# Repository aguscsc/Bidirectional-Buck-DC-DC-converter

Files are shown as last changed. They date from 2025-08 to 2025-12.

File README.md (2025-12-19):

# Bidirectional Buck DC-DC Converter

This repository documents the design and implementation of a **bidirectional DC-DC converter**.  
The system can operate in both **buck mode** (step-down) and **boost mode** (step-up), enabling power flow in both directions.  

---
## Software used
- **Simulation**
  
   Multisim, Ltspice and MATLAB/Simulink
   coil64
- **PCB**
  
   Kicad
## 📐 Specifications
- **Switching frequency**: 60 kHz  
- **Maximum power**: 5 W  

### Buck Mode
- $V_{in, min} = 23V$  
- $V_{out, max} = 14V$  

### Boost Mode
- $V_{in, min} = 12V$  
- $V_{out, max} = 27V$  

---

## 🔌 Topology
The selected topology is based on a **bidirectional synchronous buck/boost converter**.  
Diagram (preliminary):  

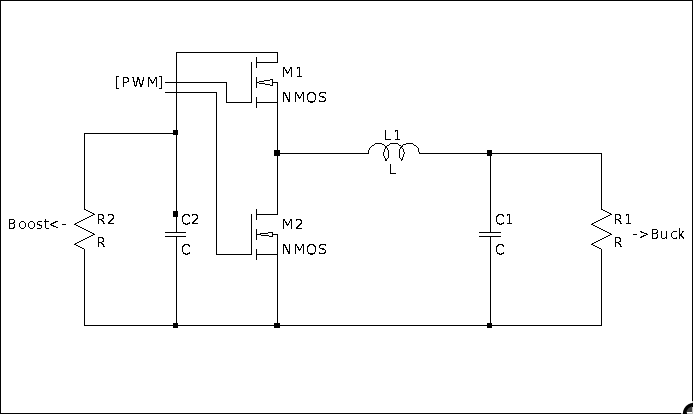
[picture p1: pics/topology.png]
Topology


---

## 📊 Design Parameters
### Inductor
- To be dimensioned based on:  
 $L = \frac{V_L \cdot D}{\Delta I_L \cdot f_s}$
  where:
  - \( $V_L$ \) = inductor voltage  
  - \( $D$ \) = duty cycle  
  - \( $\Delta I_L$ \) = current ripple (≈ $30$% of \( $I_{L,max}$ \))  
  - \( $f_s$ \) = switching frequency
  
   $I_{sat} = \frac{B_{sat}\cdot l}{\mu_{0}\cdot \mu_{r}\cdot N}$
  Where:
  - \($I_{sat}$\) = Saturation current
  - \($B_{sat}$\) = saturation flux density of the core material
  - \($l$\) = effective magnetic path length of the core
  - \($\mu_{0}$\) = permeability of a vacuum
  - \($\mu_{r}$\) = relative permeability of the material
  - \($N$\) = number of turns

Recommendation: use coil64 to check your calculations, research skin effect and how different AWG interact with the frequency you're using (https://en.wikipedia.org/wiki/Skin_effect).
### Capacitor
- To be dimensioned from capacitor current balance:
- buck
  $C = \frac{\Delta I_L}{\Delta V \cdot f_s\cdot 8}$
- boost
  $C = \frac{I_{out} \cdot D}{\Delta V \cdot f_s}$
  
  where:
  - \( $\Delta V$ \) = allowed voltage ripple  

## Schematic & PCB layout
<p>
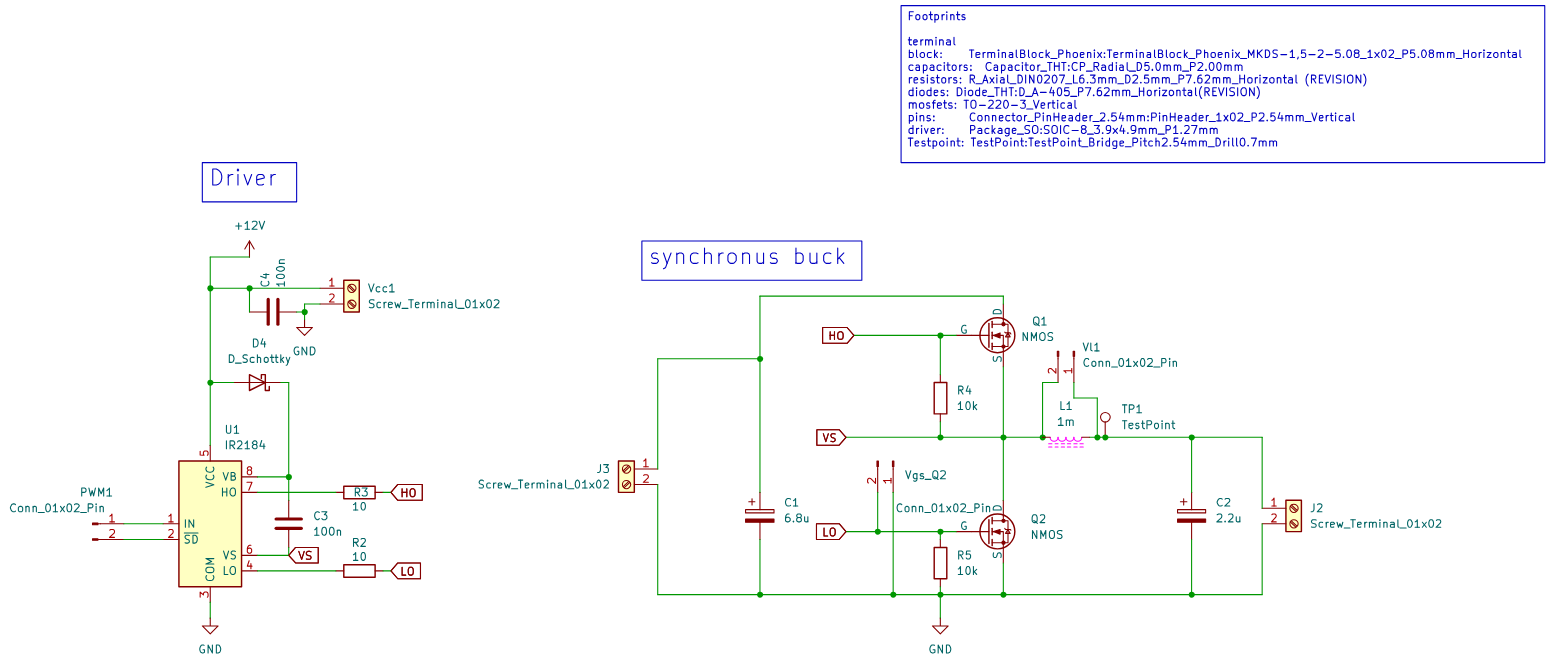
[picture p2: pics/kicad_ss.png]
schematic
  
</p>

<p>
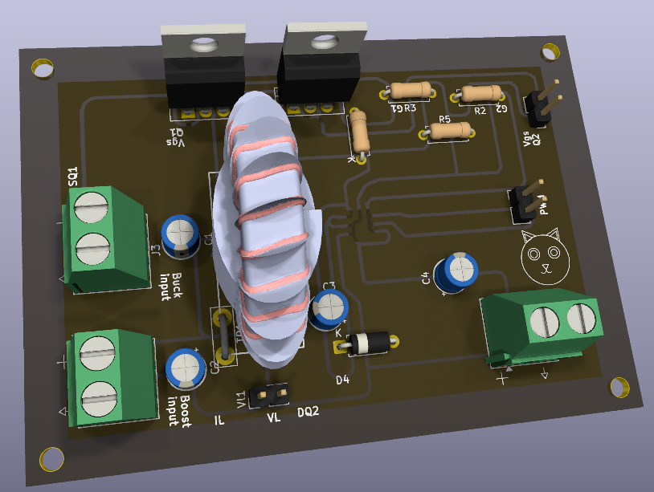
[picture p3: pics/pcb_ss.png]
PCB
  
</p>

---
# Prototyping 
This section breaks down the process of prototyping and testing, the pcb in the design directory contains all the measures necessary to ensure the converter is working properly (value of components can be adjusted to your needs).
## BOM:
- 2 electrolytic capacitors $6.8\mu F$ and $2.2\mu F$ 50V each. 
- 2 ceramic capacitors (100nF).
- core T106-26 + 9m of AWG 26 wire (higher permeability would also work if the saturation stays sensible).
- 2 IFRZ44N (great for prototyping and testing)
- IR2184 driver (it can generate both MOSFET signals)
- 2 10 ohm gate resistors 1W (it limits the gate current)
- 2 10k ohm pull-down resistor 1W (drains the gate source capacitance)
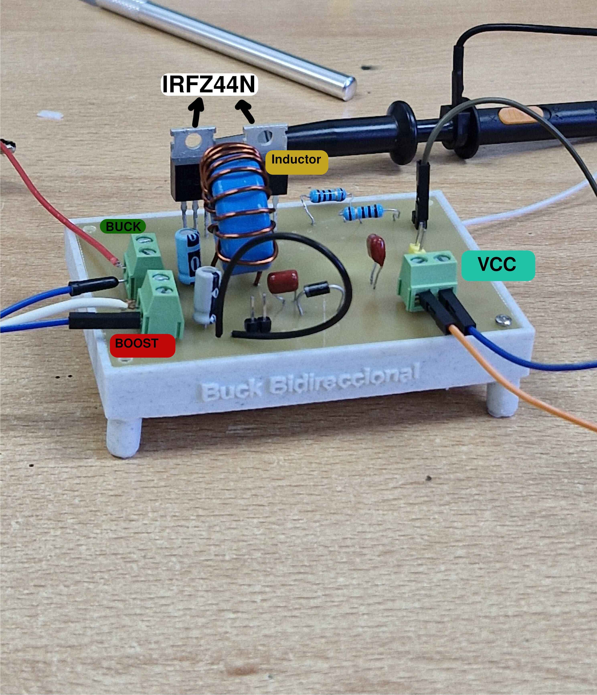
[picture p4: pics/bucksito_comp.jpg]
Prototype
 
## Measurements and tests
### switching
First, you ought to make sure the MOSFET are switching correctly. For this, turn on the pwm signal and your VCC source, then measure the gate-source pins of each MOSFET with an oscilloscope and make sure the signals are the complement of each other and respond to the change in duty. Aditionally, you should measure the gate current to ensure it is not exceeding the drivers capacity.
<p>
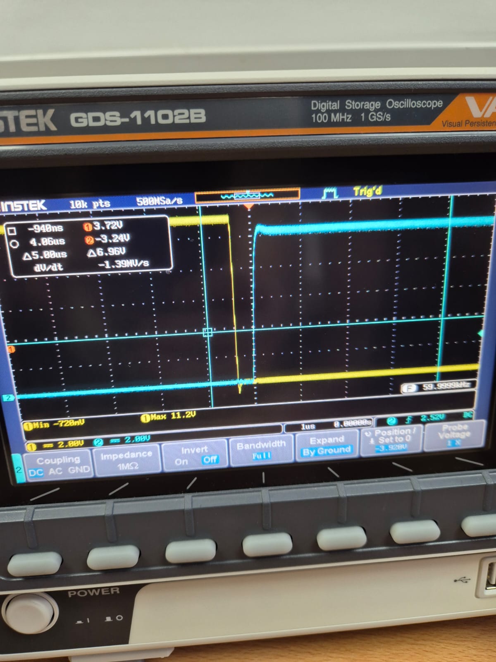
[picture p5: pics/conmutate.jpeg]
switching
  
</p>

### Powering the circuit
Check the waveforms of the inductor current and output voltage, ideally you should be looking at two saw-like waves with minimal ripple.
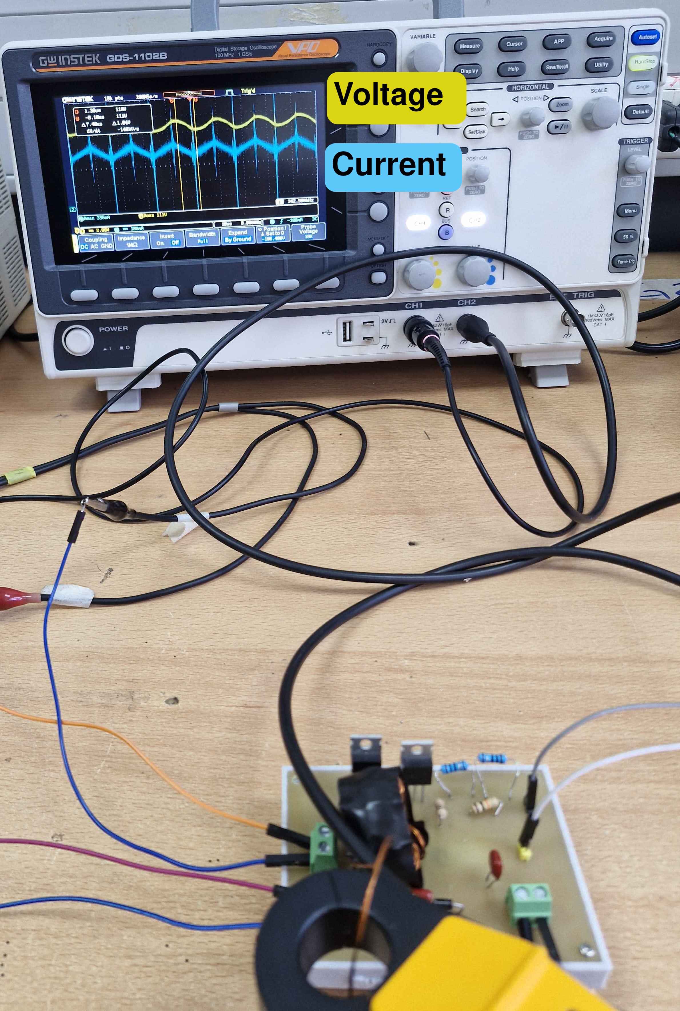
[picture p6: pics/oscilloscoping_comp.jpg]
testing

Once you have ensured the inductor current and the output voltage have satisfied your needs you can proceed to measure the converters effiency for each mode.

Note: if you struggle achieving the voltage ripple required, considering soldering ceramic capacitors parallel to your current ones.
### Efficiency 
**BUCK** R = $39.8$

| Duty | $V_{in}$ | $I_{in}$ | $V_{out}$ | $P_{in}$ | $P_{out}$ | Efficiency |
|:----:|:---:|:---:|:---:|:---:|:---:|:---:|
| 35%  | 23 V | 0.06 A | 7.26 V | 1.38 W | 1.32 W | 96.4 % |
| 45%  | 23 V | 0.10 A | 9.45 V | 2.30 W | 2.24 W | 97.5 % |
| 55%  | 23 V | 0.16 A | 11.6 V | 3.68 W | 3.38 W | 91.8 % |
| 65%  | 23 V | 0.22 A | 13.78 V | 5.06 W | 4.77 W | 94.3 % |

**BOOST** R = $142.2$

| Duty | $V_{in}$ | $I_{in}$ | $V_{out}$ | $P_{in}$ | $P_{out}$ | Efficiency |
|:----:|:---:|:---:|:---:|:---:|:---:|:---:|
| 29.5%  | 12 V | 0.16 A | 16.34 V | 1.92 W | 1.87 W | 97.7 % |
| 39.5%  | 12 V | 0.21 A | 18.79 V | 2.52 W | 2.48 W | 98.5 % |
| 49.5%  | 12 V | 0.30 A | 22.11 V | 3.60 W | 3.43 W | 95.4 % |
| 59.5%  | 12 V | 0.46 A | 26.77 V | 5.52 W | 5.04 W | 91.3 % |

# PWM control
Previously, the pwm signal was generated with a waveform generator, for real applications this has to be implemented with a microcontroller, in this case we'll use a PIC32 to generate the pwm signal.
This section will cover the programming and testing of the control system and its integration with the power circuit.

## Prototyping

First the [Curiosity PIC32MZEF2](Datasheets/PIC32/Curiosity_PIC32MZEF2.0_Development_Board_Users_Guide_DS80005400A.pdf) board was used to program and debug the pic32, this board comes equipped with a PICKit on board 4 to program and the debug the microcontroller using [MPLABX](https://www.microchip.com/en-us/tools-resources/develop/mplab-x-ide).

To ensure the correct operation of the microcontroller, first it was configured to control the PWM signal via the analog to digital converter, mapping its input to duty cycle levels. The steps followed were:

```
+-----------------------+      +-----------------------+      +-----------------------+      +-----------------------+
|     Start: Create     |      |     Config Output     |----->|      Config Timer     |      |     End: Compile &    |
|  PWM Generation Code  |      |    Compare I/O Pins   |      |        Registers      |      |   Load Code to PIC32  |
+-----------------------+      +-----------------------+      +-----------------------+      +-----------------------+
            |                              ^                              |                              ^
            |                              |                              |                              |
            v                              |                              v                              |
+-----------------------+      +-----------------------+      +-----------------------+      +-----------------------+
|   Config Oscillator   |----->|     Config Output     |      |       Config the      |----->|     Init Remaining    |
|         & PLL         |      |     Compare Module    |      |           ADC         |      |    I/O & Peripherals  |
+-----------------------+      +-----------------------+      +-----------------------+      +-----------------------+
```
First, it is necessary to generate the system clock, to do this the POSC (primary Oscillator) was set to EC mode, generating a 12Mhz signal which was scaled using the PLL [data_sheets](/microcontroller/Datasheets), then feeding a voltage signal controlled with a potentiometer to the ADC the pwm signal was generated. 

Once peripherals were working as expected, a graphic interface was integrated to replace the potentiometer, allowing for control over the mode, duty and frequency at which the converter operated.

# Graphical Interface
To control the microcontroller used for the PWM signal, a graphical interface is designed, the criteria followed for the design were:

- Intuitive
- Easy to switch between modes
- Secure, it must limit human error as much as possible without harming the user's experience
- Use of non distracting colors
- It must have a visual representation of the signal and voltage output

To develop such interface the language chosen is Python, due to the presence of the library [Tkinter](https://docs.python.org/es/3/library/tkinter.html), which made the process a lot easier.

Here you can see the interface next to an example of a warning popup when going above the suggested operation point.
<p>
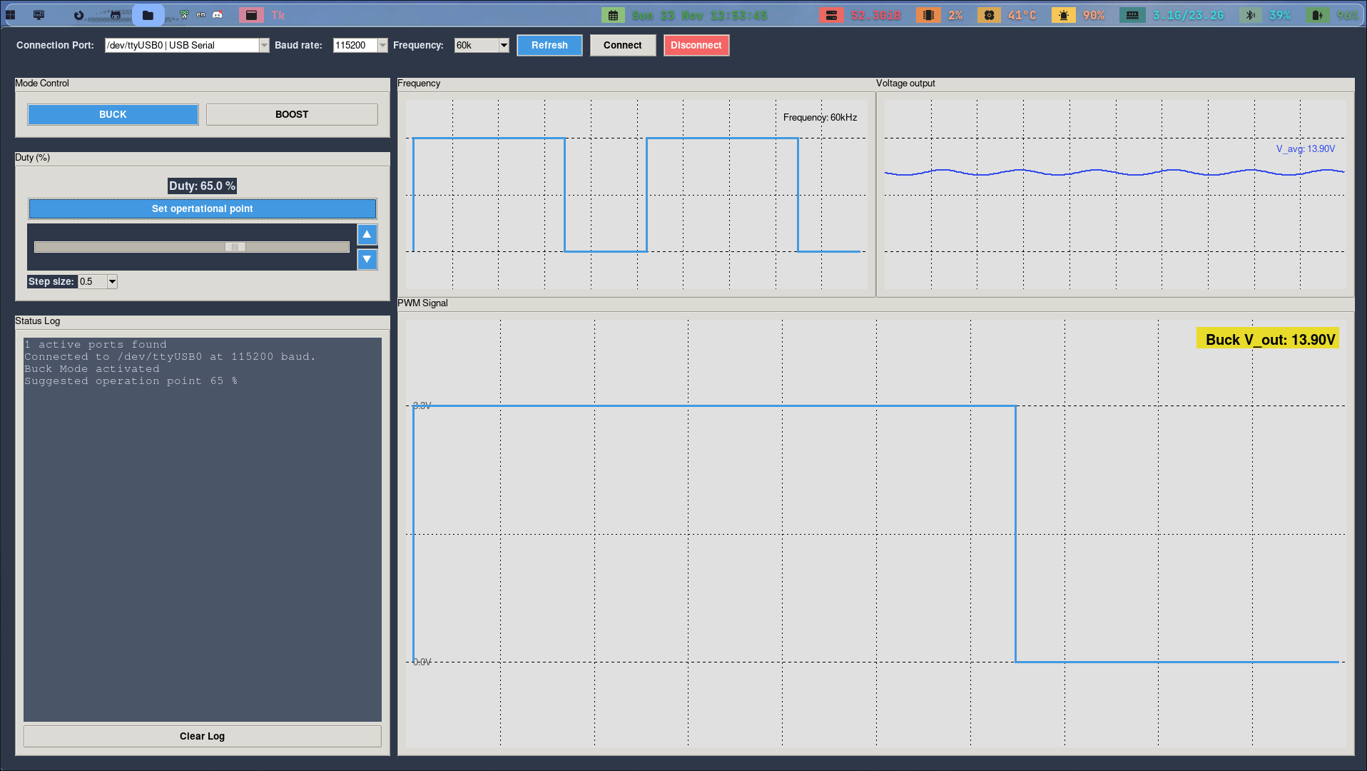
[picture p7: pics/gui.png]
gui
  
</p>

<p>
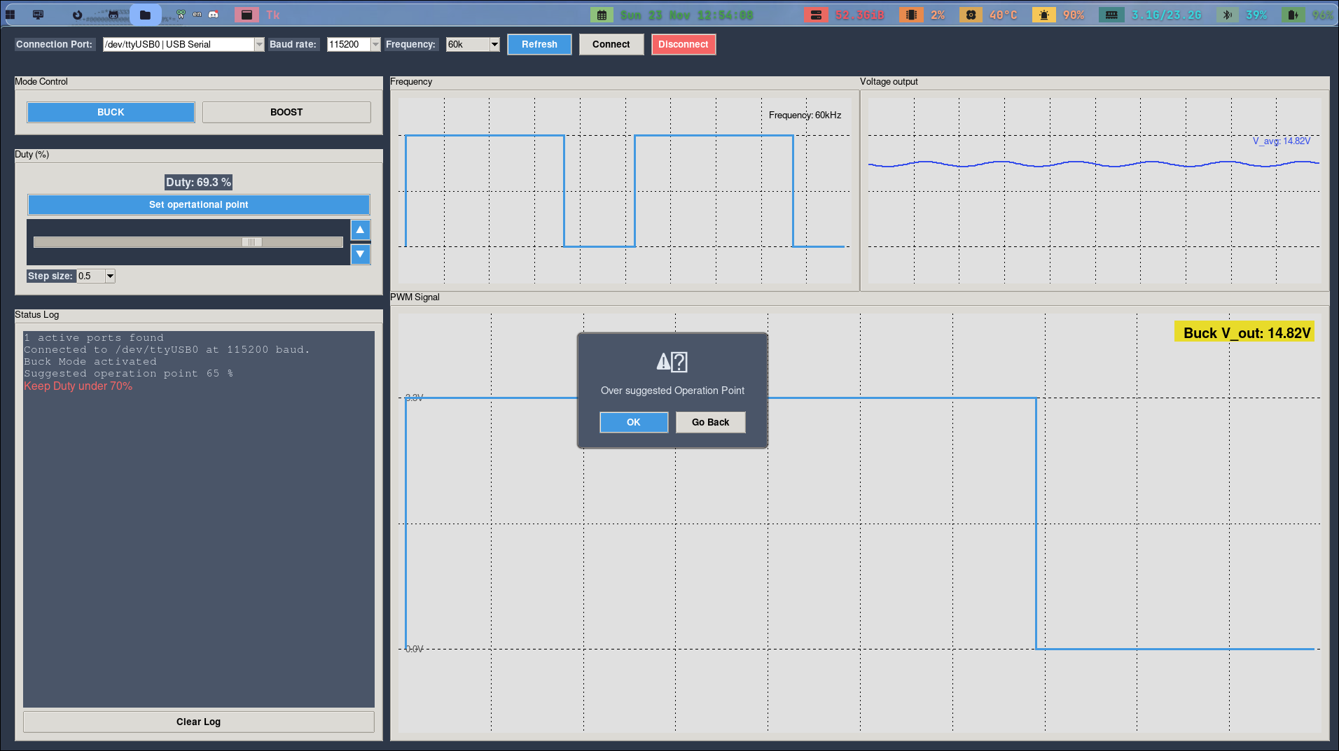
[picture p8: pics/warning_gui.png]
gui_warn
  
</p>

## How to use

### Executable
  
In [here](/microcontroller/graphic_interface/executables) you will find executables to run on your machine (Linux and Windows are currently supported).

### Manual

**1. Clone the repository**

```
git clone https://github.com/aguscsc/Bidirectional-Buck-DC-DC-converter.git
cd Bidirectional-Buck-DC-DC-converter/microcontroller/graphic_interface
```

**2. Dependencies**

```
pip install pyserial
```

**3. Run gui.py**

```
python gui.py
```

**Spanish version**

```
python es_gui.py
```

## Final PCB

The final PCB design consolidates all previously discussed subsystems into a single, compact board. It integrates the custom power stage, two voltage regulators to supply the gate driver and the PIC32 microcontroller, and a USB-C port to interface with the graphical control software.

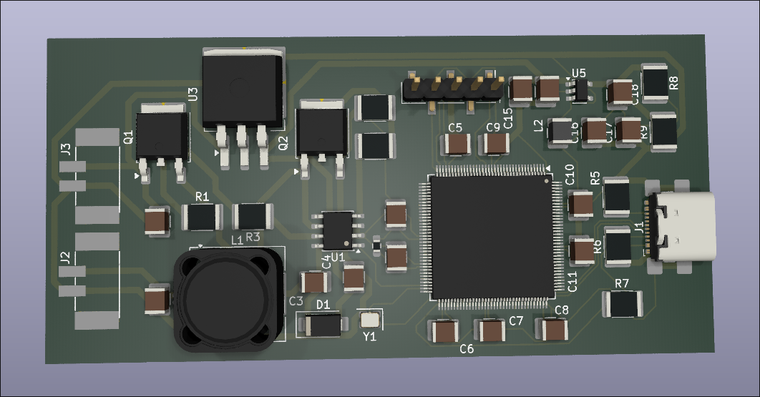
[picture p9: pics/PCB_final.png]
FINAL pcb


## ESP32 Telemetry & Sensing
To enable real-time monitoring, an **ESP32** module acts as a wireless telemetry unit. It senses input/output voltages and transmits data back to the Graphical Interface via Wi-Fi, allowing for remote performance tracking without physical probes.

### ⚡ Signal Conditioning (Voltage Divider)
The ESP32 GPIOs are not 5V tolerant and operate at a **3.3V logic level**. Since the converter handles up to 27V, voltage dividers are mandatory to scale the signals into the ADC's linear range ($100\text{mV}$ to $2.45\text{V}$ at $12\text{dB}$ attenuation).

The scaling follows the voltage divider formula:

$$V_{adc} = V_{out} \cdot \left( \frac{R_2}{R_1 + R_2} \right)$$

**Recommended Resistor Values:**
| Target Rail | Max Voltage | $R_1$ (Source) | $R_2$ (GND) | Divider Ratio | Max $V_{adc}$ |
| :--- | :--- | :--- | :--- | :--- | :--- |
| **Buck Output** | 14V | $47\text{k}\Omega$ | $10\text{k}\Omega$ | $0.175$ | $2.45\text{V}$ |
| **Boost Output** | 27V | $100\text{k}\Omega$ | $10\text{k}\Omega$ | $0.091$ | $2.45\text{V}$ |

> [!WARNING]
> Always verify the divider output with a multimeter before connecting to the ESP32. Overvoltage will permanently damage the SoC.

### 🌐 Wireless Protocol: UDP
We implemented the **UDP (User Datagram Protocol)** for data transmission:
* **Low Latency:** Unlike TCP, UDP does not require a handshake, making it ideal for high-frequency telemetry updates.
* **Efficiency:** Smaller packet overhead reduces the power consumption and processing time of the ESP32.

### 🛠️ Software Configuration (ESP-IDF)
The firmware is built using the **ESP-IDF v5.x** framework. To integrate it with your local network, modify the constants in `main/main.c`:

```c
// --- USER CONFIGURATION ---
#define WIFI_SSID      "Your_SSID"
#define WIFI_PASS      "Your_Password"
#define PC_IP_ADDR     "192.168.1.XX" // Your PC's local IP
#define PORT           3333           // Must match GUI port
---

**Deployment:**

1. Connect the ESP32 via USB.
2. Initialize the environment: `. $HOME/esp/esp-idf/export.sh`
3. Build and flash:
```bash
idf.py build flash monitor

```
### ESP32 PCB

Additionally a pcb was desgined to use the telemetry ssitem as an add-on to the converter

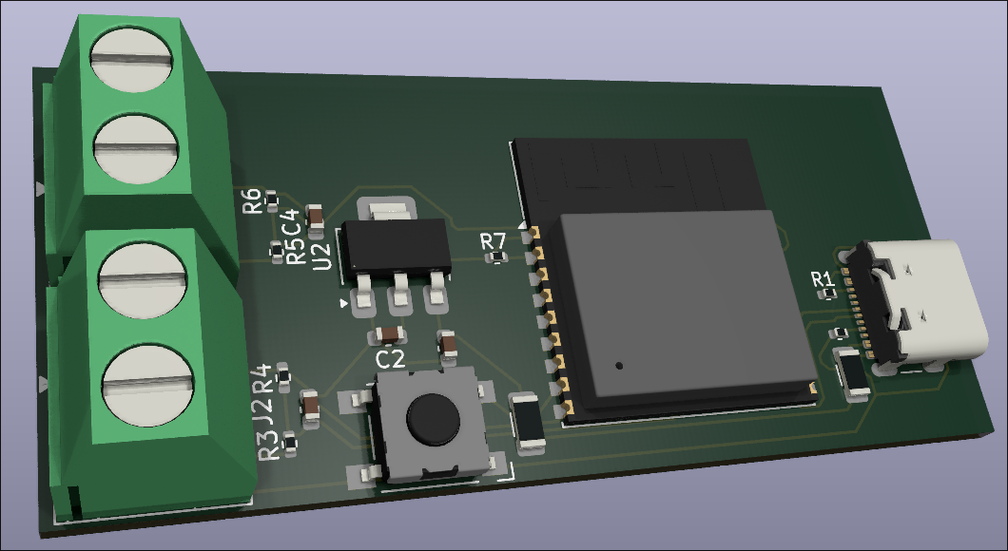
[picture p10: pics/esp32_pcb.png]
esp pcb


---
## 👥 Collaborators
- **[Agustín Torres](https://github.com/aguscsc)**  
- **[Ignacio Cerda](https://github.com/LovesCharlie)**  
- **[Gian Luca Barbagelata](https://github.com/Yian-n)**  

---

## 📚 References
-   Mohan – Power Electronics, Cap. 7
-   Erickson – Fundamentals of Power Electronics, Cap. 3
-   Power Electronics: Converters, Applications, and Design” – Ned Mohan
-   Electronica de Potencia, 1era edicion - Daniel W.Hart

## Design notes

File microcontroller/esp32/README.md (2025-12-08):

# ADC
The microcontroller ESP32 integrates a 12-bit SAR ADCs and supports measurements on 18 channels. The ULP-coprocessor in ESP32 is also designed to measure voltage, while operating in the sleep mode, which enables low-power consumptiun. The CPU can be wolen up by a threshold setting and/or via other triggers.

**DNL (differential nonlinearity) & INL (integral nonlinearity):**
The readings of the ESP32 can fluctuate up to 12 LSB from the actual value, this means 12 "steps" (about 10 to 15 milivolts). This can be aid cnnected to an external 100nF capacitor , dropping the fluctuation to only 7 LSB. Adittionally, instead of taking every measure, it is recommended to define a sample size and display the avg value of those readings.

**DIG vs RTC**
The dig controller reffers to the continous mode of the adc, taking up to 2 million samples per second, this fills the buffer incredibly fast, causing some delay when displaying the readings to the monitor.

The RTC operates in a One-shot mode, it captures 200 thousand samples per second, this is still really fast for a voltage sensor.

**Attenuation** 
The trade off to consider while choosing the attenuation value is range for accuracy. In this case, the best option is $Atten = 3$, yielding an effective range of 150 to 2450 milivolts and a max error of 60 milivolts

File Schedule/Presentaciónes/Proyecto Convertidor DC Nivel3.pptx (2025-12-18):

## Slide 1

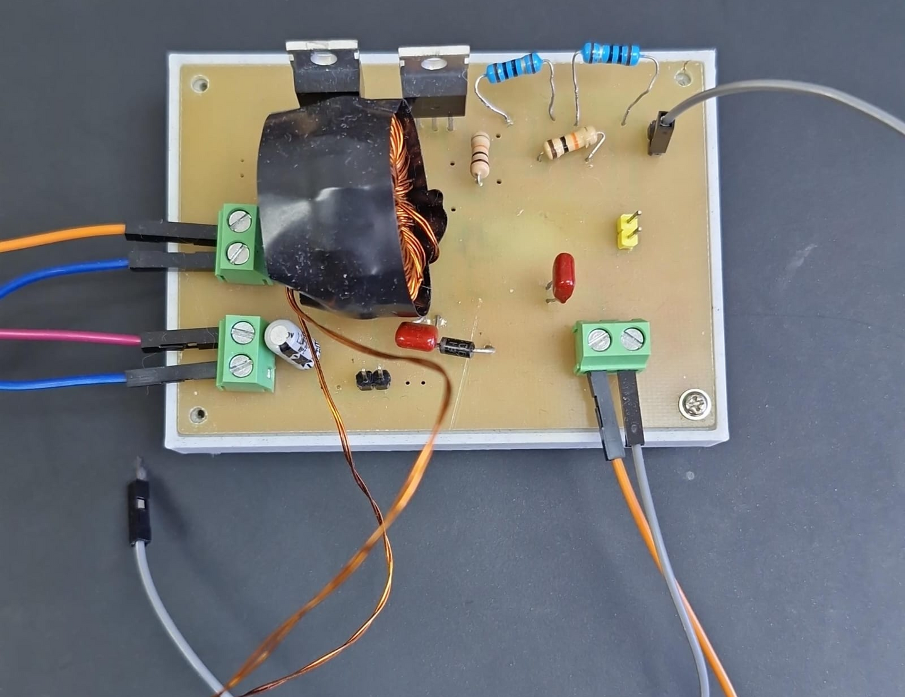
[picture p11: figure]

Grupo N°2
Gian Lucas Barbagelata
Agustín Torres Bobadilla
Ignacio Cerda Torres

PROPUESTA

Proyecto
Convertidor DC/DC
Buck Bidireccional

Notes: nacho

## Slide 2

ESQUEMA DE SOLUCIÓN A PROBLEMÁTICA

Parametros | Modo Buck | Modo Boost
Voltaje Continuo Minimo de Entrada | 23[Vdc] | 12[Vdc]
Voltaje Continuo Máximo de Salida | 14[Vdc] | 27[Vdc]
Frecuencia de conmutación | 60[KHz] | 60[KHz]
Tipo de switch | Mosfet | Mosfet
Potencia Máxima | 5[W] | 5[W]

Voltaje de entrada

Microcontrolador

Convertidor
de
Voltaje

Interfaz Grafica

Driver

Voltaje de salida

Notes: nacho

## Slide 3

PROPUESTA SOLUCIÓN

Convertidor DC/DC
Buck Bidireccional

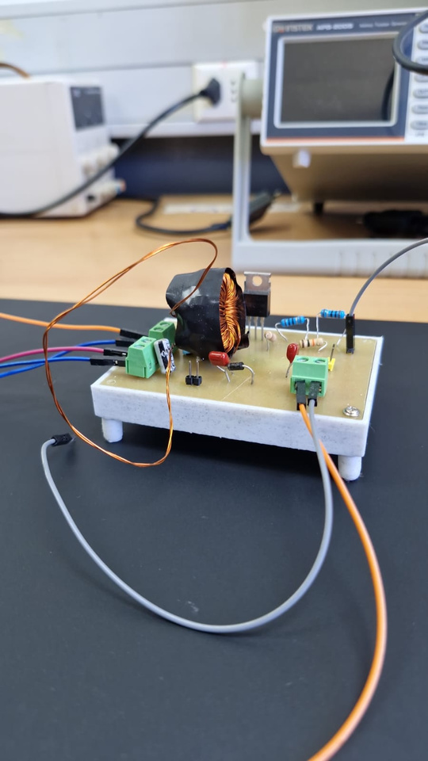
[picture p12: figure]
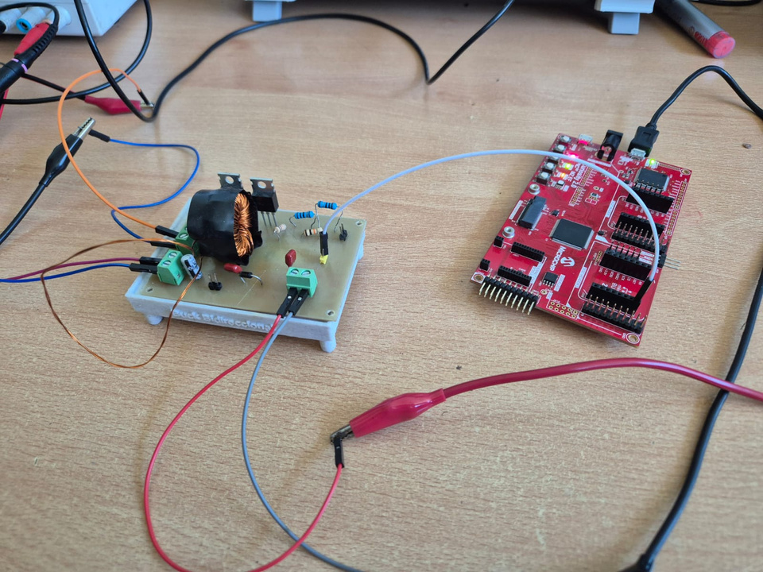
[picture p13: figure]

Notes: nacho

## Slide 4

FASES DEL PROYECTO

NIVEL 1

NIVEL 2

GENERADOR DE PULSOS PWM UTILIZANDO PIC32

  - Estudio del microcontrolador
  - Estudio del kit de desarrollo
  - Familiarizacion con lenguaje de programación
  - Programación de pulso PWM
  - Implementación y verificación del código
  - Prototipado y verificación

NIVEL 3

INTERFAZ GRÁFICA JUNTO CON MICROCONTROLADOR

  - Selección de plataforma para diseño de interfaz
  - Programación interfaz gráfica
  - Pruebas interfaz gráfica con microcontrolador
  - Prueba con conexiones del microcontrolador y driver a circuito
  - Realizar pruebas y mediciones

PROTORIPO CONVERTIDOR DC/DC BUCK BIDIRECCIONAL

  - Estudio de topología
  - Diseño de circuito y simulación
  - Listado de componentes
  - Seleccion y estudio de drivers
  - Diseño del driver
  - Diseño e implementación de PCB
  - Prototipado y verificación
  - Resultados

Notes: nacho

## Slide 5

INTERFAZ GRÁFICA

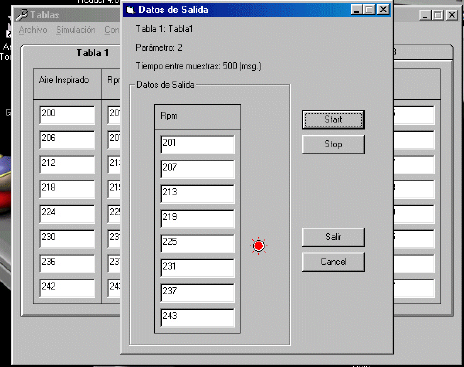
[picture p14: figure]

Sistema visual en donde interactua el usuario con tal de controlar ciertos parametros de manera más intuitiva y sencilla.
Posee:
  - Botones
  - Menus
  - Gráficos
  - Ventanas

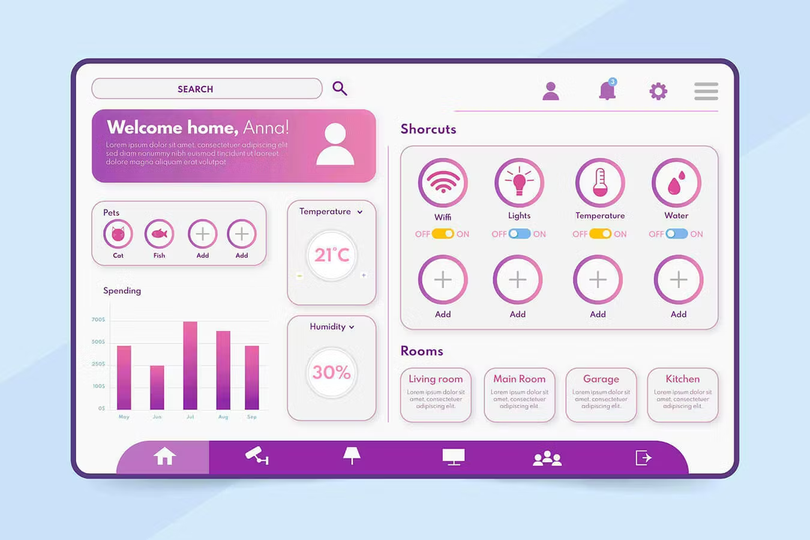
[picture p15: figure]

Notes: nacho

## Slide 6

PROTOCOLOS DE COMUNICACION

Protocolo USB:
  - Utiliza una arquitectura Maestro-Esclavo (Host-Client) asimétrica.
  - USB 2.0 High-Speed 480Mbits/s
  - Emplea Señalización Diferencial a través de un par trenzado de cables (D+ y D-).
  - Transferencia “Bulk”
Protocolo UART:
  - Comunicacion serial, punto-punto y Full-Duplex
  - El sistema depende del Baud Rate para sincronizar datos.
  - Comunicación Crossover

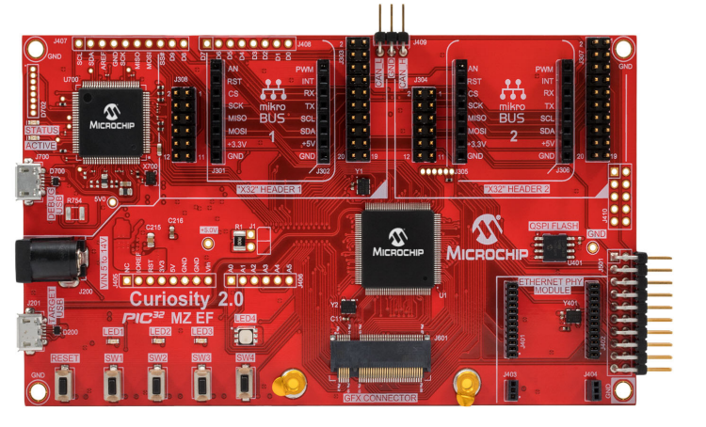
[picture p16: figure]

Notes: nacho

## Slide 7

DESARROLLO

Sistema operativo:
  - Linux 6.17.7-arch1-1
  - Windows 11
Editor de texto:
  - nvim
  - visual studio
Lenguaje:
  - Python 3.13.7
Control de versiones:
  - Git/Github

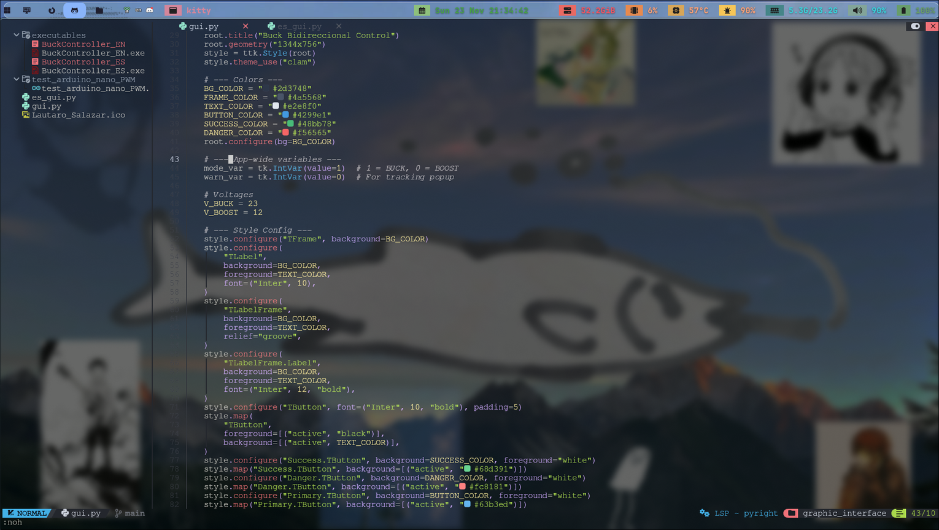
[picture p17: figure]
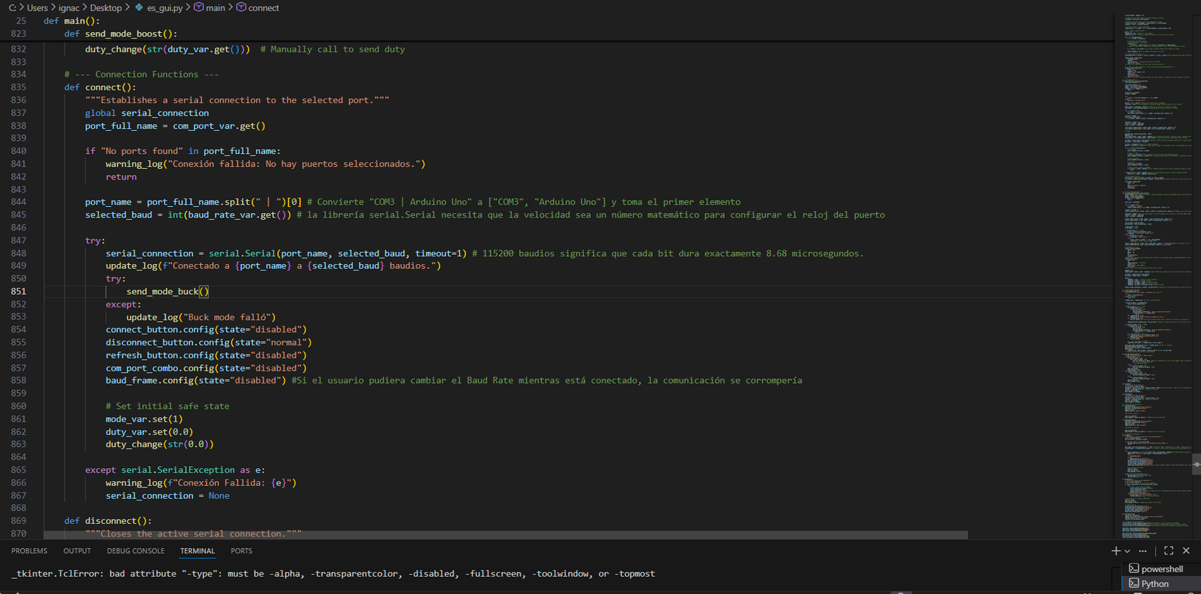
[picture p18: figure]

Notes: agu

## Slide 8

TKINTER

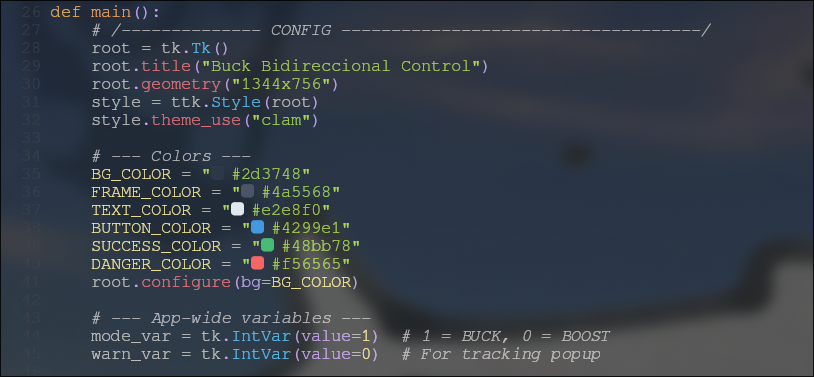
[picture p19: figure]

TKINTER:
  - Librería, python wrapper de Tcl/Tk
TTK:
  - Submódulo de la librería tkinter, con temas más modernos

s

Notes: agu

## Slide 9

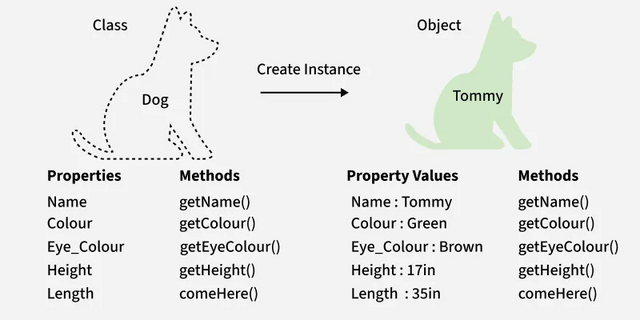
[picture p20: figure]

OBJETOS

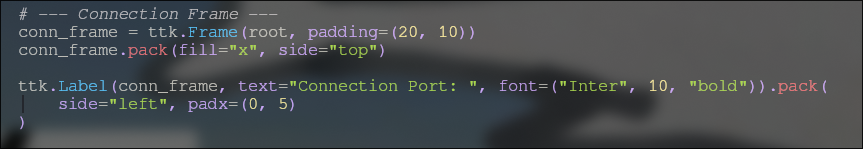
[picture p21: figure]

Frames:
  - Los frames “sujetan” objetos dentro
Botones
  - los botones llaman comandos
al ser presionados
ComboBox
  - Permiten esoger opciones

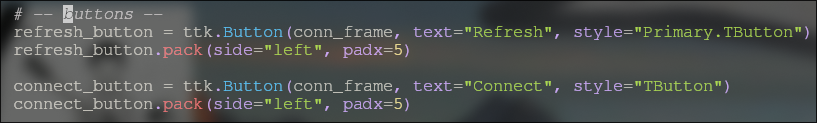
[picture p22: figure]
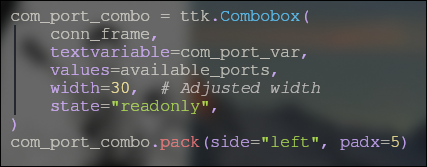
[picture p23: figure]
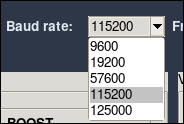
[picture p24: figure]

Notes: nacho

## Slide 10

CONEXIONES

Función send2controller:
  - Envío de información de frecuencia y ciclo de trabajo hacia el PIC32
Función Connect y Disconnect:
  - Se configuran los puertos, junto con la velocidad de transmision de datos y la seguridad

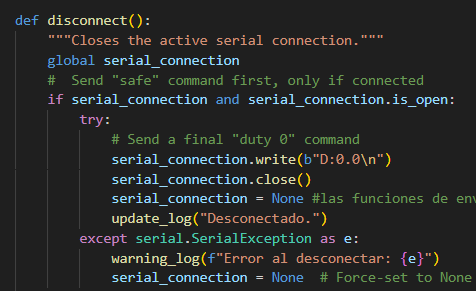
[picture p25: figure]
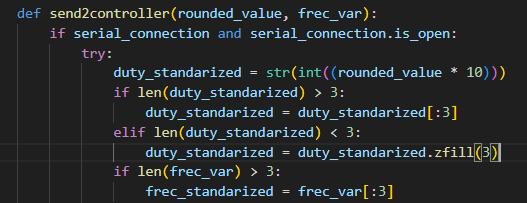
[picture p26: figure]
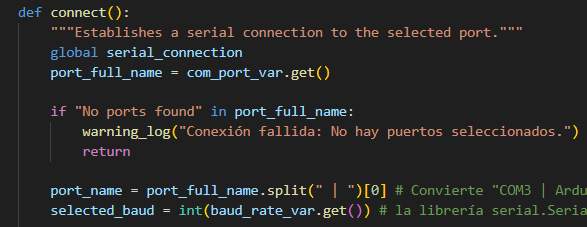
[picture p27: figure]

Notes: agu

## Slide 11

CÓMO UTILIZAR

Compatibilidad:
  - Microsoft Windows 10 o superior
  - Linux
Enlace de descarga:
  - descarga (https://github.com/aguscsc/Bidirectional-Buck-DC-DC-converter/tree/main/microcontroller/graphic_interface/executables)

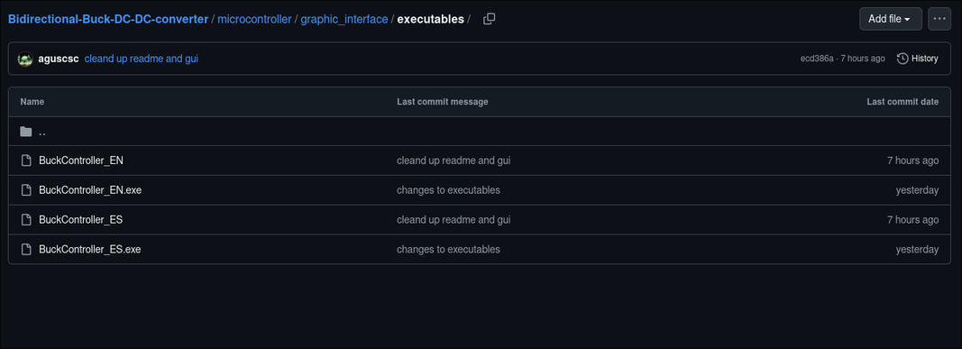
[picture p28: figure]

Descargar el ejecutable

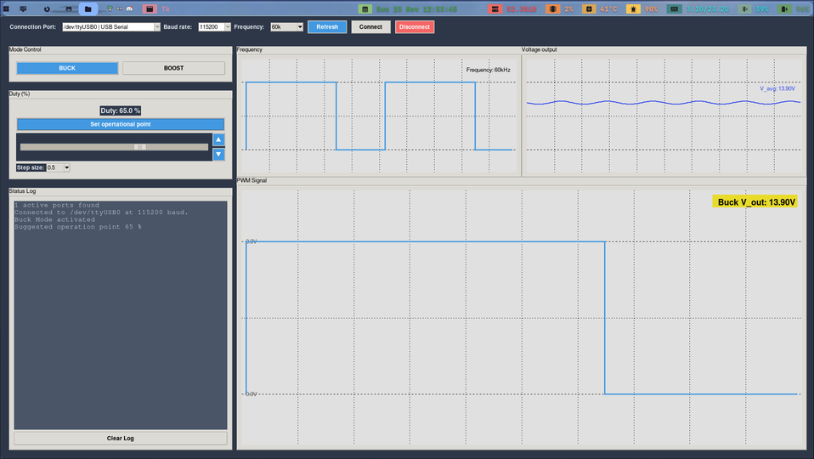
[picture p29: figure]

Usar

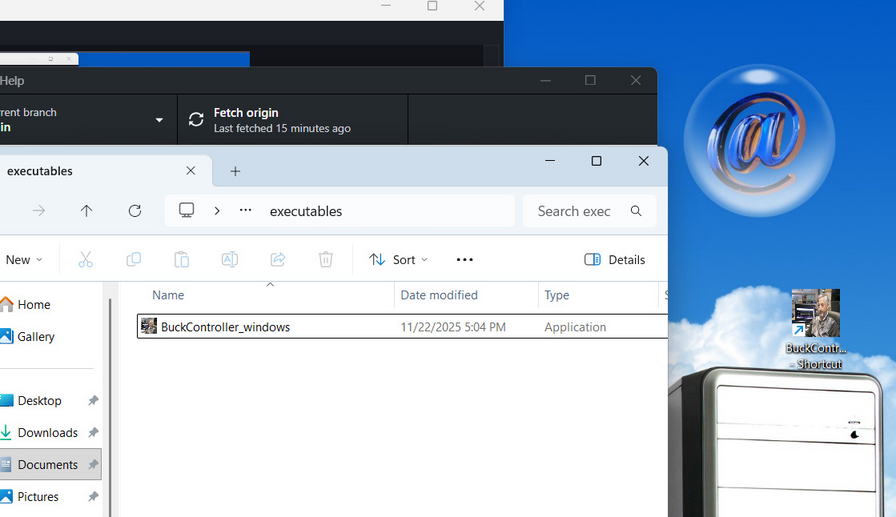
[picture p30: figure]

Ejecutar

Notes: nacho

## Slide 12

Configuracion de el micro

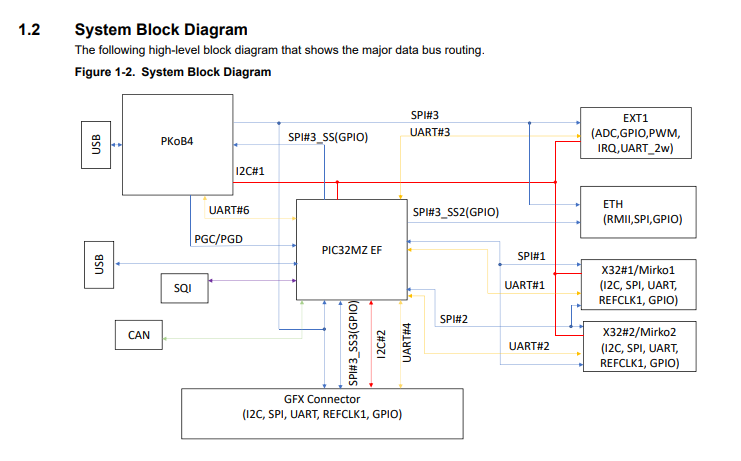
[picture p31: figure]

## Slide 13

Configuracion de el micro

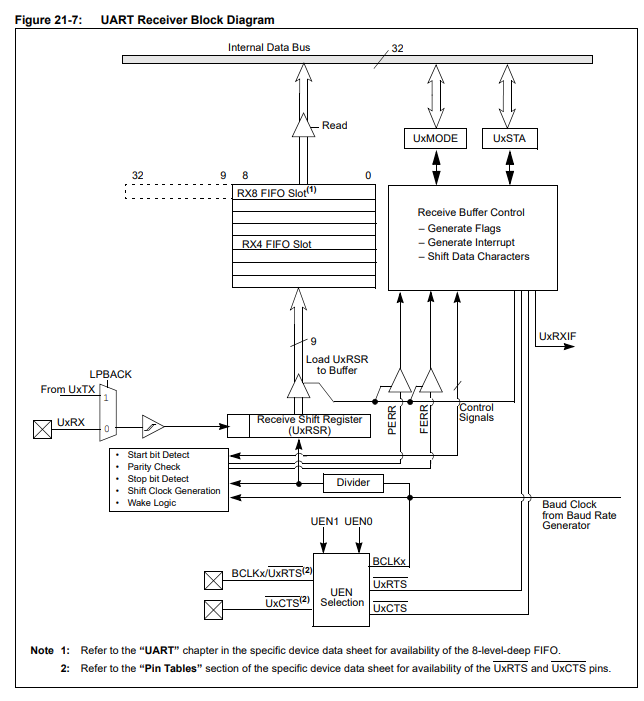
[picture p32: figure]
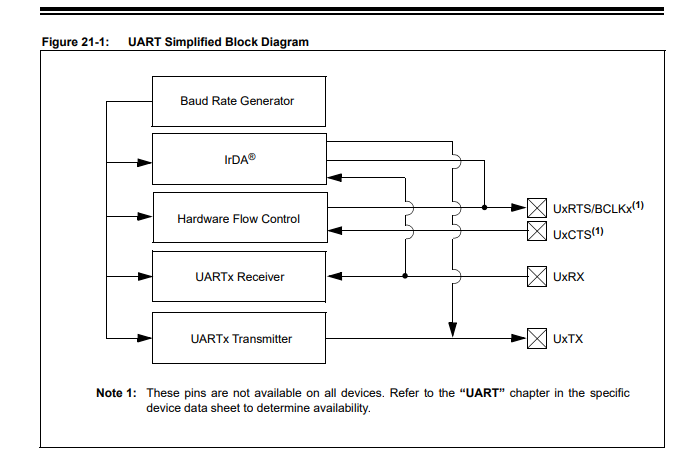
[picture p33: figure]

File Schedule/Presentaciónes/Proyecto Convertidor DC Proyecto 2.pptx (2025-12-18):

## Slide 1


Grupo N°2
Gian Lucas Barbagelata
Agustín Torres Bobadilla
Ignacio Cerda Torres

Proyecto 2
Monitoreo de señales con un Microcontrolador ESP32

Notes: nacho

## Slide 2

ESPECIFICACIONES Y PROBLEMATICA

PROYECTO 1

PROYECTO 2

VOLTAJE DE ENTRADA

VOLTAJE DE ENTRADA

PIC32

INTERFAZ GRAFICA 1

CONVERTIDOR DC/DC BUCK BIDIRECCIONAL

PIC32

INTERFAZ GRAFICA 2

CONVERTIDOR DC/DC BUCK BIDIRECCIONAL

VOLTAJE DE SALIDA

ESP32

VOLTAJE DE SALIDA

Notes: nacho

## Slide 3

PLANIFICACIÓN DEL PROYECTO

NIVEL 1

MICROCONTROLADOR ESP32:
  - ESTUDIO DEL MICROCONTROLADOR
  - FAMILIARIZACION CON EL KIT DE DESARROLLO
  - PROGRAMACION DE MONITOREO REMOTO
  - IMPLEMENTACION DE CODIGO

NIVEL 2

MONITOREO OCUPANDO INTERFAZ GRÁFICA:
  - IMPLEMENTACION DE CODIGO EN CONJUNTO DE ITERFAZ GRAFICA

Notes: nacho

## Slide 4

PLANIFICACIÓN DEL PROYECTO

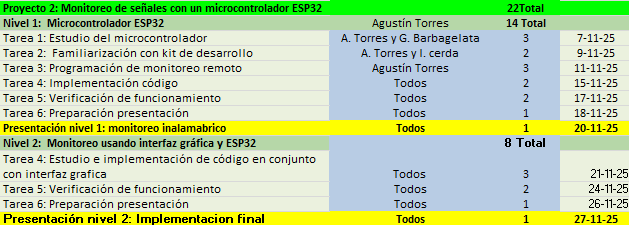
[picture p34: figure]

Duración estimada del proyecto 2: 22 días
Duración real del proyecto 2: 40 días

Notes: nacho

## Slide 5

PROPUESTA SOLUCIÓN:NIVEL1

ESP32 DevKit V1


USO DE PINES:
  - GPIO 34 Y GPIO 35(VDET)
  - ESTRATEGIA DE CONVERSIÓN ADC1
  - RESOLUCIÓN DE 12-BIT

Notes: El ESP32 actúa como el Sistema de Adquisición de Datos y Telemetría (DAQ) del proyecto. Su función principal es digitalizar el comportamiento físico del convertidor en tiempo real para hacerlo visible y comprensible para el usuario a través de una interfaz inalámbrica
Gracias a su módulo Wi-Fi integrado, crea una barrera de seguridad. Permite monitorear el estado del sistema desde una computadora o celular sin contacto físico con la placa de alta potencia

El ESP32 nos ofrece 4 veces más resolución que un microcontrolador estándar de 10 bits

Estos pines son arquitectónicamente de Solo Entrada. Esto significa que están dedicados exclusivamente a sensar el voltaje y carecen de la capacidad física para inyectar voltaje o corriente de retorno hacia el convertidor.(VDET= voltage detect)

El ADC1bv se define como la unidad de conversión analógica dedicada. Significa que este bloque de hardware es exclusivo para tus sensores y no comparte recursos con el sistema de comunicaciones inalámbricas, garantizando que medir voltaje y enviar datos por Wi-Fi puedan ocurrir al mismo tiempo

Resolucion de 12 bit= capacidad de discretización del sistema

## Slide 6

PROPUESTA SOLUCIÓN:NIVEL1

Módulo de Comunicación y Procesamiento: ESP-WROOM-32


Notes: nacho

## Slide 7

PROPUESTA SOLUCIÓN:NIVEL1

Módulo de Comunicación y Procesamiento: ESP-WROOM-32


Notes: nacho

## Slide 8

PROPUESTA SOLUCIÓN:NIVEL1

Entorno de programacion


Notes: nacho

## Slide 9

PROPUESTA SOLUCIÓN:NIVEL1

DIVISORES DE VOLTAJE


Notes: nacho

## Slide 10

PROPUESTA SOLUCIÓN:NIVEL1

SIMULACION DIVISORES DE VOLTAJE

MODO BUCK

MODO BOOST


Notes: nacho

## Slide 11

PROPUESTA SOLUCIÓN:NIVEL 1

Comunicación Inalámbrica

Características:
  - Rápido
  - Constante
  - Liviano, header de sólo 8 bytes


Wifi

ESP32


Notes: nacho

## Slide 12

PROPUESTA SOLUCIÓN:NIVEL 1

Código en ESP32


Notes: nacho

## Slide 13

PROPUESTA SOLUCIÓN:NIVEL 1

Código en ESP32


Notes: nacho

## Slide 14

PROPUESTA SOLUCIÓN:NIVEL 1

Código en ESP32


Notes: nacho

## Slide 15

PROPUESTA SOLUCIÓN:NIVEL 2

Implementación


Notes: nacho

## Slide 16

PROPUESTA SOLUCIÓN:NIVEL 2

Interfaz con ESP32


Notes: nacho

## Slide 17

GRACIAS POR SU ATENCIÓN

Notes: nacho

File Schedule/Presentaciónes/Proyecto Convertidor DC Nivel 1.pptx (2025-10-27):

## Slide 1


Convertidor DC/DC Buck Bidireccional

Integrantes:

- Agustín Torres Bobadilla

- Gian Lucas Barbagelata

- Ignacio Cerda Torres

Grupo 2

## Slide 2

Especificaciones Técnicas del Convertidor

Se desea un aumento y/o disminución de voltaje continuo de entrada hacia alguna carga que se desee.

Parámetro | Caso Buck | Caso Boost
Voltaje Continuo Mínimo de Entrada | 23[Vdc] | 12[Vdc]
Voltaje Continuo Máximo de Salida | 14[Vdc] | 27[Vdc]
Frecuencia de conmutación | 60KHz | 60KHz
Potencia Máxima | 5[W] | 5[W]
Tipo de switch | MOSFET | MOSFET

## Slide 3

Esquematico de solución

Voltaje de Entrada Continuo.

VOLTAJE DE ENTRADA:
Fuente de energía en corriente continua (12 Vdc o 23 Vdc) que alimenta el sistema

CIRCUITO ELECTRICO CONMUTADO:
Permite aumentar o disminuir el voltaje según el modo de operación

CONTROL:
Define el modo de operación (Reductor o Elevador) y asegura un funcionamiento estable

CARGA:
Elemento que recibe la energía regulada

Circuito Electrico Conmutado

Control

Carga

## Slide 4

Nivel 1: Protoripado Convertidor DC/DC Buck Bidireccional

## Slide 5

Componentes a Utilizar

Componentes Pasivos:
- Inductor
- Capacitores
- Resistencias
- Diodos

Comprensión de los componentes pasivos: resistencias, inductores y condensadores

Componentes Activos:
- Mosfets
- Driver

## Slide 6

Componentes Pasivos

Inductor:

Capacitor:

Resistencia:

Diodo:

Icono de Inductor Generic Outline Color | Freepik
Capacitors | Free SVG

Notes: Inductor: Componente pasivo que almacena energía en un campo magnético cuando circula corriente a través de él. En el convertidor, es el elemento clave de transferencia de energía, ya que acumula y libera energía para realizar la conversión buck o boost.
Capacitor: Componente pasivo que almacena energía en un campo eléctrico entre dos placas conductoras separadas por un dieléctrico. Se usa como filtro de salida para reducir el rizado de voltaje y entregar una tensión más estable. El capacitor de salida actúa como un depósito de carga: absorbe el exceso de corriente cuando el inductor entrega más de lo que la carga necesita, y se descarga cuando el inductor entrega menos. De esta manera compensa las variaciones y mantiene un voltaje casi constante, reduciendo el rizado a un valor pequeño.
EJEMPLO: Imagina el voltaje como el nivel de agua en un tanque. El capacitor es como un pequeño depósito auxiliar que se llena y vacía rápido para mantener el nivel estable El flujo promedio de agua lo maneja la tubería grande (inductor), pero el depósito corrige las variaciones instantánea

Diodo: Un diodo Schottky se diferencia por tener una caída de tensión directa mucho menor, de 0.2 a 0.4 V, lo que reduce las pérdidas de conducción. Además, prácticamente no tiene tiempo de recuperación inversa, es decir, puede apagarse instantáneamente cuando pasa de estar en conducción a bloqueo, evitando corrientes inversas no deseadas. Estas dos características lo hacen especialmente eficiente en aplicaciones de alta frecuencia, como nuestro convertidor DC/DC.

con una caída de tensión muy baja debido a su estructura de unión metal-semiconductor, lo que lo hace adecuado para aplicaciones de alta velocidad y baja pérdida de energía en circuitos electrónicos.

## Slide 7

Componentes Activos

Mosfet:

Actua como switch que puede conmutar muy rapidamente en nuestro circuito

Driver:

Actua para manejar ambos mosfets del circuito

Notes: DRIVER: El driver garantiza que los MOSFETs trabajen de forma segura y eficiente porque entrega el voltaje de compuerta adecuado, permite manejar el MOSFET de alto lado mediante bootstrap, introduce dead-time para evitar cortocircuitos, y conmuta la compuerta con la velocidad correcta. De esta manera evita pérdidas innecesarias, sobrecalentamientos y fallas, asegurando la eficiencia y la confiabilidad del convertidor.
El driver es como el conductor de un auto: el MOSFET tiene la potencia, pero el driver decide cuándo acelerar y cuándo frenar. Además, evita errores como apretar dos pedales a la vez (dead-time), aplica la fuerza justa para que el motor rinda (Vgs correcto) y asegura que el vehículo avance de forma eficiente y segura.
Mosfet: metal-oxide-semiconductor field-effect transistorMetal Oxide Semiconductor Field-Effect Transistor Metal Oxide Semiconductor Field-Effect Transistor

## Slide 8

Propuesta a lo requerido

En este caso se seleccionó un Convertidor DC/DC Buck Bidireccional


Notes: El circuito bootstrap permite generar el voltaje necesario para activar el MOSFET de alto lado, ya que su terminal source (VS) no está fijo a tierra, sino que fluctúa entre 0 V y el voltaje de salida.
El capacitor bootstrap se carga cuando el MOSFET de bajo lado conduce, acumulando un voltaje aproximadamente igual a Vcc. Luego, cuando el driver necesita encender el MOSFET alto, ese capacitor se usa como una fuente temporal que eleva la compuerta unos 10–12 V por encima del nodo VS, permitiendo una conmutación correcta.
Si el capacitor bootstrap es demasiado pequeño, no podrá almacenar suficiente carga, y durante la conmutación el voltaje VB caerá antes de tiempo. Esto impediría que el MOSFET alto alcance el Vgs necesario para saturarse, generando conmutaciones incompletas, pérdidas y posible sobrecalentamiento.
El capacitor de bootstrap debe tener un valor adecuado para garantizar que QH se encienda correctamente y sin pérdidas excesivas; muy pequeño no carga suficiente, y muy grande provoca retardos y mayor disipación

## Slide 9

Principio de Funcionamiento del Convertidor

Modo Buck (Reductor)

Convierte un voltaje DC de entrada alto a un voltaje DC de salida más bajo. Por medio de elementos activos y pasivos.

Modo Boost (Elevador)

Eleva el voltaje DC de entrada a un nivel superior de voltaje DC a la salida.

La bidireccionalidad se logra mediante el uso de MOSFETs como interruptores controlables que pueden conducir corriente en ambas direcciones, permitiendo que el convertidor opere dinámicamente según las condiciones de la aplicación.

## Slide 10

Obtención de Valores Teóricos

Para el análisis del convertidor se consideraron las siguientes suposiciones:

Conservación de Energía

La potencia entregada por la fuente es igual a la potencia consumida por la carga, despreciando las pérdidas en los componentes ideales.

Análisis de la Corriente en el Inductor

Conducción Continua

La corriente en el inductor siempre será positiva, garantizando operación en modo de conducción continua (CCM).

Periodo de Conmutación

Cada interruptor se cierra durante un tiempo DT y permanece abierto durante (1-D)T, donde D es el ciclo de trabajo.

El comportamiento de la corriente en el inductor es fundamental para comprender el funcionamiento del convertidor. La siguiente imagen muestra la forma de onda característica:

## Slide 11

Análisis del Modo Buck

El análisis se divide en dos estados de conmutación que determinan el comportamiento del circuito:


Estado 1: MOSFET High ON, MOSFET Low OFF

Durante este intervalo (0 ≤ t ≤ DT), el MOSFET superior conduce conectando la entrada directamente al inductor.

Estado 2: MOSFET High OFF, MOSFET Low ON

En este período (DT ≤ t ≤ T), el MOSFET inferior conduce proporcionando un camino de circulación para la corriente del inductor.

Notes: Durante el apagado del MOSFET alto, la corriente del inductor sigue fluyendo en el mismo sentido: alimenta principalmente a la carga y, en menor medida, al capacitor que filtra el voltaje. Esa corriente luego retorna por el MOSFET de bajo lado hacia tierra, cerrando el lazo. El capacitor no reemplaza al inductor, solo estabiliza el voltaje de salida absorbiendo las variaciones.
La polaridad del voltaje del inductor se invierte(Estado 2 buck y boost) no para generar energía nueva, sino para que la corriente del inductor continúe fluyendo hacia la carga y el capacitor. Es la propiedad de los inductores: la corriente no cambia instantáneamente, y el inductor genera el voltaje necesario para mantenerla.

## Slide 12

Derivación del Ciclo de Trabajo - Modo Buck

En estado estacionario, la condición fundamental es que la corriente promedio en el inductor debe mantenerse constante. Esto significa que el cambio neto de corriente durante un período completo de conmutación debe ser cero:

De donde se obtiene la relación fundamental del convertidor Buck:

Cálculo de Parámetros de Corriente

Resistencia de Carga:

Corrientes Máxima y Mínima:

Estas expresiones permiten determinar la variación de corriente en el inductor, parámetro crítico para el diseño de los componentes pasivos y la evaluación del rizado de corriente.

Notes: D = 61% significa que el MOSFET de paso directo está conduciendo 61% del tiempo en cada ciclo de conmutación.
Durante ese tiempo, el inductor se carga desde la fuente. El resto del tiempo (39%), el inductor se descarga a través del MOSFET inverso o diodo, manteniendo la corriente hacia la carga.

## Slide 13

Diseño de Componentes - Modo Buck

Cálculo de la Inductancia

Inductancia de Diseño

Se selecciona un valor superior para proporcionar margen de seguridad:

Inductancia Mínima

Determina el valor mínimo necesario para mantener la operación en modo de conducción continua:

Cálculo del Capacitor de Salida

El capacitor de salida se dimensiona considerando el rizado de voltaje:

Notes: Si aumentas la inductancia :
ΔIL∝1/L⇒ripple de corriente disminuye
La corriente del inductor varía más lentamente, es decir, la forma de onda se vuelve más plana, con menos oscilación.
Ventajas:
Menor rizado → menor estrés en MOSFETs y condensadores.
Desventajas:
Inductor más grande y más costoso.
Respuesta dinámica más lenta ante cambios de carga.
El rizado de voltaje aparece porque la corriente del inductor no es constante y el capacitor tiene que compensar esas variaciones.
Si uso un capacitor más grande o conmuto más rápido, el capacitor tiene más capacidad de respuesta y el voltaje se mantiene más estable.
También, si el inductor tiene más inductancia, la corriente varía menos y el capacitor sufre menos rizado.

Cuando la corriente del inductor excede la corriente de la carga, el capacitor se carga, generando un pico positivo de corriente.
Cuando la corriente del inductor es menor que la corriente de la carga, el capacitor se descarga, generando un pico negativo de corriente.
Esto produce los picos alternantes que vemos en la corriente del capacitor: no transporta toda la corriente, solo la diferencia entre el inductor y la carga. La corriente alternante del capacitor genera picos de tensión sobre la ESR. Por eso, el ESR determina cuánto del ripple se refleja en la salida: un ESR bajo reduce los picos de tensión y estabiliza Vout, mientras que un ESR alto amplifica el ripple, aunque la corriente del capacitor siga siendo la misma

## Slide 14

Análisis del Modo Boost

El análisis se realiza mediante el estudio de los dos estados de conmutación complementarios:

Estado 1: MOSFET High OFF, Low ON

El inductor se carga desde la fuente de entrada, almacenando energía magnética. Durante este intervalo, el MOSFET inferior está conduciendo:

Estado 2: MOSFET High ON, Low OFF

La energía almacenada se transfiere a la carga junto con la energía de entrada. En este intervalo, el MOSFET superior conduce y se produce la transferencia de energía:

El principio fundamental del modo Boost radica en el almacenamiento temporal de energía en el campo magnético del inductor durante el primer estado, para luego liberarla sumándose a la energía de entrada durante el segundo estado, resultando en un voltaje de salida elevado.

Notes: La capacitancia interna gate–source (Cgs) se carga porque el driver necesita establecer un voltaje entre gate y source (Vgs).
Este voltaje genera un campo eléctrico que modula la conductividad del canal entre drain y source.
Cuando Vgs alcanza el nivel fijado por el driver, el MOSFET pasa al estado de conducción.
Por tanto, el driver carga la capacitancia del gate para crear y mantener el voltaje de compuerta necesario para controlar el MOSFET.

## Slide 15

Derivación del Ciclo de Trabajo - Modo Boost

Similar al análisis del modo Buck, en estado estacionario la corriente promedio del inductor debe permanecer constante.

La resistencia de carga mantiene la misma expresión que en el modo Buck, pero las corrientes máximas y mínimas tienen características diferentes debido a la topología:

El modo Boost presenta una relación inversa entre el ciclo de trabajo y la ganancia de voltaje:

Parámetros de Corriente en Modo Boost

Relación de Transformación

Despejando D se obtiene la expresión del ciclo de trabajo en función de los voltajes:

Ciclo de Trabajo

Resistencia de Carga:

Corrientes Extremas:

Característica importante: En el modo Boost, el ciclo de trabajo D debe ser siempre menor a 1 para evitar la operación en modo discontinuo y garantizar la estabilidad del convertidor. A medida que D se acerca a 1, la ganancia teórica tiende a infinito, pero las pérdidas reales limitan esta característica.

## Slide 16

Diseño de Componentes - Modo Boost

Especificaciones de Inductancia

Inductancia Mínima

Garantiza la operación en modo de conducción continua:

Cálculo del Capacitor de Salida

Inductancia de Diseño

Valor seleccionado con margen de seguridad para el diseño práctico:

El capacitor de salida es crítico en el modo Boost para mantener un voltaje estable durante los ciclos de conmutación:

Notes: Un corto en el capacitor desvía la corriente del inductor directamente hacia los MOSFETs, provocando picos de corriente que pueden dañarlos y dejando a la carga sin alimentación
Un cambio abrupto de carga provoca que el capacitor absorba o suministre la diferencia de corriente hasta que el inductor se ajuste, amortiguando la variación de Vout pero generando picos de corriente temporales más grandes

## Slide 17

Análisis Matemático de la Conexión del Gate

Configuración del Circuito Equivalente

Se establece el modelo equivalente considerando la resistencia de gate, la capacitancia parásita gate-source, y la fuente de alimentación del driver.

Aplicación de Leyes de Kirchhoff

Mediante la aplicación de la ley de tensiones de Kirchhoff en la malla que contiene Vcc, Rg, y Cgs, se obtiene la ecuación diferencial que gobierna el comportamiento temporal del sistema.

Con resistencia de gate

Sin resistencia de gate:


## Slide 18

Selección Óptima de la Resistencia de Gate

Análisis de Corriente

La corriente de gate determina directamente la velocidad de carga/descarga de las capacitancias parásitas. Valores menores de Rg incrementan la corriente, acelerando la conmutación pero aumentando las pérdidas dinámicas.

Selección de Resistencia:

Voltaje del Capacitor:


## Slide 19

Diseño y Verificación del Inductor de Potencia

- Radio externo: 26mm

- Radio interno: 14.4mm

- Altura: 10.7mm

- 15 vueltas al núcleo

Especificaciones del Núcleo

Análisis del Flujo Magnético

En el caso del reductor, el inductor almacena energía durante el tiempo de conducción del interruptor y la transfiere a la carga durante el tiempo de corte, manteniendo continuidad en la corriente de salida.

En el caso del elevador, el inductor se carga directamente de la fuente durante la conducción y transfiere energía amplificada a la carga durante el corte, requiriendo mayor inductancia para control de ripple.

Configuración Buck

Configuración Boost

Referencia técnica: https://resources.altium.com/es/p/ferrite-core-selection-and-design-decisions

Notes: DEltaB: variacion de flujo magnetico de conmutacion
Si sobrepasa el limite de saturacion, entonces se provocarán pérdida de inductancia, incremento rápido de corriente y posible daño al circuito.
Al haber saturacion, el flujo magnetico ya no crece proporcionalmente a la inductancia, por lo que la inductancia cae y( para un mismovoltaje aplicado) la variacion de la corriente en el tiempo aumenta.
La saturación del inductor reduce su inductancia efectiva, provocando un aumento rápido de la corriente y riesgo de daños en MOSFETs y aumento del ripple de salida.

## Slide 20

Parámetros de Diseño Calculados

Parámetros | Caso Buck | Caso Boost
Duty cycle (D) | 60.9% | 55.6%
Ripple de Voltaje | 1% | 1%
Ripple de corriente | 30% | 30%
Resistencia de la carga | 39.2[Ohm] | 145.8[Ohm]
Inductancia | 0.855[mH] | 0.889[mH]
Inductancia mínima | 0.1278[mH] | 0.1333[mH]
Corriente mínima en inductor | 0.304[A] | 0.354[A]
Corriente promedio | 0.357[A] | 0.417[A]
Corriente máxima en inductor | 0.411[A] | 0.479[A]
Capacitancia | 1.59[uF] | 6.35[uF]

Referencias Técnicas Importantes:

- Analog Devices - Selección de Ripple de Corriente en Inductores (https://www.analog.com/en/resources/technical-articles/selecting-the-right-inductor-current-ripple.html)

- Texas Instruments - Guía de Ripple de Voltaje (https://www.ti.com/lit/an/slva630a/slva630a.pdf)

- Referencia de Cálculos - https://www.google.com/url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 (https://www.google.com/url?rct=j&q=&esrc=s&cd=&opi=89978449)

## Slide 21

Especificaciones y Selección de Semiconductores

Tensión máxima mayor a 27V

El margen de seguridad en tensión debe considerar transitorios de conmutación, sobretensiones de línea, y variaciones de temperatura.

Corriente máxima a 1A

La capacidad de corriente debe incluir márgenes para corrientes de ripple, transitorios de arranque, y degradación térmica.

El package TO-220 ofrece excelente compromiso entre disipación térmica, facilidad de montaje, y disponibilidad comercial.

Disipación de Potencia Superior a 5W

Las pérdidas térmicas incluyen pérdidas por conducción, conmutación, y gate.

Encapsulado TO-220 Estándar

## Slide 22

Análisis del MOSFET IRFZ44N


49A

55V

110W

Características Eléctricas Principales

Tensión Drain-Source

Corriente Continua

Partes físicas del MOSFET

Disipación de Potencia

Ventajas Clave del IRFZ44N: Baja resistencia en conducción, capacitancias parásitas optimizadas, excelente capacidad de disipación térmica, disponibilidad comercial amplia,,

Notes: Seleccionamos el MOSFET IRFZ44N porque soporta tensiones de hasta 55 V, más que suficiente para nuestras condiciones de operación (23 V y 27 V). Además, entrega un margen de corriente muy superior a la requerida en nuestro convertidor de 5 W, con un Rds(on) bajo que mejora la eficiencia. Es un componente ampliamente disponible, económico y compatible con la frecuencia de conmutación de 60 kHz, lo que lo hace ideal para nuestro prototipo.

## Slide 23

Análisis de Potencia

Pérdidas en forma de calor


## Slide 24

Pérdidas por conducción


Pérdidas por conmutación

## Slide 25

Perdidas Resistencias Gate


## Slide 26

Resistencia de Inductor

Resistencia de Capacitores


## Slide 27

Pérdidas calculadas (python)


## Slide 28

Criterio de seleccion de driver

Para el convertidor DC/DC buck bidireccional, se requiere, un driver de half-bridge que cumpliera estos requisitos minimos:
- Configuración half-bridge: Control dependiente de MOSFETs (high/low side) para rectificación síncrona en modos buck/boost, con salidas complementarias (HO/LO).
- Dead-time: para evitar shoot-through y reducir pérdidas en conmutación rápida.
- Capacidad de drive: apto para tiempos de conmutación <1 µs, minimizando calentamiento y asegurando correcto funcionamiento en 60 kHz.
- Protecciones esenciales: UVLO en ambos canales, inmunidad a dV/dt y ruido, compatibilidad con lógica 3.3V/5V.
- Eficiencia y costo: Bajo consumo, paquete pequeño, y disponibilidad local en Chile.

Se inspecciono la guía de selección de drivers MOSFET de Microchip, sin embargo, muchos de estos estaban sobredimensionados para nuestra aplicación, lo que elevaría costos innecesarios, o, el factor principal, no estaban disponibles para compra directa en Chile.

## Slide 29

Driver IR2184

Ventajas

Razones de la elección

- Equilibrio entre rendimiento y costo para 5 W.
- Diseñado para convertidores síncronos, perfecto para buck bidireccional.
- Ampliamente disponible, y compatible con MOSFETs estándar.
- Simplifica diseño sin sobreespecificar, ideal para prototipos o producciones pequeñas.
- Usado especificamente para un convertidor buck sincrono por profecionales y generaciones anteriores

- Bootstrap para lado alto: Permite control de MOSFETs sin fuente aislada, reduciendo costos, es inmune a transientes dV/dt
- .Dead-time: Evita "shoot-through" con tiempo muerto (400-600 ns).
- Alta corriente de drive: 1.4 A source / 1.8 A sink, con tiempos de conmutación rápidos , minimizando pérdidas.
- Proteccion integrada: UVLO, garantizando fiabilidad ante variaciones de voltaje.
- Compatibilidad: Funciona con lógica 3.3 V/5 V, compatible con la señal del PIC a futuro, inmune a ruido, ideal para diseños compactos.

Referencia para eleccion de driver:
https://www.youtube.com/watch?v=W4i2FRZ8gXc&t=86s

Nota: este driver debe ser complementado con un módulo optoacoplador ya que no cuenta con aislación propia

Amazon.com: ACEIRMC 4pcs 1CH Optoacoplador PC817 1 canal de aislamiento de la placa de aislamiento Convertidor de voltaje Módulo adaptador 3.6-30V controlador fotoeléctrico aislado módulo (10pcs 1CH : Industrial y Científico

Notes: Elegimos el IR2184 porque nos permite controlar ambos MOSFETs del convertidor en configuración half-bridge. Este driver incorpora un circuito bootstrap para manejar el MOSFET de alto lado, dead-time integrado para evitar cortocircuitos, y es totalmente compatible con señales PWM estándar. De esta forma simplifica el diseño, asegura un funcionamiento robusto y cumple con los requerimientos de nuestro convertidor bidireccional.
Un retardo en el driver provoca que los MOSFETs no conmuten exactamente a tiempo, alterando los picos de corriente del inductor. Como el capacitor de salida compensa estas diferencias, sus picos también se ven afectados, aumentando el ripple y afectando la estabilidad de Vout.

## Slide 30

Características del Driver

Diagrama interno

Parámetros

Conexión circuito bootstrap


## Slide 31

Plano del circuito equivalente (Proteus)


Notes: Para prevenir armonicos de la red

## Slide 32

Grafico del voltaje de salida en modo Buck


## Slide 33

Grafico de la corriente de inductor en modo Buck


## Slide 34

Valores Obtenidos en simulación

Parametro | Deseado | Obtenido
Vo Buck | 14 [V] | 13.9 [V]
Vo Boost | 27 [V] | 26.5 [V]
iL avg Buck SS | 0.357 [A] | 0.33 [A]
iL avg Boost SS | 0.417 [A] | 0.41 [A]
Pmax Buck | 5 [W] | 4.865 [W] = 97,3% eff
Pmax Boost | 5 [W] | 4,77 [W] = 95,4% eff
Ripple Vo Buck | 1% | 0.7%
Ripple Vo Boost | 1% | 1.1%
Ripple iL Buck | 30% | 29%
Ripple iL Boost | 30% | 30.5 %
Capacitancias usadas (Buck/Boost) | 1.59/6.35 [uF] | 2.2/6.8 [uF]
Inductor usado (Buck/Boost) | 0.85/0.89 [mH] | 1 [mH]
Duty(Buck/Boost) | 60.9/55.6 % | 61/60 %

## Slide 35

Listado de Componentes

Componente | Cantidad | Valor | Valor de compra | Lugar de compra
Mosfet IRFZ44N | 4 | VDSmax=55V IDmax=49 A Tj=175°C | $6800 | ZAVA
Driver IR2184 | 2 | 8-Lead SOIC | $15450 | Mercado libre y Aliexpress
Resistencia 10k | 4 | 1W | --- | ---
Resistencia 10 | 2 | 1W | --- | ---
Resistencias de carga | 2 | 10W | --- | ---
Capacitores electrolíticos | 2 | 50V | --- | ---
Capacitores cerámicos | 2 | 50V | --- | ---
Diodos schottky(1N5819) | 1 | Vf=0.34 V IFmax=1A | $1200 | Mechatronic
Inductor | 1 | 1.054mH | --- | A mano

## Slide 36

PCB

Objetivos: Poder crear la base de conexiones para componentes del convertidor.
Tomando en consideración:
Agregar islas donde se pueda.
Accesibilidad para medir (Vgs, VL, IL, Ids, Vo e Io)

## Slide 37

KiCAD


Restricciones:
Mínimo grosor de Track: 0.5mm.
Margen de 5 mm.
Cálculo de grosor de Track: digikey_track_thickness (https://www.digikey.com/en/resources/conversion-calculators/conversion-calculator-pcb-trace-width)

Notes: El capacitor de salida debe colocarse lo más cerca posible del inductor y de los MOSFETs porque, durante la conmutación, por ese lazo circulan corrientes de alta frecuencia y alto valor instantáneo.
Si el capacitor está lejos, las pistas del circuito impreso introducen resistencia (R) y autoinductancia (L) parásitas, que generan caídas de tensión y picos de ruido (EMI).
Al mantener el capacitor muy próximo al inductor y a los MOSFETs, se reduce la longitud del lazo de corriente, se minimizan las pérdidas por impedancia parásita y se mejora la estabilidad del voltaje de salida, reduciendo el rizado y el ruido.

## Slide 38

3D VIEWER


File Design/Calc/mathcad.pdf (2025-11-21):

# Convertidor DC/DC Buck Bidireccional

Para la obtención de los valores de los componentes del circuito, se tomarán en consideración las siguientes especificaciones

Se tomó en cuenta el siguiente circuito para el análisis de componentes.

Especificaciones:
switches a usar: MOSFET
fc≔60000 [Hz]
P≔5 [W]
Caso 1: Modo Buck
VinBuck≔23[V]
VoBuck≔14 [V]
Caso 2: Modo Boost
VinBoost≔12 [V]
VoBoost≔27[V]

Primero se comenzará con el análisis del convertidor en Modo Buck, teniendo en cuenta las siguientes suposiciones para un cálculo claro.

Tomando en cuenta la siguiente disposición del circuito

El circuito opera en régimen permanente
La corriente en el inductor es siempre positiva. El valor del capacitor(C3) es muy grande y la tensión de salida se mantiene constante a una tensión Vo.
El periodo de conmutación es T. El interruptor estará cerrado un tiempo DT y estará abierto un
tiempo (1 — D)T.
Los componentes son ideales.
Se comenzará tomando el caso cuando el MOSFET 1 actúa como un switch cerrado y el MOSFET 2 como un switch abierto.

MOSFET 1 cerrado

Para el voltaje en el inductor
se tiene:

VL≔⎛⎝VinBuck-VoBuck⎞
⎠=9

Por definición se tiene de igual manera:

VL

((t))＝L ―d ―dt
iL

((t))

Como la derivada de la corriente es una constante positiva, la corriente aumenta linealmente

Forma de onda de voltaje de inductor y corriente del inductor Con :
Δt＝DT

――＝ ＝

ΔiL
Δt ――

ΔiL
DT ――――――

⎛⎝VinBuck-VoBuck⎞
⎠
L

Teniendo la variación de la corriente del inductor cuando el MOSFET 1 está cerrado como:

ΔiL_close≔――――――

⎛⎝VinBuck-VoBuck⎞
⎠
L

DT

Para el otro caso se obtendrá cuando el MOSFET 1 actúa como un switch abierto y el MOSFET 2 como un switch cerrado.

MOSFET 1 abierto

Cuando el switch está abierto el voltaje en el inductor pasa a ser el valor inverso de la salida de la carga.
VL≔-⎛⎝VoBuck⎞
⎠＝L | ―d | ―dt
iL

Despejando la derivada de la corriente tenemos que:

――＝

d
dt

iL ―――

-VoBuck
L

La derivada de la corriente en el inductor es una constante negativa y la corriente disminuye linealmente, como se puede apreciar en las formas de onda de corriente. Teniendo la variación de la corriente del inductor cuando el switch está abierto como:

――＝ | ＝

ΔiL
Δt ――――

ΔiL
((1- D)) | T | ―――

-VoBuck
L
Despejando Δi : L

ΔiL_open≔-――――――

((1- D)) T⋅VoBuck
L
En estado estacionario se requiere que la corriente en el inductor sea la misma al final que en el inicio, por lo que su variación neta en un periodo será cero.

ΔiL_open+ΔiL_close＝0

Remplazando cada variación de corriente se obtiene:

――――――+ | ＝
((D -1)) | T⋅VoBuck
L ――――――

⎛⎝VinBuck-VoBuck⎞
⎠
L

DT 0

Teniendo un ciclo de trabajo para el Modo Buck como:

DBuck≔―――=

VoBuck

VinBuck

0.609

Se puede observar que si el voltaje de entrada varía, el voltaje de salida
se puede ajustar con una adecuación del ciclo de trabajo.

Para obtener el valor de la carga se realiza un calculo con la potencia máxima permitida en la carga, teniendo el siguiente cálculo.

R≔――――=

⎛⎝VoBuck⎞
⎠

2
P
39.2 | Ω | Considerando un caso ideal en donde la potencia de
entrada es igual a la de salida

Ahora, para saber cual es la corriente máxima que puede aceptar el inductor y la corriente mínima para entrar en conducción continua. La corriente media en la bobina debe ser igual a la corriente media en la resistencia de carga(corriente nula en el condensador en régimen permanente).

iR≔―――

VoBuck
R
iL≔iR

Se tomará en cuenta el siguiente gráfico de la corriente para una mayor facilidad de calculo

Suponiendo que se genera un triangulo perfecto entre la corriente de la resistencia y la corriente máxima

Por lo tanto la corriente máxima del inductor será

iLmax＝iL+―――

ΔiL_open
2

Remplazando por las corrientes correspondientes queda como.

iLmax＝―――+

VoBuck
R ――――――

((D -1)) T⋅VoBuck

### 2 L

Por otro lado se tiene la corriente mínima como:

iLmin＝iL-―――

ΔiL_open
2
Remplazando se obtiene:

iLmin＝―――+

VoBuck
R ――――――

((1- D)) T⋅VoBuck

### 2 L

Para que el análisis anterior sea valido se debe verificar que exista corriente permanente el inductor. esto se cumple cuando la corriente mínima en el inductor sea cero, ya que es el limite entre corriente permanente y discontinua.

Entonces con la corriente mínima nula se obtiene que:

iLmin＝―――+ | ＝

VoBuck
R ――――――

((1- D)) T⋅VoBuck

### 2 L

0

Con este cálculo se puede obtener la inductancia mínima aceptable para que funcione en corriente permanente

Lmin＝――――

((1- D)) R

### 2 fc

Al tener un mínimo para el valor de inductancia, se puede analizar el caso de la inductancia con un ripple de corriente dado como:

――＝

ΔiL
DT ――――――

⎛⎝VinBuck-VoBuck⎞
⎠
L

Despejando la inductancia se obtiene como:

L＝―――――――

⎛⎝VinBuck-VoBuck⎞
⎠ DT
ΔiL

Para el cálculo del capacitor se tomará en cuenta la definición de capacidad junto con el gráfico siguiente.

Desarrollando el triangulo se tiene: ΔQ＝―1
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
⎝―――

ΔiL_open
2

⎞
⎟
⎠
Y por definición se tiene:

ΔQ＝CΔVoBuck

Igualando ambas expresiones se obtiene que el condensador para el Modo Buck es:

C＝――――

TΔiL_open

### 8 ΔVoBuck

Remplazando el valor de la corriente:

C＝――――――＝

T ⋅ | ⋅
2 | ((1- D)) | VoBuck

### 8 LΔVoBuck

――――――

⎛ | ⋅ ⎝1- DBuck⎞
⎠ | VoBuck
8 f | ⋅ c

### 2 L ΔVoBuck

Una vez obtenidos todos los cálculos de los componentes y corrientes, se
tomarán en cuenta las siguientes consideraciones.

Se usarán rizzados de un 1% para el voltaje de salida y de un 30% para la corriente.
Se usa un 1% en el voltaje de salida porque evita usar capacitores gigantes y balance entre calidad de la fuente y tamaño/costo de los capacitores. En cambio, para la corriente, se usa un 30% porque el inductor no queda ni demasiado grande ni demasiado chico y se mantiene operación en CCM (Continuous Conduction Mode) con un diseño razonable.

ΔVoBuck≔0.01 ⋅VoBuck=0.14 DBuck≔―――

VoBuck

VinBuck

R=39.2 VoBuck≔14

ΔiL≔0.3 ⋅―――=

P

VoBuck

0.107 | fc≔60000 | VinBuck≔23

Con estos valores se tienen los siguientes componentes y corrientes a considerar Para la inductancia se tomará en cuenta el siguiente cálculo:

L≔――――――――=

⎛ | ⋅ ⎝VinBuck-VoBuck⎞
⎠ | DBuck
f ⋅ c ΔiL

8.522 ⋅ 10⁻⁴

El calculo de la inductancia mínima no se tomará en cuenta para el diseño, pero si para el cálculo, ya que está entre el limite de la discontinuidad con:

Lmin≔―――――=

⎛⎝1- DBuck⎞
⎠ R

### 2 fc

1.278 ⋅ 10⁻⁴

Eligiendo de esta forma el valor de inductancia de ⎛⎝8.522 ⋅ 10⁻⁴⎞ ⎠ H

Para la capacitancia se tiene el siguiente valor:

C≔―――――――=

⎛ | ⋅ ⎝1- DBuck⎞
⎠ | VoBuck
8 ⋅ | ⋅ ⎛
⎝f | ⋅ c

### 2 L⎞

⎠ ΔVoBuck

1.594 ⋅ 10⁻⁶ F

Al tener este valor, se tendrá que escoger un capacitor cerámico de 2.2 µF, 25 V que acepte el voltaje de salida.

Para las corrientes aceptables en el inductor se tienen:

iLmaxAVG≔―――=

P

VoBuck

0.357

iLmax≔―――+ | =

VoBuck
R ――――――
⎛ | ⋅ ⎝1- DBuck⎞
⎠ | VoBuck
2 ⋅L⋅ fc

0.411

iLmin≔―――- | =

VoBuck
R ――――――
⎛ | ⋅ ⎝1- DBuck⎞
⎠ | VoBuck
2 ⋅L⋅ fc

0.304

ΔiL_open≔――――――=

⎛ | ⋅ ⎝1- DBuck⎞
⎠ | VoBuck
L⋅ fc

0.107

Para el análisis del Modo Boost también se tomarán las mismas suposiciones mencionadas previamente para el Modo Buck para facilitar el cálculo y poder simular de manera eficiente.

Se tomará en cuenta el siguiente circuito

Para comenzar el análisis se abarcará la tensión y la corriente en el inductor con el MOSFET 2 comportándose como un switch cerrado y el
MOSFET 1 como un switch abierto

Al tener solo el MOSFET 2 cerrado, se genera una malla sin tomar en cuenta a la carga, ya que el MOSFET 1 se encuentra como un circuito abierto. Por lo que por ley de Kirchoff se tiene que el voltaje en el inductor es:

VL＝VinBoost＝L⋅

⎛
⎜
⎝

―d ―dt
iL

⎞
⎟
⎠
Malla para el caso del
Teniendo en cuenta la variación de la corriente en | MOSFET 2 cerrado
el tiempo como:

――＝

d
dt

iL ―――

VinBoost
L

En este caso la corriente
aumenta linealmente, según el comportamiento de este
mostrado a continuación.

Por lo que la variación de la corriente en el inductor se puede escribir como:

――＝ | ＝

ΔiL
Δt ―――

ΔiL
DBoostT ―――

VinBoost
L

Despejando la variación de la corriente en el inductor, se tiene.

ΔiL_close＝―――――

V ⋅ inBoost DBoost
L⋅ fc

En el caso en que el MOSFET 2 se comporte como un switch abierto y el MOSFET 1 como un switch cerrado, se tiene el siguiente valor para la tensión del inductor.

VL＝VinBoost-VoBoost＝L⋅

⎛
⎜
⎝

―d ―dt
iL

⎞
⎟
⎠

Con la variación de la corriente como:

――＝

d
dt

iL ―――――― VinBoost-VoBoost L

Tomando en consideración el mismo comportamiento de la corriente para el caso del MOSFET 2 cerrado, se obtiene:

――＝ | ＝

ΔiL
Δt ―――――

ΔiL
⎛ | ⋅ ⎝1- DBoost⎞
⎠ | T | ―――――― VinBoost-VoBoost L
Obteniendo una corriente | ΔiL

ΔiL_open＝――――――――――

⎛ | ⋅ ⎝VinBoost-VoBoost⎞
| | ⎠ ⎛⎝1- DBoost⎞ ⎠ L⋅ fc

Respecto a su análisis en régimen permanente, es idéntico a su contraparte en Modo Buck.

ΔiL_open+ΔiL_close＝0

Remplazando las ecuaciones respectivas a los términos de corriente, se obtiene:

――――――――――+ | ＝
⎛ | ⋅ ⎝VinBoost-VoBoost⎞
⎠

⎛⎝1- DBoost⎞
⎠
L⋅ fc

―――――

V ⋅ inBoost DBoost
L⋅ fc

0

Despejando en términos del ciclo de trabajo( DBoost) se obtiene:

―――＝

VoBoost

VinBoost

――1 ―― 1- DBoost

Se puede apreciar que cuando el ciclo de trabajo del MOSFET se aproxime a la unidad, la salida se hará infinita. Pero, esto solo ocurre en casos ideales, en la realidad los componentes que se ocuparán, producen pérdidas e impedirán que la salida se haga infinita.

La corriente media en el inductor se calculará teniendo en cuenta que la potencia
entregada por la fuente debe ser igual a la potencia absorbida por la resistencia de carga

Si se tiene el voltaje de salida y la potencia absorbida por la carga, se puede obtener el valor de la carga

Po＝―――

VoBoost

2
R
Igualando la potencia de entrada con la salida se puede obtener la corriente estimada que circulará por el inductor.
Pin＝Po | Con | Pin＝i | ⋅ in | VinBoost | y | iin＝iL

Desarrollando se obtiene:

VinBoost⋅iL＝―――＝

VoBoost

2
R ―――――

⎛
⎜
⎝

――――

VinBoost

1- DBoost

⎞
⎟
⎠

2

R

Con una corriente en el inductor como:

iL＝――――

VoBoost
((1- D))

### 2 R

Para las corrientes máximas y mínimas aceptables en el inductor que realiza el mismo análisis gracias al comportamiento del inductor en corriente continua

iLmax＝iL+―――＝

ΔiL_close
2 ――――+

VinBoost
((1- D))
2 | R | ――――― V ⋅ inBoost DBoost 2 L⋅ fc

iLmin＝iL-―――＝

ΔiL_close
2 ――――-

VinBoost
((1- D))
2 | R | ――――― V ⋅ inBoost DBoost 2 L⋅ fc

Al momento de calcular el valor de la inductancia, se debe tomar en cuenta que la corriente en el inductor sea permanente, requiriendo que la corriente mínima sea 0, estando en el limite de la discontinuidad.

0＝―――――-

VoBoost
⎛⎝1- DBoost⎞
⎠
2 | R | ――――――――――
⎛ | ⋅ ⎝VinBoost-VoBoost⎞
| | ⎠ ⎛⎝1- DBoost⎞ ⎠ L⋅ fc

Por lo tanto, la inductancia mínima para que el circuito opere de manera continua es:

Lmin＝――――――――

DBoost⋅ ⎛ | | ⋅ ⎝1- DBoost⎞ ⎠ 2 R
| 2 ⋅ fc

En el caso del cálculo del capacitor se tomará en cuenta con el rizado pico a pico de la tensión de salida y a partir de la forma de onda de la corriente en el condensador

Gráfico del comportamiento de la corriente en el capacitor en un convertidor Boost

||ΔQ||＝―――⋅ ＝

VoBoost
R⋅ fc

DBoost C⋅ΔVoBoost

Por lo tanto el valor del
condensador será

C＝―――――

V ⋅ oBoost DBoost

R⋅ f ⋅ c ΔVoBoost

Además de los cálculos, se toman las mismas consideraciones que en el Modo Buck, por lo que se tienen:

DBoost≔ | =

⎛
⎜
⎝

――――――

VoBoost-VinBoost

VoBoost

⎞
⎟
⎠

0.556 ΔVoBoost≔0.01 ⋅VoBoost=0.27

ΔiL≔0.3 ⋅―――=

P

VinBoost

0.125 R≔―――=

VoBoost

2
P

145.8

Con estos valores se tienen los siguientes
componentes y corrientes a considerar

La inductancia que se tomará en cuenta en el inductor, se calculará con la siguiente expresión con el rizzado de la corriente posible para el inductor será de:

L≔―――――=

V ⋅ inBoost DBoost
Δi ⋅ L fc

8.889 ⋅ 10⁻⁴

También la inductancia mínima a considerar será:

Lmin≔――――――――=

DBoost⋅ ⎛ | ⋅ ⎝1- DBoost⎞
⎠

### 2 R

2 ⋅ fc

1.333 ⋅ 10⁻⁴

serán:; iLmax≔―――――+; VinBoost ⎛⎝1- DBoost⎞ ⎠; ⋅ inBoost; DBoost; iLmin≔―――――-; iLmaxAVG≔―――=; VinBoost; ΔiL_close≔―――――=; Por otro lado, se tiene el capacitor como:; V ⋅ oBoost DBoost; ΔVoBoost; Referencias:; MOSFETS; para el caso de un buck bidireccional:; *HIGH MOS ->Rpd ->source *LOW MOS ->Rpd ->GND; IGSSmax≔1 ⋅ ((10)); Vthmin≔2; Vleak＝IGSSmax ⋅Rpd; Donde R_pd es la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

Los valores de corrientes que se deben considerar

Electrónica de potencia- Daniel W. Hart

Se necesita una resistencia pulldown que asegure que el gate del MOSFET, esto es debido a las capacitancias parasitas del gate que pueden permanecer cargadas aún cuando el driver no esté activo

para simplificar la
notación se define lo
siguiente

## Resistencias Gate Vcc≔12

si es que el switch está
cerrado
Caso sin resistencia de gate | Vin((t))≔Vcc | Vin＝Vin((t))
Vcgs＝Vcgs ((t))
Por malla se obtiene | Vrg＝Vrg ((t))
Vin＝Vcgs | icgs＝C | ―d | ―dt
Vcgs | corriente del capacitor

Debido a que el voltaje
en Vin depende de Vcc,
este se comporta como
un escalón, provocando
un pulso en la corriente
icgs
icgs＝C | ―― | ＝

d
dt
Vcgs | C ―d | ―dt
Vin
->―d | ―dt
u | ->

Caso con resistencia de gate Aplicando malla nuevamente y
despejando la corriente del capacitor
Vin＝Vcgs+Vrg
Vcgs＝Vin-Vrg | corriente del capacitor
C | ―― | ＝

d
dt
Vcgs | C ―d ―dt
((Vin-Vrg)) | icgs＝C | ―d | ―dt
Vcgs
icgs＝C | ―d | ―dt
((Vin-icgs ⋅Rg))

EDO
icgs＝C⋅

⎛
⎜
⎝

―d ―dt
((Vin-icgs ⋅Rg))

⎞
⎟
+ | ＝ | ⎠ icgs | C⋅

⎛
⎜
⎝

―d ―dt
icgs ⋅Rg

⎞
⎟
⎠

C⋅

⎛
⎜
⎝

―d ―dt
Vin

⎞
⎟
⎠
Laplace | Eligiendo Rg
icgs ((s))+C⋅ ((s ⋅icgs ((s)) ⋅Rg))＝C⋅ ((s ⋅Vin((s)))) | se requiere limitar icgs, tomando la datasheet del
Driver IR2184, este tiene un output máximo de 1.4A, por simplicidad y para tener margen al calcular la
icgs ((s)) ⋅ ((1+C⋅ s ⋅Rg))＝C⋅ ((s ⋅Vin((s)))) | resistencia de gate se limitará icgs a 1.2 A

icgs ((s))＝C⋅―――――

((s ⋅Vin((s))))
((1+C⋅ s ⋅Rg))

Rg≔――→

Vcc
1.2

### 10.0 Ω

como Vin se comporta como un escalon de 0 a Vcc se tiene

icgs ((s))＝C⋅―――――⋅ ＝

((s ⋅Vcc))
((1+C⋅ s ⋅Rg)) ―1
s
C⋅―( | ―Vcc――― (1+C⋅ s ⋅Rg)) | capacitancia gate source
icgs ((s))≔――⋅ | ―――→

Vcc
Rg

⎛
⎜
⎜
⎝

――1 ―

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
invlaplace
1.2 ⋅ e

―――

-1.0 ⋅ t
RgC | ∴ | icgs ((t))≔――⋅ Vcc
| | Rg

e

―――

-t
Rg ⋅ C

Si bien la capacitancia parasita está altamente exagerada, esto es para que el comportamiento de la corriente sea más notorio, a valores más reales de capacitancia la corriente tendrá un cambio más abrupto pero se evitara el impulso.

Cgs+Cgd＝1350 ⋅ 10⁻¹²
Cgd＝155 ⋅ 10⁻¹²
Cds+Cgd＝330 ⋅ 10⁻¹²

icgs ((t)) → 1.2 ⋅ e

-15746.400000000001033052 ⋅ t | M≔

0 1 1
0 0 1
1 0 1

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
1350 ⋅ 10⁻¹²
155 ⋅ 10⁻¹²
330 ⋅ 10⁻¹²

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
lsolve ((M,v))=

1.75 ⋅ 10⁻¹⁰
1.195 ⋅ 10⁻⁹
1.55 ⋅ 10⁻¹⁰

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
Cgs≔1.195 ⋅ 10⁻⁹ F

## Voltaje en el capacitor

icgs ((t))＝――⋅

Vcc
Rg

e

―――

-t
Rg ⋅ C
icgs＝C | ―d | ―dt
Vcgs
C | ―― | ＝
| d dt
Vcgs ((t)) ――⋅

Vcc
Rg

e

―――

-t
Rg ⋅ C
Vcgs ((t))＝― | ＝

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
Rg ⋅ C
t 12

⎛
⎜
⎝1-e

―――

-t
Rg ⋅ C

⎞
⎟
⎠

## Teoría de los MOSFETS y su elección

Se toman en cuenta los Mosfet por sobre los transistores BJT. Los transistores BJT requieren aplicar corriente al Pin de base(gate en el caso de mosfet), perdiendo energía en el proceso. En cambio un MOSFET requiere voltaje en su pin Gate y casi no fluye corriente, proporcionando un circuito más eficiente y fácil de diseñar. Además los MOSFETs pueden manejar mucha más corriente.

El términal de Gate,por si solo, actúa como un
condensador, almacenando carga. Si esta carga no
tiene a donde ir, el MOSFET permanecerá activado.

Cuando se cambia de apagado a encendido en la parte del GATE ocurre un pico de corriente, ya que los electrones entran rápidamente en este terminal(fracciones de segundos). Por esta razón se requiere colocar una resistencia entre el GATE y lo que sea que lo alimente, para
poder disminuir la corriente( corriente IN-RUSH) que pueda
dañar a la alimentación del GATE.
Ahora, para descargar el Mosfet se requiere un camino a tierra, para esto se añade una resistencia en paralelo entre el GATE y tierra. Cuando se alimenta el GATE, una pequeña corriente fluye hacia la resistencia en paralelo(10kOhm), pero el pin de voltaje del Mosfet
recibe el voltaje completo y cuando se des energiza los electrones
pueden llegar adecuadamente a tierra.

En nuestro caso el MOSFET que se ocupará será de Enriquecimiento(canal N) normalmente apagado (GATE:ON, fluye corriente; GATE:OFF, no fluye corriente del DRAIN al SOURCE). La flecha del Mosfet indica como se manipula el semiconductor del MOSFET

Para que el MOSFET este en un estado OFF el voltaje del SOURCE debe igualar o superar el voltaje del GATE, por otro lado el voltaje GATE debe ser mayor que el de SOURCE.

| Para el caso del estado ON del MOSFET la zona entre el DRAIN y el SOURCE se disminuye la resistencia entre ellos, ENCENDIENDO EL MOSFET.

El semiconductor está hecho de silicio, en su interior se encuentran átomos de silicio(poseen 4 electrones de valencia). En el caso de que un Mosfet está dopado de tipo N, es porque posee atomos de fosforo, que posee 5 electrones de valencia. Como en este caso se encuentra el equilibrio completando con 8 electrones, quedará un electron libre, teniendo una carga negativa.

En el caso de enriquecimiento tipo N, se tiene una base de un material tipo p(carga positiva) y dos secciones tipo N que estarán conectadas al SOURCE y al DRAIN del mosfet y se encuentra de la siguiente forma.

En este caso la parte del
GATE estará entre el
SOURCE y el DRAIN, en
donde se ubicará el
compuesto Dioxido de silicio, el cual posee una resistencia muy alta para separar
completamente el pin de
GATE del semiconductor,
para que la corriente no
pase a través de él.

# Metal Oxide Semiconductor Field Effect (MOSFET)

En general, si aplicamos un voltaje del Mosfet del DRAIN a SOURCE, no fluirá corriente (Region de agotamiento está bloqueando el paso), en este caso solo el diodo del lado del DRAIN se activa.

Una vez que se aplica un voltaje a la compuerta GATE, se genera un campo electrico en la compuerta metalica, alcanzando al semiconductor de silicio y comportándose como un capacitor.

Los electrones de la capa tipo P se empiezan a acercar a la parte del GATE(+). Al no poder traspasar la placa hacia la parte positiva, se empiezan a acumular los electrones, generando un puente entre la parte del DRAIN y la del SOURCE.

Por esto mismo se requiere un voltaje lo suficientemente grande para poder atraer una cantidad significativa de electrones para que se genere ese puente y funcione de manera efectiva el MOSFET. El voltaje necesario para aplicar al pin de GATE para que se genere corriente entre el DRAIN y el SOURCE se llama VOLTAJE UMBRAL

A medida que aumentamos el voltaje en el GATE el puente se ensancha, al aumentar el voltaje de DRAIN a SOURCE, la resistencia DISMINUYE y la corriente aumenta linealmente (Region Ohmnica)

Region OHMNICA

La región de agotamiento se hace mas fuerte en la zona del DRAIN, debido al diodo en polarización inversa, comenzando a estrechar el canal en un extremo, generándose un punto de ESTRANGULAMIENTO. Además, debido a la corriente que fluye por el canal, no se podrá cerrar completamente, es decir, la corriente no podrá aumentar más y generándose una zona de SATURACIÓN. Entonces, para aumentar la corriente se requerirá un aumento en el voltaje de GATE.

PUNTO DE ESTRANGULAMIENTO


# Driver

Se emplea el IR2184 como driver half-bridge con canales alto (HO) y bajo (LO) para accionar los dos MOSFET del buck bidireccional. El canal alto es “flotante” y opera mediante bootstrap, por lo que es apto para conmutar un MOSFET high-side N-canal respecto a un nodo conmutado (VS). Se escoje el driver por su diseño especifico
para convertidores sincronos. El dispositivo es inmune a dV/dt rápidos.

El canal alto del IR2184 utiliza un circuito bootstrap, el cual consiste en un diodo rápido y un condensador conectados de forma que, cuando el MOSFET de bajo lado está encendido y el nodo conmutado está a tierra, el condensador se carga con el voltaje de alimentación del driver. Posteriormente, al querer activar el MOSFET de alto lado, el condensador proporciona un voltaje adicional que “eleva” la compuerta por encima del nodo conmutado, permitiendo su correcta conducción sin necesidad de una fuente de alimentación aislada. De esta manera, el bootstrap permite que el canal alto funcione de forma flotante y controle eficientemente al MOSFET superior del half-bridge, en caso de que falle tiene la proteccion UVL.


Calculo de vueltas del inductor

En nuestro caso tenemos
N＝ | una inductancia de 1mH ² | ―L ―AL

Análisis de potencia; Pérdidas en forma de calor; Debido al "rise time" y "fall time" del MOSFET, existen pérdidas durante la conmutación; Vinmax≔VoBoost; IL≔iLmaxAVG; trise≔75 ⋅ 10⁻⁹; tfall≔40 ⋅ 10⁻⁹; Se toma el peor caso para la potencia disipada; promedio; VQ2ds＝Vin; Pdmax1＝―⋅; IL Vinmax trise; Pdmax2＝―⋅; IL Vinmax tfall; VQ1ds＝Vin; Pdmax1≔―⋅; IL Vinmax; trise+tfall⎞; Rth≔60; esto quiere decir que en el peor de los casos los MOSFETs operarán 2.3; ΔT≔Pdmax1 ⋅Rth → 2.32875000000000013038

Luego tomando el valor de la resitencia térmica se obtiene

Pd | ＝ | grados sobre la temperatura ambiente max1 | ―ΔT―Rth

Eficiencia; MOSFETs; Perdidas por conducción; HIGH-MOSFET; derivando desde la expresión de potencia; luego buscamos el valor promedio de la corriente; PHS_C＝―1 T; Rds; PHS_C＝―; ILrms² DT Rds; ILrms; 2 D Rds; LS MOSFET; ILrms² ((1- D)) T Rds; ILrms ⋅; Pérdidas por conmutación; Reutilizando las expresiones de la sección anterior; PHS_sw＝―; ⎛⎝Iout⋅Vin⋅ ⎛⎝; trise+tfall⎞ ⎠; pérdidas en el tiempo muerto; PLS_sw＝2 ⋅ ⎛; ⋅ ⎝Iout⋅Vdiodo ⋅ ⎛⎝; tmuerto⎞ ⎠; se multiplica por dos debido a que hay dos tiempos muertos por ciclo; Pérdidas Resistencias gate; ambas resistencias de gate; dW＝vdq; Prg＝2 ⋅ Qg ⋅Vgs ⋅ fc

Para el low side mosfet, se calculan las

utilizando la expresión de energía para cargar el MOSFET se puede calcular la potencia disipada en

Resistencias de pull down; calculada por; PRpd＝―; t2 ―Vgs――; Rpd; D ⋅―Vgs―; ((1- D)) ⋅―Vgs―; resistencia de inductor; MLT≔――――⋅; Dconductor≔0.912 ⋅ 10⁻³; l≔N⋅MLT → 0.951902574037707351255; ρcu≔1.72 ⋅ 10⁻⁸; Dconductor 2; ⋅ Lrms; R20c＝ρcu ⋅―→; R20c＝0.02506348107109879963079 resistencia de Capacitores; Pc＝ICrms; ESR; ESR＝―tan――; tan((δ))＝――＝; Eficiencia resultante para modo buck (cálculos en python)

Al igual que las pérdidas por conducción esta puede ser

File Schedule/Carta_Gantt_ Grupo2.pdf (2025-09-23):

# Taller de sistemas electrónicos

### Integrantes: Agustín Torres Bobadilla Gian Lucas Barbagelata

Ignacio Cerda Torres | Inicio del proyecto:
Duración (total) | Semana 6
115 dias | 16 | 17 | 18 | 19 | 20 | 21 | 22 | 23 | 24 | 25 | 26 | 27 | 28 | 29 | 30 | 31
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
9 | 10 | 11 | 12 | 13 | 14 | 15 | 16 | 17 | 18 | 19 | 20 | 21 | 22 | 23 | 24 | 25 | 26 | 27 | 28 | 29 | 30

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
9 | 10 | 11 | 12 | 13 | 14 | 15 | 16 | 17 | 18 | 19 | 20 | 21 | 22 | 23 | 24 | 25 | 26 | 27 | 28 | 29 | 30 | 31

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
9 | 10 | 11 | 12 | 13 | 14 | 15 | 16 | 17 | 18 | 19 | 20 | 21 | 22 | 23 | 24 | 25 | 26 | 27
Nombre de TAREA | Asignado a | Duración (en días) | Inicio
s
d | l | m

m

j

v

s

d | l | m

m

j

v

s

d | l | m

m

j

v

s

d | l | m

m

j

v

s

d | l | m

m

j

v

s

d | l | m

m

j

v

s

d | l | m

m

j

v

s

d | l | m

m

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

s

d | l | m

m

j

v

s

d | l | m

m

j

v

s

d | l | m

m

j

v

s

d | l | m

m

j
Proyecto 1: Convertidor DC/DC Buck Bidireccional | 93Total | 16/08/2025
NIVEL 0: Planificación | 5 Total
Tarea 1: Crear e investigar Carta Gantt | Gian Barbagelata
1 | 16-8-25
Tarea 2: Planificación Carta Gantt | Todos
3 | 17-8-25
Presentación Carta Gantt | Todos

1 21-8-25

Nivel 1: Prototipo Convertidor DC/DC Buck Bidireccional | Ignacio Cerda | 33 Total
Tarea 1: Estudio de topología | Todos
4 | 20-8-25
Tarea 2: Diseño de circuito y simulación | Todos
3 | 22-8-25
Tarea 3: Listado de componentes | I. Cerda
6 | 24-8-25
Tarea 4: Selección y estudio de drivers | A. Torres e I. Cerda
4 | 28-8-25
Tarea 5: Diseño del driver | Gian Barbagelata
3 | 26-8-25
Tarea 6: Diseño e implementación de PCB | Agustin Torres
4 | 31-8-25
Tarea 7: Prototipado y verificación | Todos
5 | 1-9-25
Tarea 8: Preparación de la presentación | Todos
3 | 8-9-25
Presentación Nivel 1: Resultados de simulación | Todos

1 11-9-25
Nivel 2: Generador de pulsos PWM utilizando un PIC32 | Gian Barbagelata | 33 Total
Semana de receso | Todos
7 | 15-9-25
Tarea 1: Estudio del microcontrolador | Todos
5 | 20-9-25
Tarea 2: Familiarización con kit de desarrollo | Todos
3 | 25-9-25
Tarea 3: Familiarización con lenguaje de programación | G. Barbagelata, A. Torres
4 | 28-9-25
Tarea 4: Programación de pulso PWM | G. Barbagelata, A. Torres
3 | 2-10-25
Tarea 5: Implementación código | G. Barbagelata, A. Torres
2 | 5-10-25
Tarea 6: Protocolo de verificación | Todos
3 | 7-10-25
Tarea 7: Prototipado y verficación | Todos
4 | 10-10-25
Tarea 8: Preparación presentación | Todos
1 | 14-10-25
Presentación nivel 2: Verificación de resultados | Todos

1 16-10-25
Nivel 3: Interfaz gráfica junto con microcontrolador | Agustín Torres | 22 Total
Tarea 1: Selección de plataforma para diseño de interfaz | Todos
1 | 17-10-25
Tarea 2: Programación interfaz gráfica | Agustín Torres
5 | 18-10-25
Tarea 3: Pruebas interfaz gráfica con microcontrolador | Todos
2 | 23-10-25
Tarea 4: Preparación presentación | Todos
2 | 25-10-25
Presentación nivel 3: Interfaz gráfica | Todos

1 30-10-25
Tarea 5: Conexiones del microcontrolador y driver a circuito | Todos
2 | 27-10-25
Tarea 6: Realizar pruebas y tomar mediciones | Todos
3 | 29-10-25
Tarea 7: Corrección de errores | Todos
3 | 2-11-25
Tarea 8: Preparación presentación | Todos
2 | 4-11-25
Presentación nivel 4: Proyecto final | Todos

1 6-11-25
Proyecto 2: Monitoreo de señales con un microcontrolador ESP32 | 22Total
Nivel 1: Microcontrolador ESP32 | Agustín Torres | 14 Total
Tarea 1: Estudio del microcontrolador | A. Torres y G. Barbagelata
3 | 7-11-25
Tarea 2: Familiarización con kit de desarrollo | A. Torres y I. cerda
2 | 9-11-25
Tarea 3: Programación de monitoreo remoto | Agustín Torres
3 | 11-11-25
Tarea 4: Implementación código | Todos
2 | 15-11-25
Tarea 5: Verificación de funcionamiento | Todos
2 | 17-11-25
Tarea 6: Preparación presentación | Todos
1 | 18-11-25
Presentación nivel 1: monitoreo inalamabrico | Todos

1 20-11-25
Nivel 2: Monitoreo usando interfaz gráfica y ESP32 | 8 Total
Tarea 4: Estudio e implementación de código en conjunto con interfaz
grafica | Todos
3 | 21-11-25
Tarea 5: Verificación de funcionamiento | Todos
2 | 24-11-25
Tarea 6: Preparación presentación | Todos
1 | 26-11-25
Presentación nivel 2: Implementacion final | Todos

1 27-11-25

16/08/2025
Semana 1 Agosto | Semana 2 Agosto | Semana 3 Septiembre | Semana 2 Septiembre | Semana 3 Septiembre | Semana 4 Septiembre | Semana 3 Octubre | Semana 4 Octubre | Semana 5

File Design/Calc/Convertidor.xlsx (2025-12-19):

CONVERTIDOR DC/DC BUCK BIDIRECCIONAL
ESPECIFICACIONES | Modo buck | Modo Boost
Voltaje continuo de entrada | 23[Vdc] | 12[Vdc]
Voltaje continuo de salida | 14[Vdc] | 27[Vdc]
Potencia | 5[W] | 5[W]
Switch | MOSFET | MOSFET
Frecuencia de conmutación | 60[kHz] | 60[kHz]
MODO BUCK |  |  |  |  |  |  | MODO BOOST
Mediciones | Valores calculados | Valores Simulados | Valores Practicos |  |  |  | Mediciones | Valores calculados | Valores Simulados | Valores Practicos
Ripple de Voltaje de Salida | 1% | 0.7% | 1.003% |  |  |  | Ripple de Voltaje de Salida | 1% | 1.1% | 3.76%
Ripple de Corriente de Inductor | 30% | 29% | 17.32% |  |  |  | Ripple de Corriente de Inductor | 30% | 30.5% | 26.18%
Voltaje de Entrada | 23[Vdc] | 23[Vdc] | 23[Vdc] |  |  |  | Voltaje de Entrada | 12[Vdc] | 12[Vdc] | 12[Vdc]
Voltaje de Salida | 14[Vdc] | 13.9[Vdc] | 13.95[V] |  |  |  | Voltaje de Salida | 27[Vdc] | 26.5[Vdc] | 27.1[Vdc]
Corriente promedio del Inductor | 0.357[A] | 0.33[A] | 0.433[A] |  |  |  | Corriente promedio del Inductor | 0.417[Vdc] | 0.410[Vdc] | 0.45[Vdc]
Resistencia | 39.2[Ohm] | 39.2[Ohm] | 40[Ohm] |  |  |  | Resistencia | 145.8[Ohm] | 145.8[Ohm] | 142.2[Ohm]
Duty cycle | 60.9% | 61% | 65% |  |  |  | Duty cycle | 55.6% | 60% | 59.5%
Potencia de salida | 5[W] | 4.865[W] | 4.855[W] |  |  |  | Potencia de salida | 5[W] | 4.77[W] | 5.064[W]
Eficiencia | 100% | 97.1% | 94.3% |  |  |  | Eficiencia | 100% | 95.19% | 91.3%
Corriente del inductor |  |  | Voltaje de la carga |  |  |  | Corriente del inductor |  |  | Voltaje de la carga
Inductor
Vueltas | 110
Permeabilidad | 75
Cobre | 26 AWG(0.405 mm)
 |  |  | MODO BUCK |  |  |  |  | MODO BOOST
Valores de Resistencia
 | Valores de Resistencia |  | Mediciones | Valores calculados | Valores Simulados | Valores Practicos |  | Mediciones | Valores calculados | Valores Simulados | Valores Practicos
Valores de Resistencia | Valores de Resistencia |  | Resistencia 10k | 10k | 10k | 9.8k |  | Resistencia 10k | 10k | 10k | 9.8k
Valores de Resistencia | Valores de Resistencia |  | Resistencia 47k | 47.14k | 47k | 46.6k |  | Resistencia 100k | 102k | 100k | 110.6k
Valores de Resistencia | Valores de Resistencia |  | Voltaje sensado | 2.45[V] | 2.44[V] | 2.3[V] |  | Voltaje sensado | 2.45[V] | 2.45[V] | 2.48[V]
Valores de Resistencia | Valores de Resistencia |  | Voltaje de salida | 14[V] | 13.8[V] | 13.9[V] |  | Voltaje de salida | 27[V] | 27V] | 27.1[V]
 |  |  | Duty Cycle(%) | 60% | 61% | 69% |  | Duty Cycle(%) | 55.6% | 59% | 67%
 |  |  | Potencia disipada | 0.6[mW] | 0.595[mW] | 0.539[mW] |  | Potencia disipada | 0.6[mW] | 0.59[mW] | 0.6[mW]

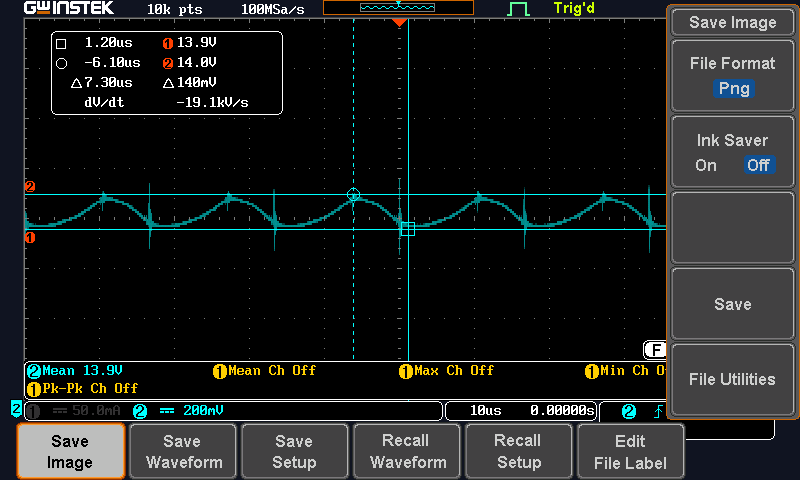
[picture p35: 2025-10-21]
pics/BUCK_V.PNG

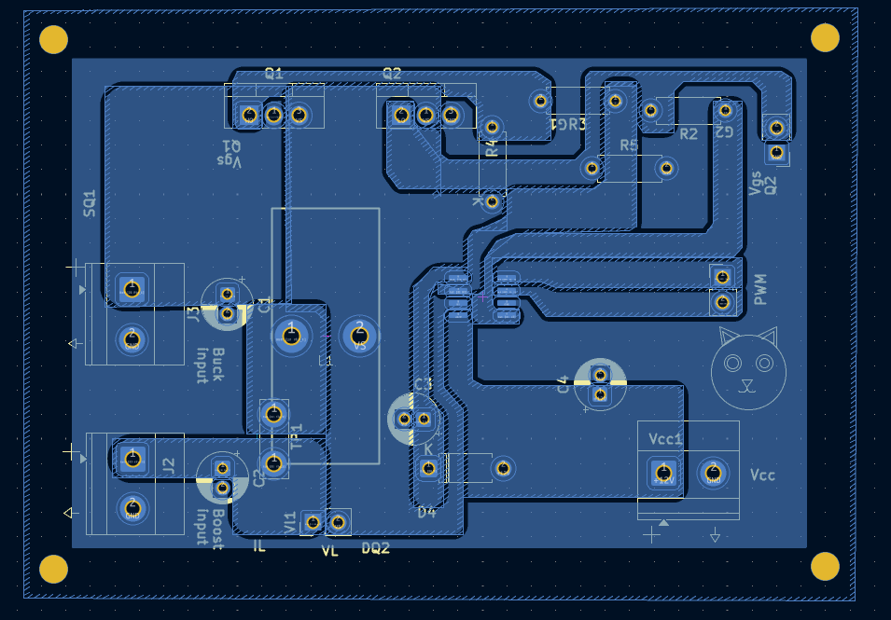
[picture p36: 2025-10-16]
pics/pcb_B.cu.png

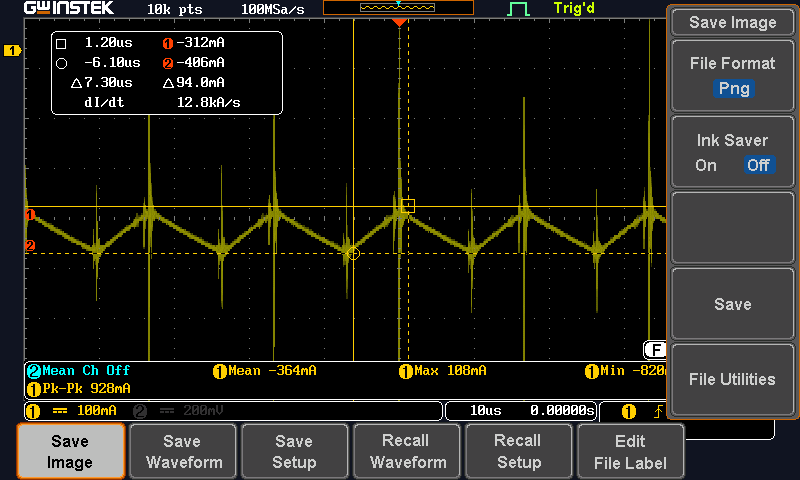
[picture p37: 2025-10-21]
pics/BOOST_C.PNG

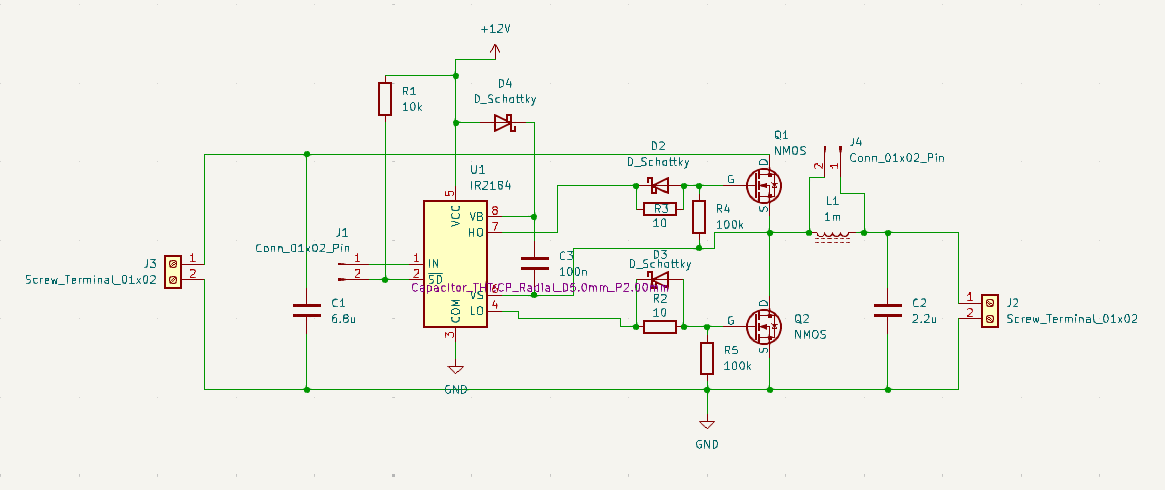
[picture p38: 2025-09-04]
pics/kicad_first_try.png

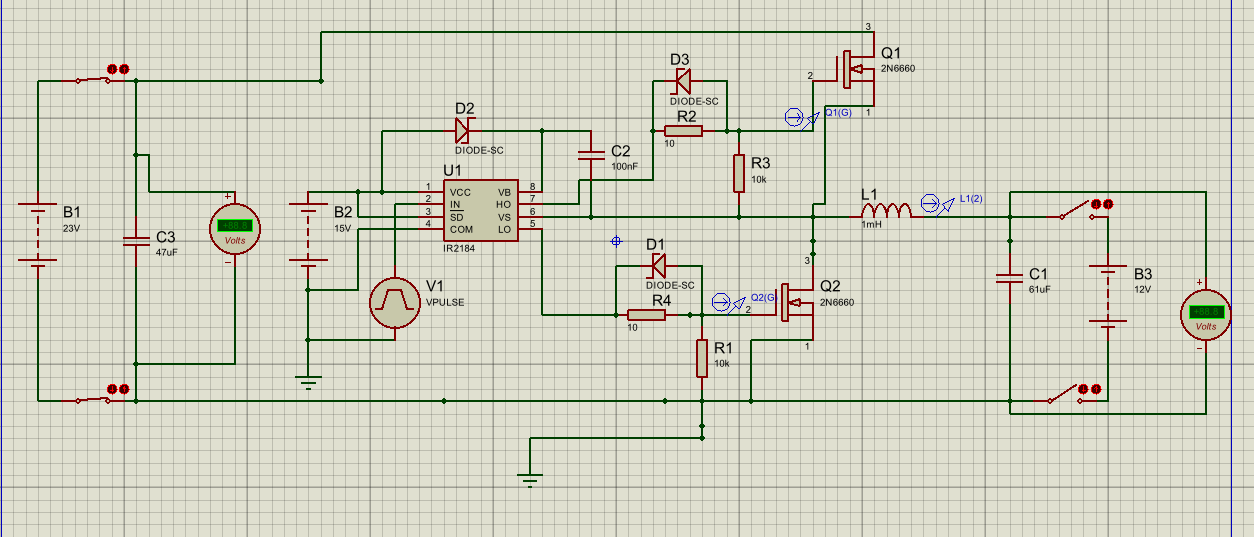
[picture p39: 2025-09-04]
pics/proteus_sim.png

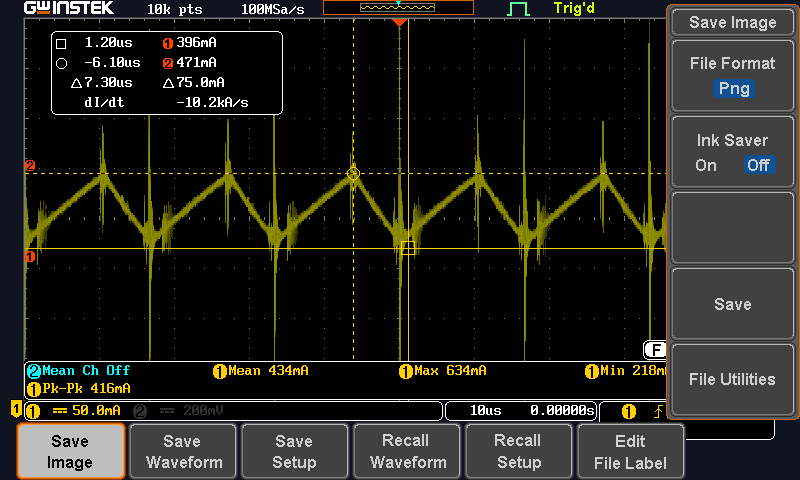
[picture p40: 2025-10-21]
pics/BUCK_C.PNG

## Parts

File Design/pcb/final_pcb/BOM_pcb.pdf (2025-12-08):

Sheet1

BOM | Quantity | Price | Link | Datasheet
Inductor | 1 | $5,454.00 https://www. https://www.mouser.cl/datasheet/3/995/1/mss1210.pdf
diodo | SS14 diode | 1 | $258.00
mosfet | STD20NF06 | 2 | $1,445.00
caps | 13 | $1,333.00
resistors | Panasonic ERJ-P06 | 9 | $123.00 | https://industrial.panasonic.com/cdbs/www-data/pdf/RDO0000/RDO0000C337.pdf (https://www.mouser.cl/ProductDetail/Panasonic/ERJ-P06J105V?qs=Zyl8A9hlmJqH%252B48B4ycwhA%3D%3D)
PIC32 | pic32mz2048efm144 | 1 | $21,459.00 https://www.
USB c | 1 | $3,842.00 https://www. https://cdn.amphenol-cs.com/media/wysiwyg/files/drawing/10132328.pdf
terminales | 1771091 | 2 | $777.00 https://www.di https://mm.digikey.com/Volume0/opasdata/d220001/medias/docus/647/1771091.pdf
Regulador 12V | LM7812 | 1 | $2,318.00 https://www. https://www.ti.com/lit/ds/symlink/lm7800.pdf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
Regulador 3.3V | TPS560200 | 1 | $1,938.00 https://www. https://www.ti.com/lit/ds/symlink/tps560200-q1.pdf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
Headers | 1 | $1,111.00 https://www.di https://suddendocs.samtec.com/catalog_english/tsm.pdf
Cristal | SG-8002CA | 1 | $6,182.00 https://www. https://www.mouser.cl/datasheet/3/97/1/SG_8002CA_en.pdf
Driver | IR2184 | 1 | $2,374.00 https://www.m https://www.mouser.com/datasheet/2/
Resistos 0 ohm | 1 | 146 https://www. https://www.mouser.com/catalog/specsheets/Bourns_11152023_CSI2H-3920_datasheet.pdf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..
Total | $67,962.00

### MSS1210-105KED

https://www.mouser.cl/ProductDetail/Taiwan-Semiconductor/SS14?qs=JV7lzlMm3yLIdi0ESVd3YQ%3D%3D https://www.alldatasheet.com/datasheet-pdf/view/1396704/VISHAY/SS14.htmlhttps://www.mouser.com/ProductDetail/STMicroelectronics/STD20NF06T4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 https://www.alldatasheet.com/datasheet-pdf/view/84757/STMICROELECTRONICS/STD20NF06.html C3225X7S1H685K250
AB | https://www.mouser.cl/ProductDetail/TDK/C3225X7S1H685K250AB?qs=LcTL%2F5vFEzF3nwVjYdojnw%3D%3D https://www.mouser.cl/ProductDetail/TDK/C3225X7S1H685K250AB?qs=LcTL%2F5vFEzF3nwVjYdojnw%3D%3D
| https://www.mouser.cl/ProductDetail/Panasonic/ERJ-P06J105V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
| https://www.mouser.cl/datasheet/3/282/1/PIC32MZ-Embedded-Connectivity-with-Floating-Point-Unit-Family-Data-Sheet-DS60001320H.pdf

10132328-10001LF

M20-8890545

CRCW04020000Z0EE
HP

FINAL

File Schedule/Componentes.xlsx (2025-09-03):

BOM
Componentes para circuito | Valor teorico | Valor de utilizado | Costo | Tienda de compra
Inductor(Cobre: 0.912mm con 2A) | 0.852mH 1A | 1mH 2A | Hecho a mano
Capacitor Buck | 1.594uF(12[V]) | 2.2uF 50V | Gratis
Capacitor Boost | 6.351uF(30[V]) | 6.8uF 50V | Gratis
Resistencia Buck | 39.2[Ohm] | 39[Ohm] | Gratis
Resistencia Boost | 145.8[Ohm] | 150[Ohm] | Gratis
Driver | IR2184 |  | $12000 | Mercado libre
Mosfets | IRFZ44N |  | $1700.00 | zava

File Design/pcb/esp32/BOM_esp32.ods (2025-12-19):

BOM | Nombre | Cantidad | Precio | link | datasheet | tag
Resistor 10k ohm | ESR01MZPF1002 | 3 | 280 | https://www.mouser.cl/ProductDetail/ROHM-Semiconductor/ESR01MZPF1002?qs=493kPxzlxfJsZwk5mwUpNQ%3D%3D | https://www.rohm.com/datasheet?p=ESR01MZPF&dist=Mouser&media=referral&campaign=Mouser | R4, R6, R7
Resistor 47k ohm | RCA020147K0FNEDSR | 1 | 112 | https://www.mouser.cl/ProductDetail/Vishay/RCA020147K0FNEDSR | https://www.mouser.cl/ProductDetail/Vishay/RCA020147K0FNEDSR | R3
Resistor 100k ohm | RCA020147K0FNEDSR | 1 | 112 | https://www.mouser.cl/ProductDetail/Vishay/RCA0201100KFNEDSR | https://www.mouser.cl/ProductDetail/Vishay/RCA020147K0FNEDSR | R5
Resistor 0 ohm | WR10X0000FTL | 2 | 146 | https://www.mouser.cl/ProductDetail/Walsin/WR10X0000FTL |  | R8, R9
Resistor 5.1k ohm | MCS04020C5101FE000 | 2 | 179 | https://www.mouser.cl/ProductDetail/Vishay-Beyschlag/MCS04020C5101FE000 | https://www.vishay.com/docs/28705/mcx0x0xpro.pdf | R1, R2
capacitor 100nF | GRJ32DR7LV104KW01L | 2 | 594 | https://www.mouser.cl/ProductDetail/Murata-Electronics/GRJ32DR7LV104KW01L | https://ds.murata.com/simsurfing/mlcc.html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 | C3,C4
capacitor 10uF | GRM155R60J106ME18D | 1 | 370 | https://www.mouser.cl/ProductDetail/Murata-Electronics/GRM155R60J106ME18D | https://ds.murata.com/simsurfing/mlcc.html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 | C1
capacitor 22uF | GRM155R60G226ME11D | 1 | 280 | https://www.mouser.cl/ProductDetail/Murata-Electronics/GRM155R60G226ME11D?qs=9Bj94LTQhPD05IUpc3I6Ow%3D%3D | https://ds.murata.com/simsurfing/mlcc.html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 | C2
ESP32 | ESP32-C3-WROOM-02-N4 | 1 | 4066 | https://www.mouser.cl/ProductDetail/Espressif-Systems/ESP32-C3-WROOM-02-N4?qs=stqOd1AaK7%2FqjTZKEOgfUg%3D%3D | https://www.mouser.com/catalog/specsheets/Espressif%20Systems_04082021_ESP32-C3-WROOM-02.pdf | U1
Regulador de voltaje 3.3v | LM1117LD-3.3/NOPB | 1 | 791 | https://www.mouser.cl/ProductDetail/Texas-Instruments/LM1117LD-3.3-NOPB?qs=X1J7HmVL2ZGwq0CPAkvTtg%3D%3D | https://www.ti.com/lit/ds/symlink/lm1117.pdf?ts=1766072465270 | U2
USB C receptacle | UJ32-C-H-G-H1-SMT-TR | 1 | 1938 | https://www.mouser.cl/ProductDetail/Same-Sky/UJ32-C-H-G-H1-SMT-TR?qs=vvQtp7zwQdN2UBTjn3oXfQ%3D%3D | https://www.mouser.cl/datasheet/3/6118/1/uj32_c_h_g_h1_smt_tr.pdf | J1
Terminales | Phoenix original MSTB2.5/2-ST-5.08 1757019 Conector | 2 | 344 | https://www.aliexpress.com/p/tesla-landing/index.html?scenario=c_ppc_item_bridge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 | N/A | J2, J3

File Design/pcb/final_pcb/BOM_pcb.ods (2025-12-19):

BOM
 |  | Quantity | Price | Link | Datasheet | Tag
Inductor | MSS1210-105KED | 1 | $5,454.00 | https://www.mouser.cl/ProductDetail/Coilcraft/MSS1210-105KED?qs=zCSbvcPd3pa2zY%252B8dqtxOA%3D%3D | https://www.mouser.cl/datasheet/3/995/1/mss1210.pdf | L1
diodo | SS14 diode | 1 | $258.00 | https://www.mouser.cl/ProductDetail/Taiwan-Semiconductor/SS14?qs=JV7lzlMm3yLIdi0ESVd3YQ%3D%3D | https://www.alldatasheet.com/datasheet-pdf/view/1396704/VISHAY/SS14.html | D1
mosfet | STD20NF06 | 2 | $1,445.00 | https://www.mouser.com/ProductDetail/STMicroelectronics/STD20NF06T4?qs=aFAO38vVFus%252Bz3Zv%2F3cYQA%3D%3D | https://www.alldatasheet.com/datasheet-pdf/view/84757/STMICROELECTRONICS/STD20NF06.html | Q1, Q2
Capacitor 2.2uF | 10132328-10001LF | 1 | $325.00 | https://www.mouser.cl/ProductDetail/Murata-Electronics/ZRB157R6YA225KE11D | https://search.murata.co.jp/Ceramy/image/img/A01X/G101/ENG/ZRB157R6YA225KE11-01A.pdf | C2
Capacitor 100nF | GRJ32DR7LV104KW01L | 12 | $549.00 | https://www.mouser.cl/ProductDetail/Murata-Electronics/GRJ32DR7LV104KW01L | https://search.murata.co.jp/Ceramy/image/img/A01X/G101/ENG/ZRB157R6YA225KE11-01A.pdf | C3-C13, C15, C18
Capacitor 10uF | GRM155R60J106ME18D | 3 | $370.00 | https://www.mouser.cl/ProductDetail/Murata-Electronics/GRM155R60J106ME18D | https://search.murata.co.jp/Ceramy/image/img/A01X/G101/ENG/GRM155R60J106ME18-01A.pdf | C14, C15, C16
Capacitor 6.8uF | C3225X7S1H685K250AB | 13 | $1,333.00 | https://www.mouser.cl/ProductDetail/TDK/C3225X7S1H685K250AB?qs=LcTL%2F5vFEzF3nwVjYdojnw%3D%3D | https://www.mouser.cl/ProductDetail/TDK/C3225X7S1H685K250AB?qs=LcTL%2F5vFEzF3nwVjYdojnw%3D%3D | C1
Resistores 10k | ESR01MZPF1002 | 3 | $280.00 | https://www.mouser.cl/ProductDetail/ROHM-Semiconductor/ESR01MZPF1002?qs=493kPxzlxfJsZwk5mwUpNQ%3D%3D | https://www.rohm.com/datasheet?p=ESR01MZPF&dist=Mouser&media=referral&campaign=Mouser | R1, R2, R7
Resistores 20k | CRCW060323R7FKEC | 1 | $179.00 | https://www.mouser.cl/ProductDetail/Vishay/CRCW060323R7FKEC | https://www.vishay.com/docs/20035/dcrcwe3.pdf | R9
 | MCT0603MD6191BP500 | 1 | $504.00 | https://www.mouser.cl/ProductDetail/TE-Connectivity-Holsworthy/3503G2B6K19FTDF?qs=By6Nw2ByBD3cHfSkLglyrA%3D%3D | https://www.vishay.com/docs/28952/mcr0201at-mca1206at.pdf | R8
PIC32 | pic32mz2048efm144 | 1 | $21,459.00 | https://www.mouser.cl/ProductDetail/Microchip-Technology/PIC32MZ2048EFM144-E-PH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 | https://www.mouser.cl/datasheet/3/282/1/PIC32MZ-Embedded-Connectivity-with-Floating-Point-Unit-Family-Data-Sheet-DS60001320H.pdf | U2
USB c | 10132328-10001LF | 1 | $3,842.00 | https://www.mouser.cl/ProductDetail/Amphenol-FCI/10132328-10001LF?qs=KVgMXE4aH4keutCLuqTPPA%3D%3D | https://cdn.amphenol-cs.com/media/wysiwyg/files/drawing/10132328.pdf | J1
terminales | 1771091 | 2 | $777.00 | https://www.digikey.com/es/products/detail/phoenix-contact/1771091/2192453 | https://mm.digikey.com/Volume0/opasdata/d220001/medias/docus/647/1771091.pdf | J2, J3
Regulador 12V | LM7812 | 1 | $2,318.00 | https://www.mouser.cl/ProductDetail/Texas-Instruments/LM7812S-NOPB?qs=9V2QonpqdTtBO5BzoGXA0A%3D%3D | https://www.ti.com/lit/ds/symlink/lm7800.pdf?ts=1764976553934 | U3
Regulador 3.3V | TPS560200 | 1 | $1,938.00 | https://www.mouser.cl/ProductDetail/Texas-Instruments/TPS560200QDGKRQ1?qs=So72BguRTJZcPjXhgSTR8w%3D%3D | https://www.ti.com/lit/ds/symlink/tps560200-q1.pdf?ts=1765035466876 | U5
Headers | M20-8890545 | 1 | $1,111.00 | https://www.digikey.com/en/products/detail/samtec-inc/TSM-105-01-S-SV/6691998 | https://suddendocs.samtec.com/catalog_english/tsm.pdf | J5
Cristal | SG-8002CA | 1 | $6,182.00 | https://www.mouser.cl/ProductDetail/Epson-Timing/SG-8002CA-14.3360M-SCML3 | https://www.mouser.cl/datasheet/3/97/1/SG_8002CA_en.pdf | Y1
Driver | IR2184 | 1 | $2,374.00 | https://www.mouser.cl/ProductDetail/Infineon-Technologies/IR2184STRPBF?qs=ellYJlE8XiF5tKx1UCxEUw%3D%3D | https://www.mouser.com/datasheet/2/196/Infineon_IR2184_4__S__DataSheet_v01_00_EN-3362797.pdf | U1
Resistos 0 ohm | CRCW04020000Z0EEHP | 1 | $146.00 | https://www.mouser.cl/ProductDetail/Vishay/CRCW04020000Z0EEHP | https://www.mouser.com/catalog/specsheets/Bourns_11152023_CSI2H-3920_datasheet.pdf | R10
PICKit 4 | MPLAB PICkit 4 In-Circuit Debugger | 1 | $113,590.91 | https://www.sparkfun.com/mplab-pickit-4-in-circuit-debugger.html | https://cdn.sparkfun.com/assets/6/4/5/3/9/MPLAB-PICkit-4-In-Circuit-Debugger-Users-Guide-DS50002751.pdf | N/A
Total |  |  | $189,991.91

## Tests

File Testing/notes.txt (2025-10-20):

<green>BUCK</green>:

INPUT: 0.22A, 23V, 5.06W

OUTPUT: 13.95V, 40ohm, 0.348A

power output: 4.865 W

efficiency: 96%

duty: 65%

<red>BOOST</red>

INPUT: 0.45A, 12V, 5.4W

OUTPUT: 0.180A, 27.1V 

power output: 5.064W

efficiency: 93.7%

duty: ~40.5%, 59.5%

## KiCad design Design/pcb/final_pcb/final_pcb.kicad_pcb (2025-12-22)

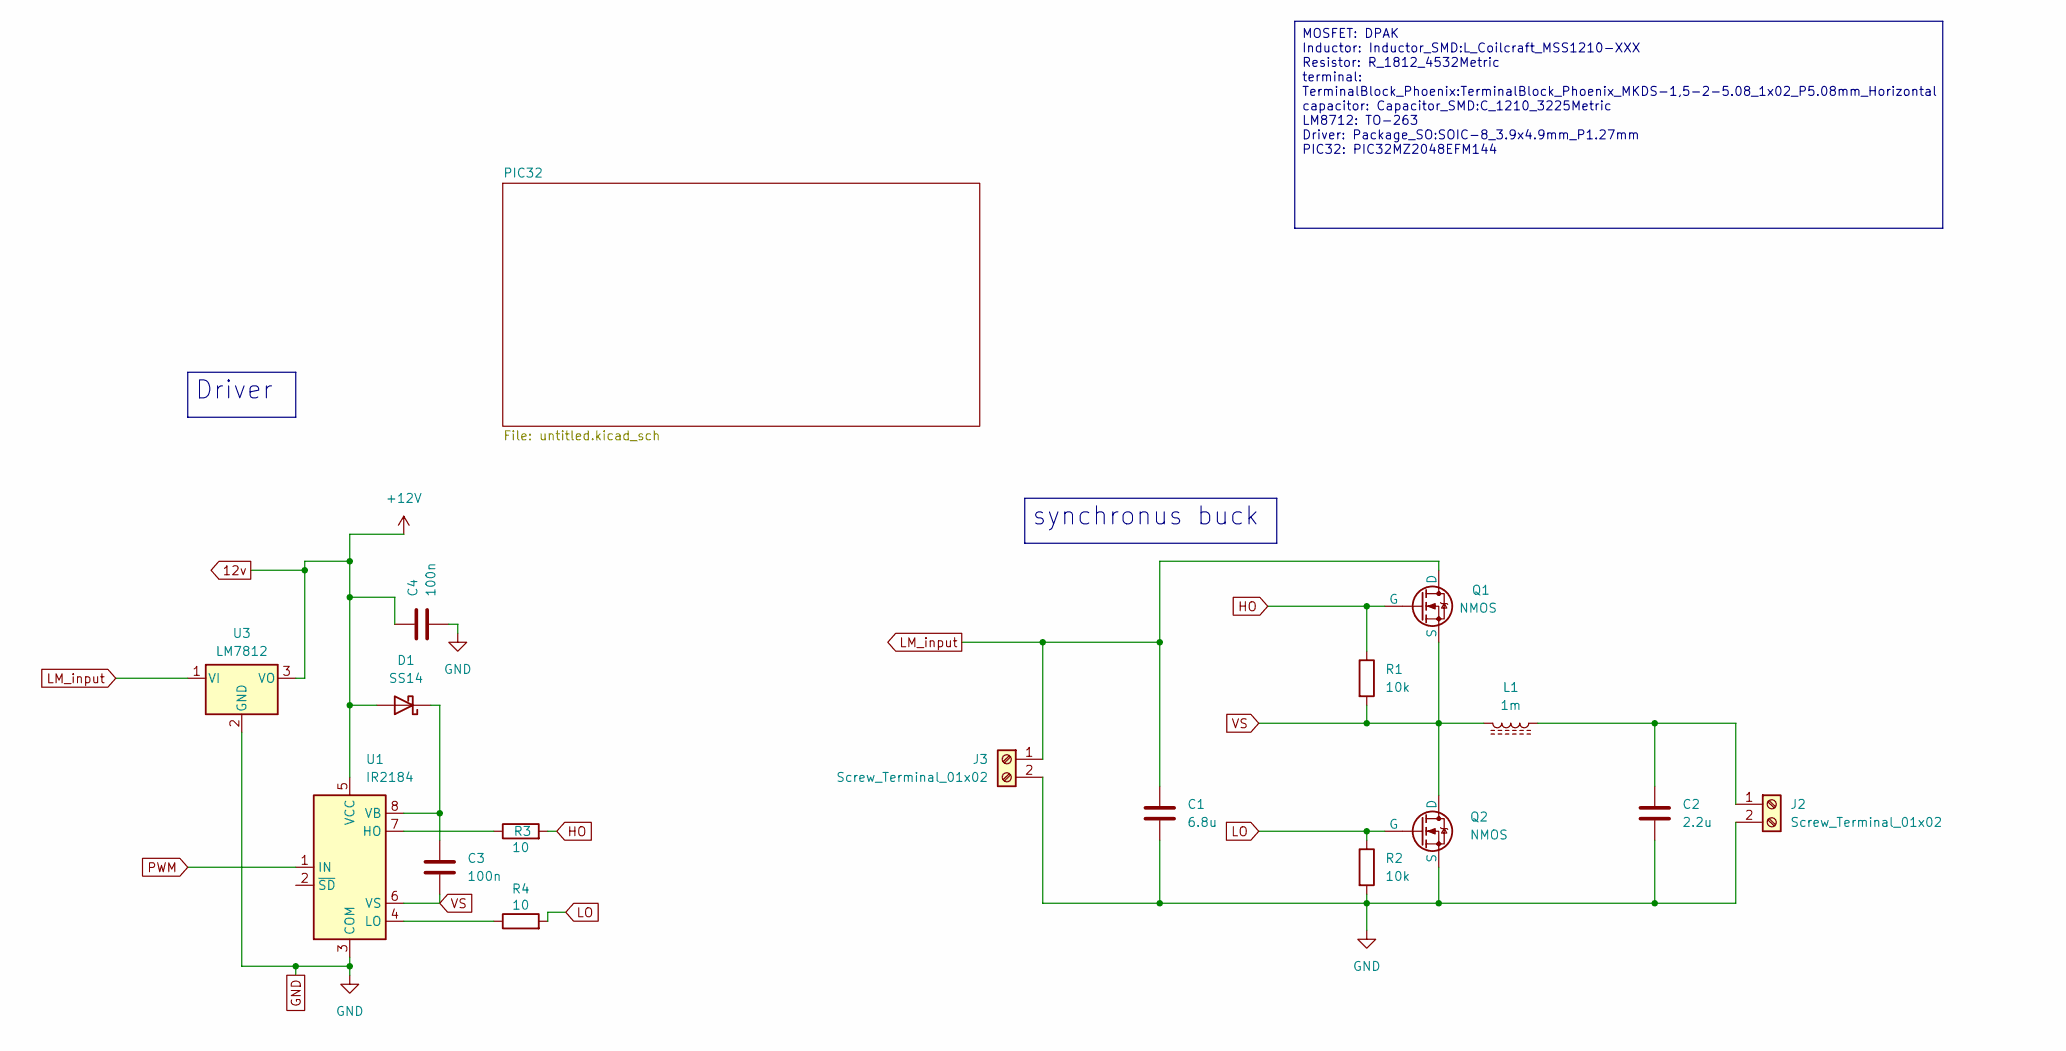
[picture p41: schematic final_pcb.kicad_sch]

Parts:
C1: 6.8u; C_1210_3225Metric
C2: 2.2u; C_1210_3225Metric
C3, C4: 100n; C_1210_3225Metric
D1: SS14; D_SMA
J2, J3: Screw_Terminal_01x02; TerminalBlock_Phoenix_PTSM-0,5-2-2,5-V-SMD_1x02-1MP_P2.50mm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
L1: 1m; L_Coilcraft_MSS1210-XXX
Q1, Q2: NMOS; TO-252-2
R1, R2: 10k; R_1812_4532Metric
R3, R4: 10; R_1812_4532Metric
U1: IR2184; SOIC-8_3.9x4.9mm_P1.27mm
U3: LM7812; TO-263-3_TabPin2

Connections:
12v: C4.1, D1.2 (A), U1.5 (VCC), U3.3 (VO); also elsewhere on the board
GND: C1.2, C2.2, C4.2, J2.2, J3.2, Q2.3 (S), R2.2, U1.3 (COM), U3.2 (GND); also elsewhere on the board
HO: Q1.2 (G), R1.1, R3.2
LM_input: C1.1, J3.1, Q1.1 (D), U3.1 (VI)
LO: Q2.2 (G), R2.1, R4.2
unnamed: C3.1, D1.1 (K), U1.8 (VB)
unnamed: C2.1, J2.1, L1.1
unnamed: R3.1, U1.7 (HO)
unnamed: R4.1, U1.4 (LO)
PWM: U1.1 (IN); also elsewhere on the board
VS: C3.2, L1.2, Q1.3 (S), Q2.1 (D), R1.2, U1.6 (VS)

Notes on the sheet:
MOSFET: DPAK Inductor: Inductor_SMD:L_Coilcraft_MSS1210-XXX Resistor: R_1812_4532Metric terminal: TerminalBlock_Phoenix:TerminalBlock_Phoenix_MKDS-1,5-2-5.08_1x02_P5.08mm_Horizontal capacitor: Capacitor_SMD:C_1210_3225Metric LM8712: TO-263 Driver: Package_SO:SOIC-8_3.9x4.9mm_P1.27mm PIC32: PIC32MZ2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
Driver
synchronus buck

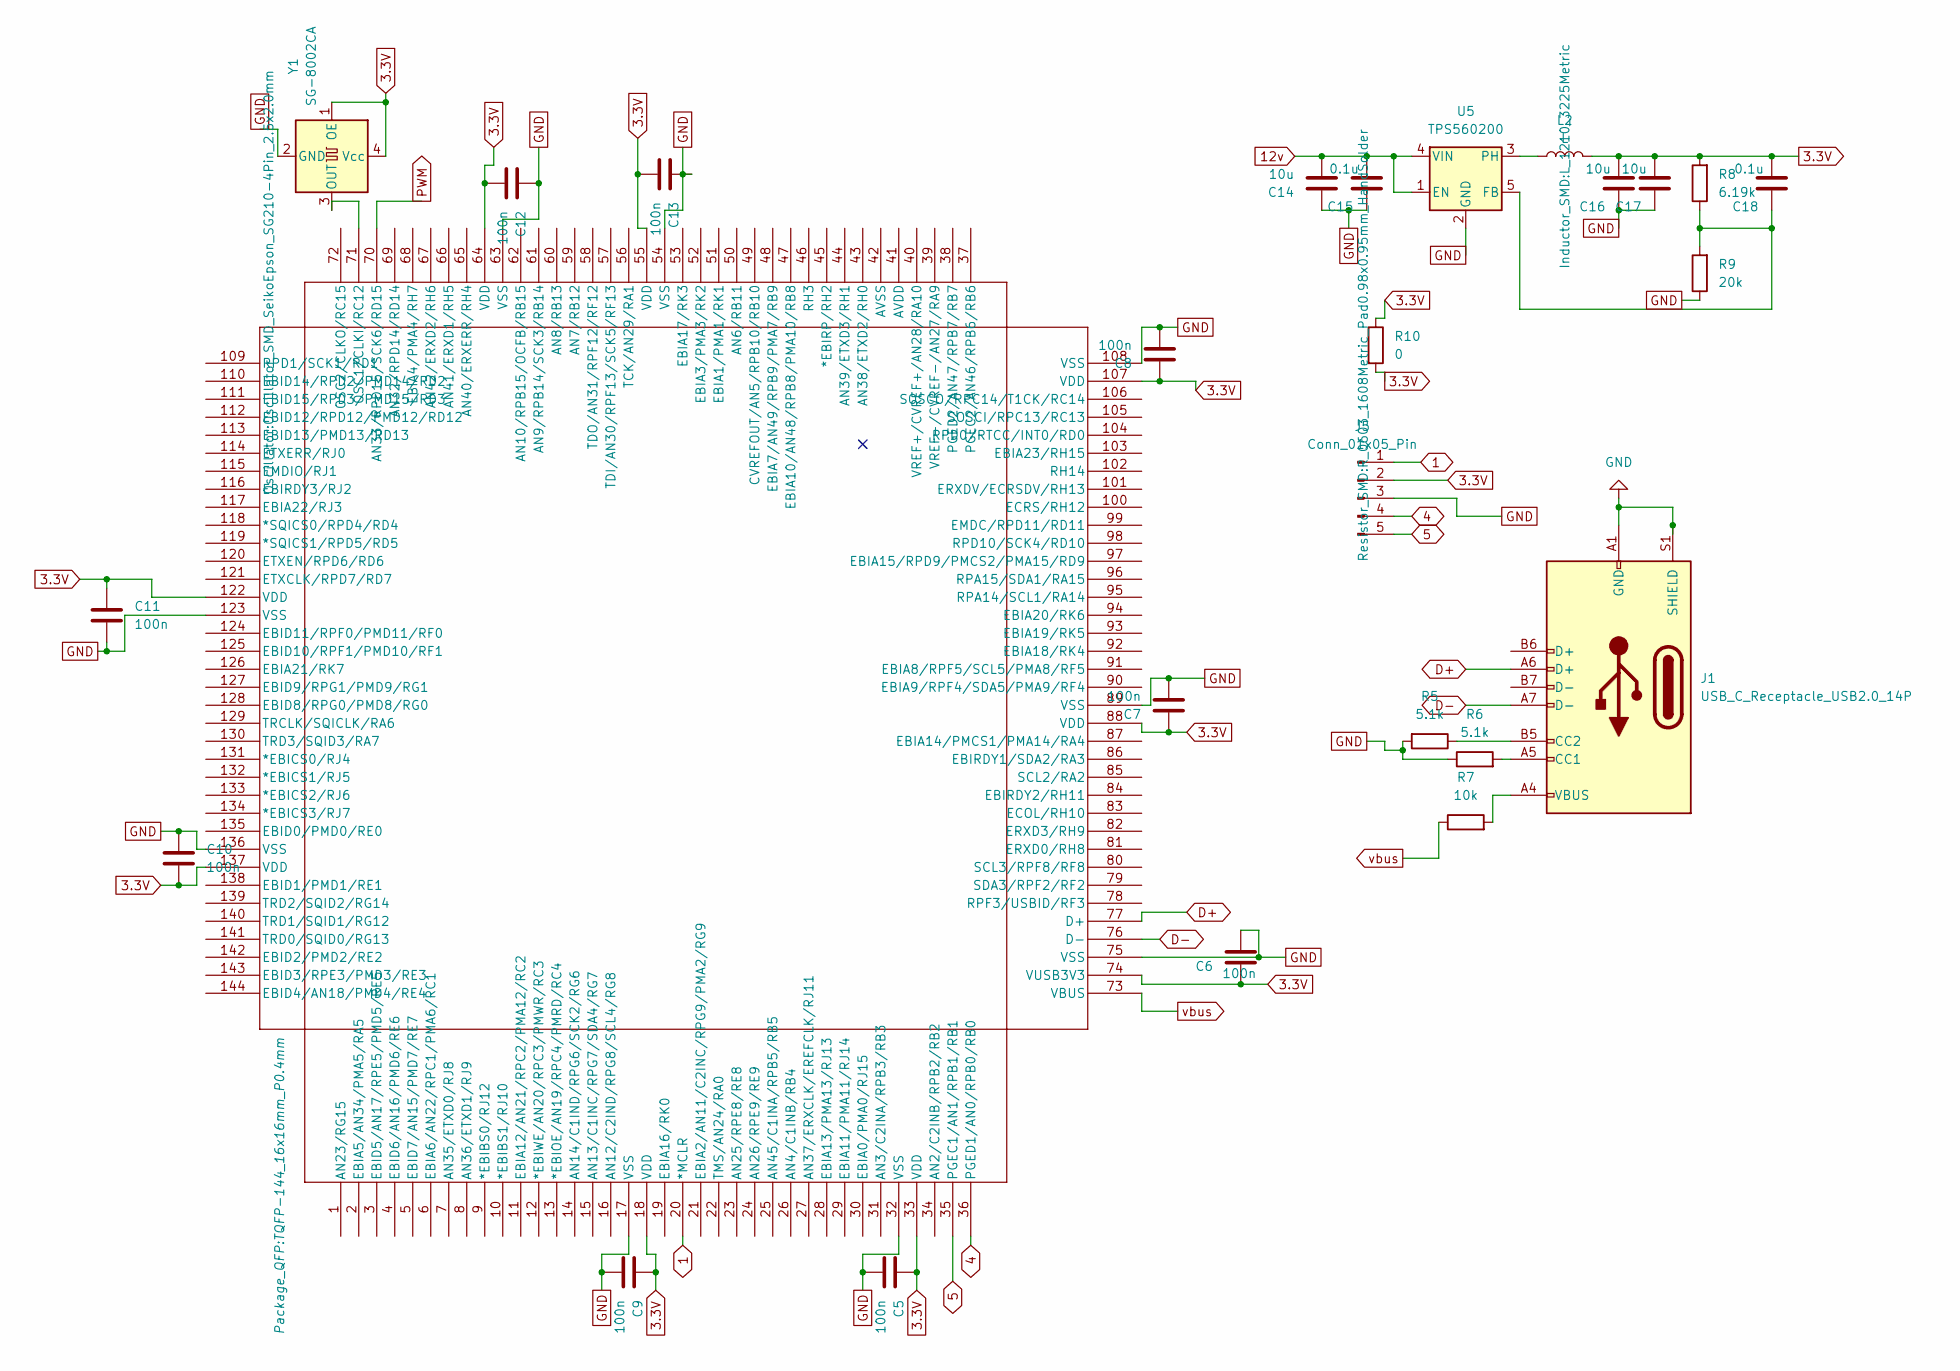
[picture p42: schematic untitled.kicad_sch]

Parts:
C5, C6, C7, C8, C9, C10, C11, C12, C13: 100n; C_1210_3225Metric
C14, C16, C17: 10u; C_1210_3225Metric
C15, C18: 0.1u; C_1210_3225Metric
J1: USB_C_Receptacle_USB2.0_14P; USB_C_Receptacle_GCT_USB4110
J5: Conn_01x05_Pin; PinHeader_1x05_P2.54mm_Vertical_SMD_Pin1Left
L2: L; L_1210_3225Metric
R5, R6: 5.1k; R_1812_4532Metric
R7: 10k; R_1812_4532Metric
R8: 6.19k; R_1812_4532Metric
R9: 20k; R_1812_4532Metric
R10: 0; R_0603_1608Metric_Pad0.98x0.95mm_HandSolder
U2: PIC32MZ2048EFM144-I/PH; TQFP-144_16x16mm_P0.4mm
U5: TPS560200; SOT-23-5
Y1: SG-8002CA; Oscillator_SMD_SeikoEpson_SG210-4Pin_2.5x2.0mm

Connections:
1: J5.1, U2.20 (*MCLR)
3.3V: C5.1, C6.1, C7.1, C8.1, C9.1, C10.2, C11.1, C12.2, C13.2, C16.2, C17.2, C18.2, J5.2, L2.2, R8.2, R10.1, R10.2, U2.18 (VDD), U2.33 (VDD), U2.55 (VDD), U2.64 (VDD), U2.74 (VUSB3V3), U2.88 (VDD), U2.107 (VDD), U2.122 (VDD), U2.137 (VDD), Y1.1 (OE), Y1.4 (Vcc)
4: J5.4, U2.36 (PGED1/AN0/RPB0/RB0)
5: J5.5, U2.35 (PGEC1/AN1/RPB1/RB1)
12v: C14.2, C15.2, U5.1 (EN), U5.4 (VIN); also elsewhere on the board
D+: J1.A6 (D+), U2.77 (D+)
D-: J1.A7 (D-), U2.76 (D-)
GND: C5.2, C6.2, C7.2, C8.2, C9.2, C10.1, C11.2, C12.1, C13.1, C14.1, C15.1, C16.1, C17.1, J1.A1 (GND), J1.A12 (GND), J1.B1 (GND), J1.B12 (GND), J1.S1 (SHIELD), J5.3, R5.2, R6.1, R9.1, U2.17 (VSS), U2.32 (VSS), U2.54 (VSS), U2.63 (VSS), U2.75 (VSS), U2.89 (VSS), U2.108 (VSS), U2.123 (VSS), U2.136 (VSS), U5.2 (GND), Y1.2 (GND); also elsewhere on the board
unnamed: J1.A5 (CC1), R6.2
unnamed: J1.B5 (CC2), R5.1
unnamed: J1.A4 (VBUS), J1.A9 (VBUS), J1.B4 (VBUS), J1.B9 (VBUS), R7.2
unnamed: U2.71 (OSC1/CLKI/RC12), Y1.3 (OUT)
unnamed: C18.1, R8.1, R9.2, U5.5 (FB)
unnamed: L2.1, U5.3 (PH)
PWM: U2.70 (AN33/RPD15/SCK6/RD15); also elsewhere on the board
vbus: R7.1, U2.73 (VBUS)

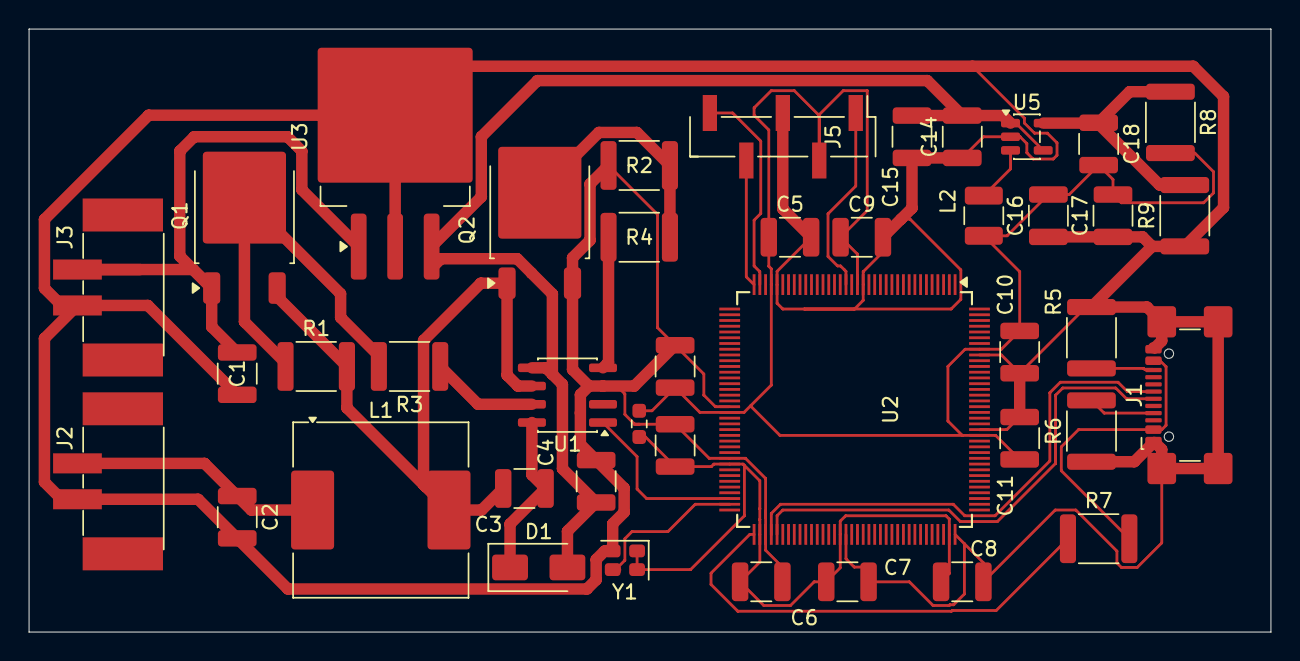
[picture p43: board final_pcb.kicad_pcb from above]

Board: 2 copper layers, 86.5 x 42.0 mm, 42 parts (0 on the bottom side), 24 nets.

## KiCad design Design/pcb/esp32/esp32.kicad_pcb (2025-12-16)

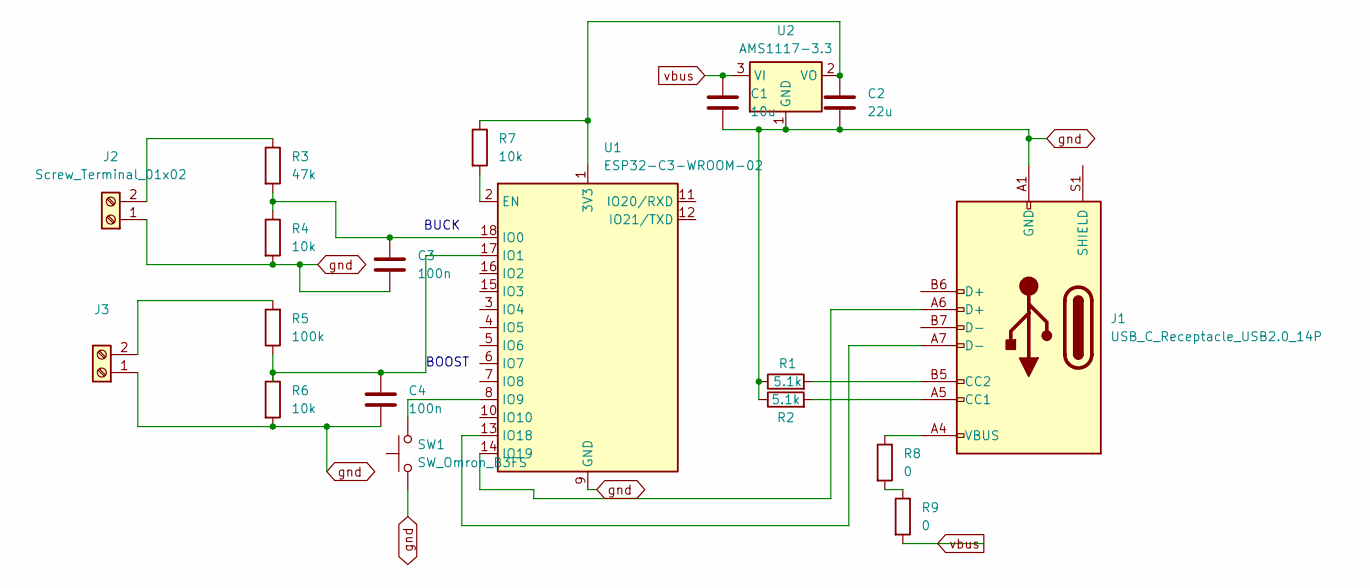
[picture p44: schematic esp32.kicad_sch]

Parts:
C1: 10u; C_0603_1608Metric
C2: 22u; C_0603_1608Metric
C3, C4: 100n; C_0603_1608Metric
J1: USB_C_Receptacle_USB2.0_14P; USB_C_Receptacle_GCT_USB4105-xx-A_16P_TopMnt_Horizontal
J2, J3: Screw_Terminal_01x02; TerminalBlock_Phoenix_MKDS-1,5-2-5.08_1x02_P5.08mm_Horizont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
R1, R2: 5.1k; R_0402_1005Metric
R3: 47k; R_0402_1005Metric
R4: 10k; R_0402_1005Metric_Pad0.72x0.64mm_HandSolder
R5: 100k; R_0402_1005Metric
R6, R7: 10k; R_0402_1005Metric
R8, R9: 0; R_1206_3216Metric
SW1: SW_Omron_B3FS; SW_SPST_Omron_B3FS-100xP
U1: ESP32-C3-WROOM-02
U2: AMS1117-3.3; SOT-223-3_TabPin2

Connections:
unnamed: J1.A5 (CC1), R2.2
unnamed: J1.B5 (CC2), R1.2
unnamed: J1.A4 (VBUS), J1.A9 (VBUS), J1.B4 (VBUS), J1.B9 (VBUS), R8.1
unnamed: J2.2, R3.1
unnamed: J3.2, R5.2
unnamed: R8.2, R9.1
unnamed: C2.1, R7.1, U1.1 (3V3), U2.2 (VO)
unnamed: R7.2, U1.2 (EN)
unnamed: C3.1, R3.2, R4.1, U1.18 (IO0)
unnamed: C4.1, R5.1, R6.1, U1.17 (IO1)
unnamed: SW1.2, U1.8 (IO9)
unnamed: J1.A7 (D-), U1.13 (IO18)
unnamed: J1.A6 (D+), U1.14 (IO19)
gnd: C1.2, C2.2, C3.2, C4.2, J1.A1 (GND), J1.A12 (GND), J1.B1 (GND), J1.B12 (GND), J2.1, J3.1, R1.1, R2.1, R4.2, R6.2, SW1.1, U1.9 (GND), U1.19 (GND), U2.1 (GND)
vbus: C1.1, R9.2, U2.3 (VI)

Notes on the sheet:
BOOST
BUCK

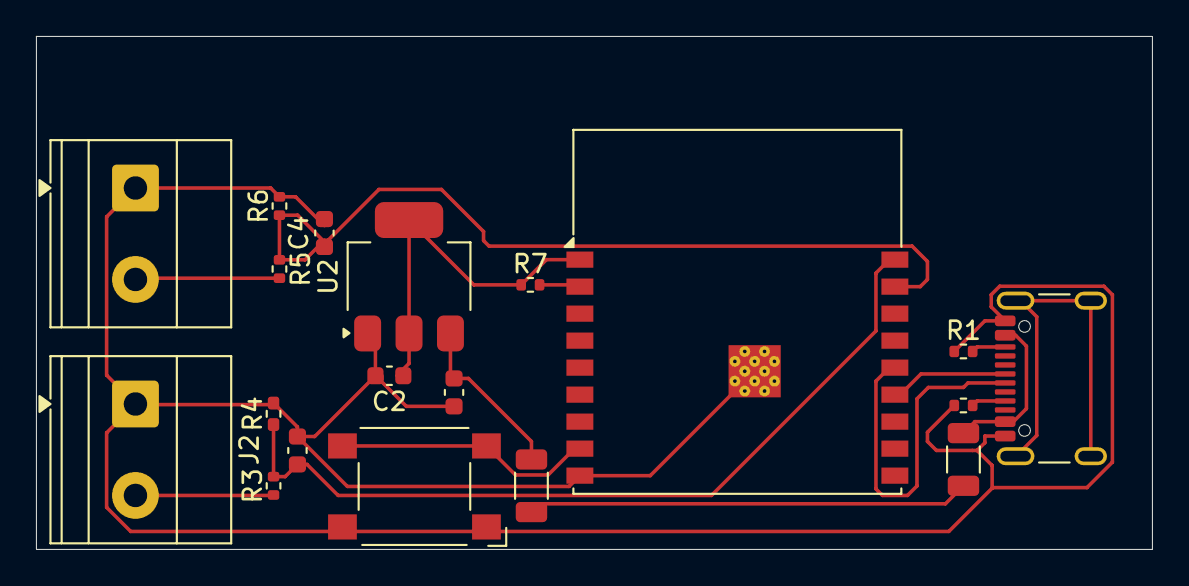
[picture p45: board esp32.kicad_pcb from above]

Board: 2 copper layers, 62.0 x 28.5 mm, 19 parts (0 on the bottom side), 15 nets.

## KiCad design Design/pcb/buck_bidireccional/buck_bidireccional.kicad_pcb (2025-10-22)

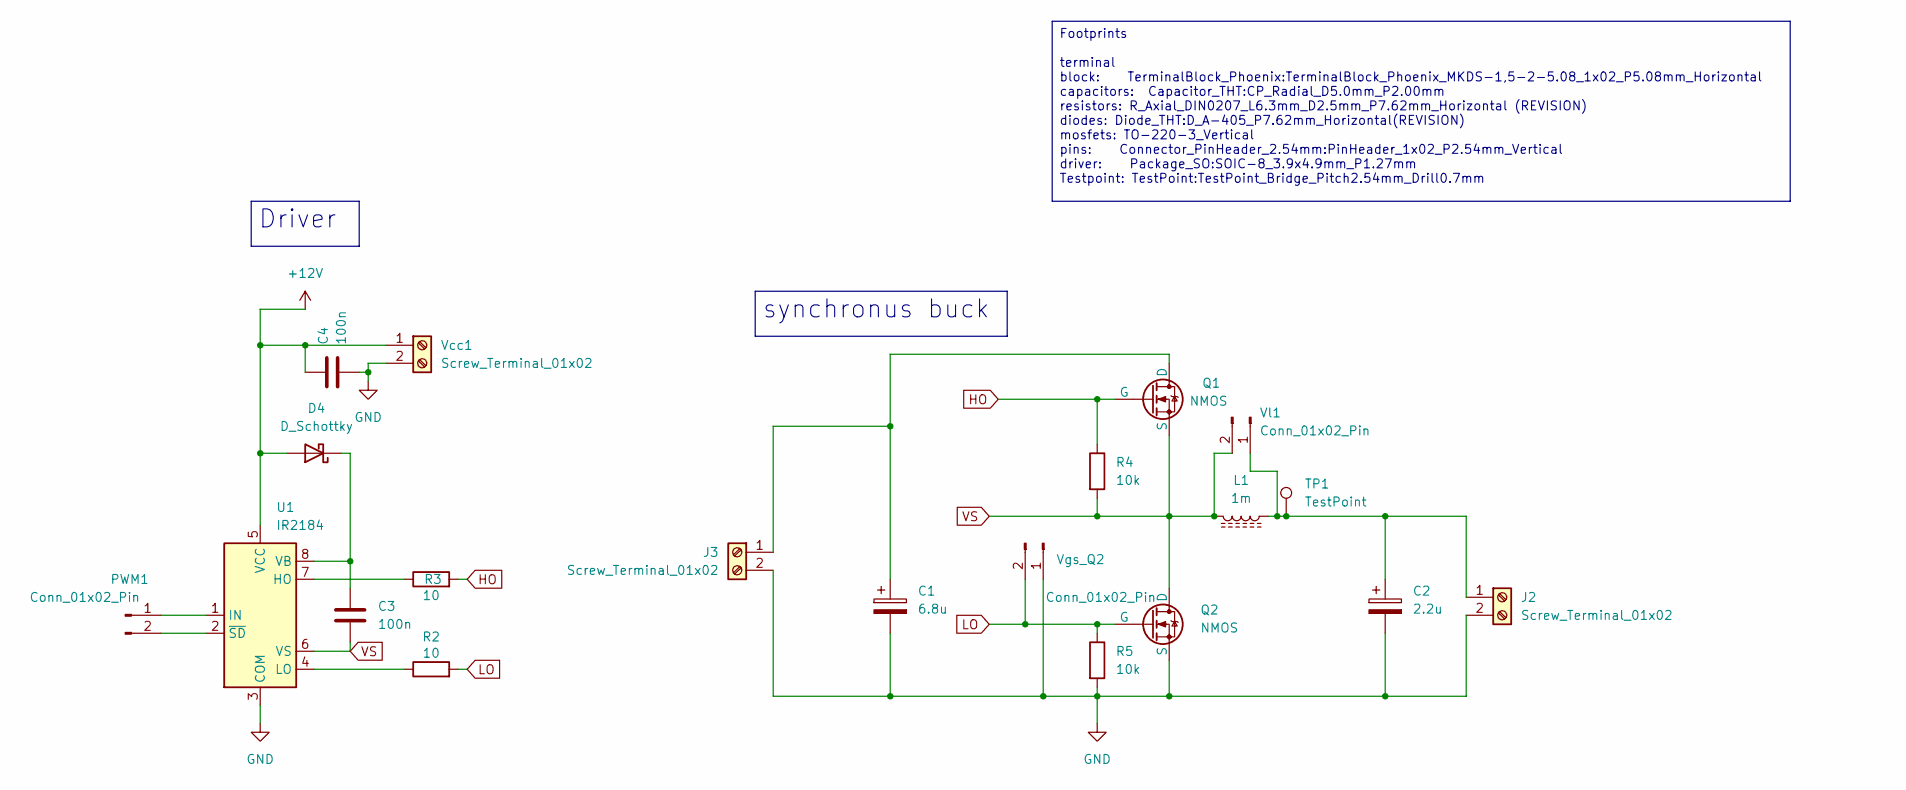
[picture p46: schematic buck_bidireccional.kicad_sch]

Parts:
C1: 6.8u; CP_Radial_D5.0mm_P2.00mm
C2: 2.2u; CP_Radial_D5.0mm_P2.00mm
C3, C4: 100n; CP_Radial_D5.0mm_P2.00mm
D4: D_Schottky; D_A-405_P7.62mm_Horizontal
J2, J3: Screw_Terminal_01x02; TerminalBlock_Phoenix_MKDS-1,5-2-5.08_1x02_P5.08mm_Horizont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
L1: 1m; buck_inductor
PWM1: Conn_01x02_Pin; PinHeader_1x02_P2.54mm_Vertical
Q1, Q2: NMOS; TO-220-3_Vertical
R2, R3: 10; R_Axial_DIN0207_L6.3mm_D2.5mm_P7.62mm_Horizontal
R4, R5: 10k; R_Axial_DIN0207_L6.3mm_D2.5mm_P7.62mm_Horizontal
TP1: TestPoint; TestPoint_Bridge_Pitch5.08mm_Drill1.3mm
U1: IR2184; SOIC-8_3.9x4.9mm_P1.27mm
Vcc1: Screw_Terminal_01x02; TerminalBlock_Phoenix_MKDS-1,5-2-5.08_1x02_P5.08mm_Horizont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
Vgs_Q2: Conn_01x02_Pin; PinHeader_1x02_P2.54mm_Vertical
Vl1: Conn_01x02_Pin; PinHeader_1x02_P2.54mm_Vertical

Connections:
+12V: C4.1, D4.2 (A), U1.5 (VCC), Vcc1.1
GND: C1.2, C2.2, C4.2, J2.2, J3.2, Q2.3 (S), R5.2, U1.3 (COM), Vcc1.2, Vgs_Q2.1
HO: Q1.2 (G), R3.2, R4.1
LO: Q2.2 (G), R2.2, R5.1, Vgs_Q2.2
unnamed: C3.1, D4.1 (K), U1.8 (VB)
unnamed: C2.1, J2.1, L1.1, TP1.1, Vl1.1
unnamed: C1.1, J3.1, Q1.1 (D)
unnamed: PWM1.1, U1.1 (IN)
unnamed: PWM1.2, U1.2 (~SD)
unnamed: R3.1, U1.7 (HO)
unnamed: R2.1, U1.4 (LO)
VS: C3.2, L1.2, Q1.3 (S), Q2.1 (D), R4.2, U1.6 (VS), Vl1.2

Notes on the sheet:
synchronus buck
Driver
Footprints terminal block: TerminalBlock_Phoenix:TerminalBlock_Phoenix_MKDS-1,5-2-5.08_1x02_P5.08mm_Horizontal capacitors: Capacitor_THT:CP_Radial_D5.0mm_P2.00mm resistors: R_Axial_DIN0207_L6.3mm_D2.5mm_P7.62mm_Horizontal (REVISION) diodes: Diode_THT:D_A-405_P7.62mm_Horizontal(REVISION) mosfets: TO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

Board: 2 copper layers, 20 parts (1 on the bottom side), 12 nets, no tracks yet.

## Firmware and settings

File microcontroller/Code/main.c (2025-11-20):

// PIC32MZ2048EFM144 Configuration Bit Settings

// 'C' source line config statements

// DEVCFG3
#pragma config USERID = 0x4742          // Enter Hexadecimal value (Enter Hexadecimal value)
#pragma config FMIIEN = ON              // Ethernet RMII/MII Enable (MII Enabled)
#pragma config FETHIO = ON              // Ethernet I/O Pin Select (Default Ethernet I/O)
#pragma config PGL1WAY = ON             // Permission Group Lock One Way Configuration (Allow only one reconfiguration)
#pragma config PMDL1WAY = ON            // Peripheral Module Disable Configuration (Allow only one reconfiguration)
#pragma config IOL1WAY = ON             // Peripheral Pin Select Configuration (Allow only one reconfiguration)
#pragma config FUSBIDIO = ON            // USB USBID Selection (Controlled by the USB Module)

// DEVCFG2
#pragma config FPLLIDIV = DIV_1         // System PLL Input Divider (1x Divider)
#pragma config FPLLRNG = RANGE_8_16_MHZ // System PLL Input Range (8-16 MHz Input)
#pragma config FPLLICLK = PLL_POSC      // System PLL Input Clock Selection (POSC is input to the System PLL)
#pragma config FPLLMULT = MUL_30        // System PLL Multiplier (PLL Multiply by 30)
#pragma config FPLLODIV = DIV_2         // System PLL Output Clock Divider (2x Divider)
#pragma config UPLLFSEL = FREQ_24MHZ    // USB PLL Input Frequency Selection (USB PLL input is 24 MHz)

// DEVCFG1
#pragma config FNOSC = SPLL             // Oscillator Selection Bits (System PLL)
#pragma config DMTINTV = WIN_127_128    // DMT Count Window Interval (Window/Interval value is 127/128 counter value)
#pragma config FSOSCEN = OFF            // Secondary Oscillator Enable (Disable SOSC)
#pragma config IESO = OFF               // Internal/External Switch Over (Disabled)
#pragma config POSCMOD = EC             // Primary Oscillator Configuration (External clock mode)
#pragma config OSCIOFNC = OFF           // CLKO Output Signal Active on the OSCO Pin (Disabled)
#pragma config FCKSM = CSECME           // Clock Switching and Monitor Selection (Clock Switch Enabled, FSCM Enabled)
#pragma config WDTPS = PS1048576        // Watchdog Timer Postscaler (1:1048576)
#pragma config WDTSPGM = STOP           // Watchdog Timer Stop During Flash Programming (WDT stops during Flash programming)
#pragma config WINDIS = NORMAL          // Watchdog Timer Window Mode (Watchdog Timer is in non-Window mode)
#pragma config FWDTEN = OFF             // Watchdog Timer Enable (WDT Disabled)
#pragma config FWDTWINSZ = WINSZ_25     // Watchdog Timer Window Size (Window size is 25%)
#pragma config DMTCNT = DMT31           // Deadman Timer Count Selection (2^31 (2147483648))
#pragma config FDMTEN = OFF             // Deadman Timer Enable (Deadman Timer is disabled)

// DEVCFG0
#pragma config DEBUG = OFF              // Background Debugger Enable (Debugger is disabled)
#pragma config JTAGEN = ON              // JTAG Enable (JTAG Port Enabled)
#pragma config ICESEL = ICS_PGx1        // ICE/ICD Comm Channel Select (Communicate on PGEC1/PGED1)
#pragma config TRCEN = ON               // Trace Enable (Trace features in the CPU are enabled)
#pragma config BOOTISA = MIPS32         // Boot ISA Selection (Boot code and Exception code is MIPS32)
#pragma config FECCCON = OFF_UNLOCKED   // Dynamic Flash ECC Configuration (ECC and Dynamic ECC are disabled (ECCCON bits are writable))
#pragma config FSLEEP = OFF             // Flash Sleep Mode (Flash is powered down when the device is in Sleep mode)
#pragma config DBGPER = PG_ALL          // Debug Mode CPU Access Permission (Allow CPU access to all permission regions)
#pragma config SMCLR = MCLR_NORM        // Soft Master Clear Enable bit (MCLR pin generates a normal system Reset)
#pragma config SOSCGAIN = GAIN_2X       // Secondary Oscillator Gain Control bits (2x gain setting)
#pragma config SOSCBOOST = ON           // Secondary Oscillator Boost Kick Start Enable bit (Boost the kick start of the oscillator)
#pragma config POSCGAIN = GAIN_2X       // Primary Oscillator Gain Control bits (2x gain setting)
#pragma config POSCBOOST = ON           // Primary Oscillator Boost Kick Start Enable bit (Boost the kick start of the oscillator)
#pragma config EJTAGBEN = NORMAL        // EJTAG Boot (Normal EJTAG functionality)

// DEVCP0
#pragma config CP = OFF                 // Code Protect (Protection Disabled)

// SEQ3
#pragma config TSEQ = 0xFFFF            // Boot Flash True Sequence Number (Enter Hexadecimal value)
#pragma config CSEQ = 0xFFFF            // Boot Flash Complement Sequence Number (Enter Hexadecimal value)

// #pragma config statements should precede project file includes.
// Use project enums instead of #define for ON and OFF.

#include <xc.h>
#include <math.h>
#include <string.h>
#include <stdio.h>

#define _XTAL_FREQ 180000000

#define TICK_PER_MS (_XTAL_FREQ/2/1000)

/*the lines above is the code genereted for the configuration bits, most of them are the default ones, the ones to note 
 * are the FNOSC and all of the DEVCFG2 register, FNOSC selects our system clock, in this case we want it to be the output
 * of the PLL cause we want the highest clock possible for the best performance, since we can go up to 200Mhz, we decided
 * on 180MHz since its divisible by 60KHz target frecuency, therefore our input divider is 1, our mult is 30 and our output
 * divider is 2, certain restriccions have to be followed for the PLL to work properly like the output of the mult cant be 
 * higher than 700MHz for example.
 * PIC32MZ Embedded Connectivity with Floating Point Unit (EF) - pag 640 
*/

void __delay_ms(uint32_t ms)
{
uint32_t Start=_CP0_GET_COUNT();
uint32_t Duration=TICK_PER_MS*ms;
while((_CP0_GET_COUNT()-Start)<Duration);
}

void __delay_us(uint32_t ms)
{
uint32_t Start=_CP0_GET_COUNT();
uint32_t Duration=TICK_PER_MS*ms/1000;
while((_CP0_GET_COUNT()-Start)<Duration);
}

void PB3and2_setup(){
//setup for the peripheral bus clock 3, which is the one that the timers and OC use.
    
//unlock sequence to change de divisor of the clk for better resolution of our PWM, 
    
//Section 42. Oscillators with Enhanced PLL-pag 29 
       
SYSKEY = 0xAA996655;
SYSKEY = 0x556699AA;

PB3DIVbits.PBDIV = 0b0000000;
PB2DIVbits.PBDIV = 0b0000000;

// closing of system unlock

SYSKEY = 0x33333333;       
}

void Timer2and3_setup(){
//setup for the timer 2, that will be used by our output compare module
//Section 14. Timers - pag 11
    
    T2CONbits.ON = 1;
    T2CONbits.TCKPS = 0b000;
    
//setup of the period register, the value is obtained via the formula to obtain the maximum resolution for our PWM
//the formula treated PR as x, FPWM as 60Khz, TPB as 1/180MHz and the prescale value as 1, therefore 2999 was obtained     
//PIC32 FRM Section 16. Output Compare - pag 28    
    
    PR2 = 2999;

    
//setup for the timer 3 that will be used by our ADC module
    
    T3CONbits.ON = 0;
    T3CONbits.TCKPS = 0b000;
    PR3 = 10;
    T3CONbits.ON = 1;

}

void OC4_setup(){
//setup for the Output compare 4 module, it has to be either this one or the number 7, cause down the line we
//will have to map it to the pwm pin of the curiosity board
 
//setup the OCxR register before pwm mode pag 26
    // should be 1% duty cycle with our PR
    OC4R = 30;
    
//PIC32 FRM Section 16. Output Compare - pag 4
    
    OC4CONbits.ON = 1;
    //select timer 2 as source since timer 3 might be used for the ADC
    OC4CONbits.OCTSEL = 0;
    //select pwm mode without fault pin
    OC4CONbits.OCM = 0b110;
      
 // test
    OC4RS = 30;

}

void ADC_setup(){
//setup for the ADC module, most of it is taken directly from code example of the datasheet
//12-bit High-Speed Successive Approximation Register (SAR) Analog-to-Digital Converter (ADC) - pag 66
//since we want to use a dedicated module ADC for class 1 (mainly because it seems easier to setup), we have to choose between
//AN0 to AN4, therefore we choose AN2 since its readily available on the cuirosity board without having to setup for of this god dam forsaken module 
//Curiosity PIC32MZ EF 2.0 Development Board Users Guide - pag 15 
    
    
    
//also we have to follow the activation sequence steps 
//PIC32MZ Embedded Connectivity with Floating Point Unit (EF) - pag 441    
    
    
//step 1 we initialize the calibration form de DEV registers
    
//PIC32MZ Embedded Connectivity with Floating Point Unit (EF) - pag 442
 ADC0CFG = DEVADC0;
 ADC1CFG = DEVADC1;
 ADC2CFG = DEVADC2;
 ADC3CFG = DEVADC3;
 ADC4CFG = DEVADC4;
 ADC7CFG = DEVADC7;    

 
//step 2 essential ADC configuration SFRs
 
 ADCCON1 = 0;
 ADCCON2 = 0; 

 ADCANCON = 0;
 ADCANCONbits.WKUPCLKCNT = 0xA; 

 ADCCON3 = 0;
 ADCCON3bits.ADCSEL = 0b00; // PB3CLK
 ADCCON3bits.CONCLKDIV = 0b000000; //idk why would we should or should not divide the input clock
 ADCCON3bits.VREFSEL = 0; // AVDD and AVSS wich are 3.3V and GND respectivly Curiosity PIC32MZ EF 2.0 Development Board Users Guide - pag 27

 ADC2TIMEbits.ADCDIV = 0b0000010; // divide the clock by 4 since the max TAD is 50Mhz, with this we get 45Mhz
 ADC2TIMEbits.SAMC = 0b0000000011; // ADC2 sampling time = 5 * TAD2, recomended for 1k resistance, honestly no clue what this value should be
 ADC2TIMEbits.SELRES = 0b11; // ADC2 resolution is 12 bits


 ADCTRGMODEbits.SH2ALT = 0; // ADC2 = AN2
 
 // AN2 will give unsiged bits, and since the medition will be against gnd we use single ended
 ADCIMCON1bits.SIGN2 = 0; // unsigned data format
 ADCIMCON1bits.DIFF2 = 0; // Single ended mode
 
 
 
 // No interrupts are used
 ADCGIRQEN1 = 0; 
 ADCGIRQEN2 = 0;
 // No scanning is used
 ADCCSS1 = 0; 
 ADCCSS2 = 0;
 // No digital comparators are used. Setting the ADCCMPCONx, register to '0' ensures that the comparator is disabled.
 ADCCMPCON1 = 0; 
 ADCCMPCON2 = 0; 
 ADCCMPCON3 = 0; 
 ADCCMPCON4 = 0;
 ADCCMPCON5 = 0;
 ADCCMPCON6 = 0;

 // No oversampling filters are used.
 ADCFLTR1 = 0; 
 ADCFLTR2 = 0;
 ADCFLTR3 = 0;
 ADCFLTR4 = 0;
 ADCFLTR5 = 0;
 ADCFLTR6 = 0;
 
 // No early interrupt
 ADCEIEN1 = 0; 
 ADCEIEN2 = 0;
 
 //The trigger source and how it triggers
 ADCTRGSNSbits.LVL0 = 0; // only on the positive edge of the trigger
 ADCTRG1bits.TRGSRC2= 0b00110; // we use timer 3 

 
 
 //step 3 turn on the adc
 ADCCON1bits.ON = 1;
 
 //step 4
 
 //Wait for voltage reference to be stable
 while(!ADCCON2bits.BGVRRDY); // Wait until the reference voltage is ready
 while(ADCCON2bits.REFFLT); // Wait if there is a fault with the reference voltage
 
 
 //step 5
 ADCANCONbits.ANEN2 = 1; // Enable the clock to analog bias
 
 
 //step 6
 while(!ADCANCONbits.WKRDY2); // Wait until ADC2 is ready
 
 //step 7 FINAL STEP FINALLY OMG
 //Digen bit is the one that enables the data conversion for the ADC
 ADCCON3bits.DIGEN2 = 1; // Enable ADC2
 
 
}

void IO_setup(){
//setup for the output of our OC module, since the board has RPD15 coneccted to the PWM pin of the mikrobus 1 and 2,
//we will map that pin to the output of a corresponding OC, therefore our only options were OC4 or OC7
//Curiosity PIC32MZ EF 2.0 Development Board Users Guide - pag 13
//PIC32MZ Embedded Connectivity with Floating Point Unit (EF) - pag 266

//set pin as output    
 TRISDbits.TRISD15 = 0;
// 1011 = OC4 
 RPD15Rbits.RPD15R = 0b1011;
 
//setup for the AN2 pin which is RB2 
 
 TRISBbits.TRISB2 = 1;
 ANSELBbits.ANSB2 = 1;
 
//setup for the uart pins altough might be unnecesary but idk
//PIC32MZ Embedded Connectivity with Floating Point Unit (EF) - pag 267 - 264
 TRISFbits.TRISF2 = 0;
 TRISFbits.TRISF13 = 1;
 ANSELFbits.ANSF13 = 0;
 RPF2Rbits.RPF2R = 0b0100;
 U6RXRbits.U6RXR = 0b1001;

 
 
 

}


void UART_setup(){
//im tired of commenting, maybe ill get back to it, you are just gonna have to trust me on this one gang
    
    
    
    U6BRG = 96;
    
    U6MODEbits.UEN = 0b00;
    
    U6STAbits.URXEN = 1;
    U6STAbits.UTXEN = 1;
    
    U6MODEbits.ON = 1;


}


long map(long x, long in_min, long in_max, long out_min, long out_max) {
//this map functioin will be used to map the output of the adc to the available value range for the OCxRS register
//it was taken directly from arduino https://docs.arduino.cc/language-reference/en/functions/math/map/ 
    
  return (x - in_min) * (out_max - out_min) / (in_max - in_min) + out_min;
}



void Non_essential_setup(){
//this is just me messing around
    
    
    //LED 0
    TRISJbits.TRISJ7 = 0;  
    LATJbits.LATJ7 = 1;    
    
    //LED 1
    TRISKbits.TRISK7 = 0;
    LATKbits.LATK7 = 1;
    //LED 2
    TRISJbits.TRISJ3 = 0;
    LATJbits.LATJ3 = 1;



}
//Author: Gian Luca Barbagelata, si esto funciona me vuelvo loco
int main(void) {
 
    PB3and2_setup();
    Timer2and3_setup();
    OC4_setup();
    //ADC_setup();
    IO_setup();
    UART_setup();
    Non_essential_setup();

    int range;
    
    int freq, duty, f_PWM = 0;
    char s[4] = {'\0', '\0', '\0', '\0'};
    char data;
    int select = 0;
    int index=0;
    double old_duty = 0;
    
    while(1){
        range = round(map(OC4RS,60,2940,0,9));
  
        //LED 2
        if (range & 0b0001) LATJbits.LATJ3 = 0;
        //LED 1
        if (range & 0b0010) LATKbits.LATK7 = 0;
        //LED 0
        if (range & 0b0100) LATJbits.LATJ7 = 0;
/*
        if (range & 0b1000){        
            LATJbits.LATJ3 = 0;
            LATKbits.LATK7 = 0;
            LATJbits.LATJ7 = 0;
            __delay_ms(100);
            LATJbits.LATJ3 = 1;
            LATKbits.LATK7 = 1;
            LATJbits.LATJ7 = 1;
            __delay_ms(100);
            LATJbits.LATJ3 = 0;
            LATKbits.LATK7 = 0;
            LATJbits.LATJ7 = 0;
        }
        
      
        __delay_ms(100);
        
        LATJbits.LATJ3 = 1;
        LATKbits.LATK7 = 1;
        LATJbits.LATJ7 = 1;
      */   
        
        while (U6STAbits.URXDA == 0);
        data = U6RXREG;
        
        if (data == 'D'){
            select = 0;
            index = 0;
            memset(s, '\0', sizeof(s));
            continue;
        }
        else if (data == 'F'){
            select = 1;
            index = 0; 
            memset(s, '\0', sizeof(s));
            continue;  
        }
        
        if (select == 0){
            s[index] = data;
            index++;
            if (index == 3){
                duty = atoi(s);
                OC4RS = round(((double)(PR2+1)/1000)*duty);
                index = 0;
                memset(s, '\0', sizeof(s));
                continue;
            }
            continue;
        }
            
        if (select == 1){
            s[index] = data;
            index++;
            if (index == 3){
                old_duty = (double)OC4RS/(PR2+1);
                freq = atoi(s);
                f_PWM = freq * 1000;
                PR2 = round(((double)_XTAL_FREQ/f_PWM) - 1);
                OC4RS = old_duty*(PR2+1);
                index = 0;
                memset(s, '\0', sizeof(s));
                continue;
            }
            continue;
        }
        
        
        /*
        while (ADCDSTAT1bits.ARDY2 == 0);
        OC4RS = round(map(ADCDATA2,0,4096,60,2940));
        
        */
        
      
        
       
    }  
        
    

    return (EXIT_SUCCESS);
    }

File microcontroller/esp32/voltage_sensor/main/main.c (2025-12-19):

// ADC math corrections.
#include "esp_adc/adc_cali.h"
#include "esp_adc/adc_cali_scheme.h"
// handles the immediate reading mode
#include "esp_adc/adc_oneshot.h"
// handles the wifi events
#include "esp_event.h"
#include "esp_wifi.h"
// for printing
#include "esp_log.h"
// to pause processes
#include "freertos/FreeRTOS.h"
#include "freertos/event_groups.h"
#include "freertos/task.h"
// UNIX sockets
#include "lwip/sockets.h"
// saves the wifi calibratio data in flash memory
#include "nvs_flash.h"
// system on chips capabilities for curve and line fitting
#include "soc/soc_caps.h"
#include <string.h>

const static char *TAG = "WIFI_SENSOR";

// --- USER CONFIGURATION ---
#define WIFI_SSID "ID"
#define WIFI_PASS "PASSWORD"
#define PC_IP_ADDR "IP" // <--- PC's IP
#define PORT 3333       // <--- Port used

// ADC Config
#define ADC_BUCK ADC_CHANNEL_6  // GPIO 34
#define ADC_BOOST ADC_CHANNEL_7 // GPIO 35
#define BUCK_RATIO 5.1279f
#define BOOST_RATIO 11.5184f

// --- Wi-Fi Boilerplate globals ---
static EventGroupHandle_t
    s_wifi_event_group; // takes values depending on the state of the
                        // connection, points to a dashboard with events
#define WIFI_CONNECTED_BIT                                                     \
  BIT0 // binary signal to read the event thats taking place

// Declare global function to use later
static bool adc_calibration_init(adc_unit_t unit, adc_channel_t channel,
                                 adc_atten_t atten,
                                 adc_cali_handle_t *out_handle);
void wifi_init_sta(void);

// --- MAIN APPLICATION ---
void app_main(void) {
  // Initialize NVS (non-voltaile storage) (Required for Wi-Fi)
  esp_err_t ret = nvs_flash_init(); // Initialize memory
  // checks if there's space, if not, it wipes the junk and tries again
  if (ret == ESP_ERR_NVS_NO_FREE_PAGES ||
      ret == ESP_ERR_NVS_NEW_VERSION_FOUND) {
    ESP_ERROR_CHECK(nvs_flash_erase());
    ret = nvs_flash_init();
  }
  ESP_ERROR_CHECK(ret); // checks for corruption

  // Start Wi-Fi
  ESP_LOGI(TAG, "Starting Wi-Fi...");
  wifi_init_sta();

  // Setup UDP Socket
  int sock = socket(AF_INET, SOCK_DGRAM,
                    IPPROTO_UDP); // addr family, datagram, protocol
  // structure
  struct sockaddr_in dest_addr;
  dest_addr.sin_addr.s_addr = inet_addr(PC_IP_ADDR);
  dest_addr.sin_family = AF_INET;
  dest_addr.sin_port = htons(PORT);

  // Setup ADC
  adc_oneshot_unit_handle_t
      adc1_handle; // declares pointer to heap with adc rules
  adc_oneshot_unit_init_cfg_t init_config = {
      .unit_id = ADC_UNIT_1}; // sets the adc unit to use
  ESP_ERROR_CHECK(
      adc_oneshot_new_unit(&init_config, &adc1_handle)); // check for errors

  adc_oneshot_chan_cfg_t config = {
      .bitwidth = ADC_BITWIDTH_DEFAULT,
      .atten = ADC_ATTEN_DB_12}; // 12 bit, atten = 3, max ~2.45 V with and
                                 // errror up to 60mV
  // config GPIO 35 & 34
  ESP_ERROR_CHECK(adc_oneshot_config_channel(adc1_handle, ADC_BUCK, &config));
  ESP_ERROR_CHECK(adc_oneshot_config_channel(adc1_handle, ADC_BOOST, &config));

  // hanles for calibration
  adc_cali_handle_t cali_handle_buck = NULL;
  adc_cali_handle_t cali_handle_boost = NULL;
  bool do_calib_buck = adc_calibration_init(ADC_UNIT_1, ADC_BUCK,
                                            ADC_ATTEN_DB_12, &cali_handle_buck);
  bool do_calib_boost = adc_calibration_init(
      ADC_UNIT_1, ADC_BOOST, ADC_ATTEN_DB_12, &cali_handle_boost);

  // MAIN LOOP
  while (1) {
    // --- READ SENSORS ---
    uint32_t sum_buck = 0, sum_boost = 0;
    int raw_buck = 0, raw_boost = 0;
    // number of samples
    int samples = 64;

    for (int i = 0; i < samples; i++) {
      // read raw value and store the total sum
      ESP_ERROR_CHECK(adc_oneshot_read(adc1_handle, ADC_BUCK, &raw_buck));
      sum_buck += raw_buck;
      ESP_ERROR_CHECK(adc_oneshot_read(adc1_handle, ADC_BOOST, &raw_boost));
      sum_boost += raw_boost;
    }

    // calculate the avg
    int avg_buck = sum_buck / samples;
    int avg_boost = sum_boost / samples;
    int mv_buck = 0, mv_boost = 0;

    // scale results to real values
    if (do_calib_buck)
      adc_cali_raw_to_voltage(cali_handle_buck, avg_buck, &mv_buck);
    else
      mv_buck = avg_buck * 2450 / 4095;

    if (do_calib_boost)
      adc_cali_raw_to_voltage(cali_handle_boost, avg_boost, &mv_boost);
    else
      mv_boost = avg_boost * 2450 / 4095;

    float v_buck = (mv_buck * BUCK_RATIO) / 1000.0f;
    float v_boost = (mv_boost * BOOST_RATIO) / 1000.0f;

    // --- SEND VIA WI-FI ---
    // Format the string "Buck: 12.50, Boost: 24.00"
    char payload[64];
    snprintf(payload, sizeof(payload), "Buck: %.2f V, Boost: %.2f V\n", v_buck,
             v_boost);

    // Send the packet
    int err =
        sendto(sock, payload, strlen(payload), 0, (struct sockaddr *)&dest_addr,
               sizeof(dest_addr)); // socket, buffer, lenght, udp, ip and port
    if (err < 0) {
      ESP_LOGE(TAG, "Error occurred during sending: errno %d", errno);
    } else {
      ESP_LOGI(TAG, "Sent: %s", payload);
    }

    vTaskDelay(pdMS_TO_TICKS(500));
  }
}

// --- WI-FI HELPERS  ---
static void event_handler(void *arg, esp_event_base_t event_base,
                          int32_t event_id, void *event_data) {
  if (event_base == WIFI_EVENT && event_id == WIFI_EVENT_STA_START) {
    esp_wifi_connect();
  } else if (event_base == WIFI_EVENT &&
             event_id == WIFI_EVENT_STA_DISCONNECTED) {
    esp_wifi_connect(); // Auto-reconnect
    ESP_LOGI(TAG, "Retrying to connect...");
  } else if (event_base == IP_EVENT && event_id == IP_EVENT_STA_GOT_IP) {
    ip_event_got_ip_t *event = (ip_event_got_ip_t *)event_data;
    ESP_LOGI(TAG, "Got IP:" IPSTR, IP2STR(&event->ip_info.ip));
    xEventGroupSetBits(s_wifi_event_group, WIFI_CONNECTED_BIT);
  }
}
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

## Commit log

2025-08-28 Add files via upload
    SWITCHES simulation
2025-08-28 Create kicadhere
2025-08-29 Create Convertidor bUCK bIDIRECCIONAL.slx
2025-08-31 NACHO
    simulink circuito
2025-08-31 Nacho
    Mathcad del buck bidireccional
2025-08-31 sim en proteus con driver
2025-08-31 Nacho
    Agreado osciloscopio para medicion de voltaje de gates
2025-08-31 Nacho
    Agregada referencia de libro EPO
2025-09-01 nACHO
    agregada la referencia del libro
2025-09-01 Nacho
    Analisis de casos, se obtuvo:
    para modo buck Vomax=12.9[V]
    para modo Boost Vomax=30[V]
2025-09-02 Nacho
    Cambios de valores
2025-09-02 Nacho
    Documento con componentes
    [Componentes.xlsx]
2025-09-02 datasheet update
    added possible driver datasheet
2025-09-03 adjust 1% voltage ripple
2025-09-04 update mathcad, Rpd calcs
    100kohm pulldown resistor calc
2025-09-04 kicad first try
    pcb aint pcbing yet
2025-09-04 Updated kicad
    still needs fixes
    [buck_bidireccional.kicad_pcb, buck_bidireccional.kicad_sch, buck_bidireccional_copy.kicad_pcb]
2025-09-05 updated pcb
    [buck_bidireccional.kicad_pcb, buck_bidireccional.kicad_sch]
2025-09-05 updates kiskas
    [buck_bidireccional.kicad_pcb, buck_bidireccional.kicad_sch]
2025-09-06 Parte teorica del MOSFET
    Lo más basico, voy complementando a medida que avance
2025-09-07 Teoria del mosfet
    FUNCIONAMIENTO DETALLADO DEL MOSFET
2025-09-08 Cambios a MOSFET real
    Se ajusto al mosfet IRFZ44N y agregado valores de capacitores a utilizar
2025-09-08 Cambio a un duty de 60% en Boost
2025-09-09 update kicad
    [buck_bidireccional.kicad_pcb, buck_bidireccional.kicad_sch, buck_bidireccional_copy.kicad_pcb]
2025-09-09 Coloqué mediciones de componentes en proteus
2025-09-09 Agregué calculos del numero de vueltas de la bobina
2025-09-09 updated kicad
    MOSFET gate oscilloscope reading still missing
    [buck_bidireccional.kicad_pcb, buck_bidireccional.kicad_sch]
2025-09-09 Agregado un voltemeter
2025-09-11 final update pcb
    [buck_bidireccional.kicad_pcb, buck_bidireccional.kicad_sch, test.kicad_sch]
2025-09-11 kicad pdf
    [buck_bidireccional.kicad_sch]
2025-09-11 final kicad
    [buck_bidireccional.kicad_pcb, buck_bidireccional.kicad_sch, test.kicad_sch]
2025-09-11 g1 to g2
    [buck_bidireccional.kicad_pcb]
2025-09-12 Meh
    No me acuerdo que eran
2025-09-12 final pcb
    [buck_bidireccional.kicad_pcb, buck_bidireccional.kicad_sch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]
2025-09-15 update kicad + gerber
    [buck_bidireccional.kicad_pcb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]
2025-09-15 mathcad correction
    [buck_bidireccional.kicad_pcb]
2025-09-23 Carta Gantt
    [Carta Gantt.xlsx]
2025-09-24 Orden de la simulacion y agregado de capacitancias parasitas
2025-09-24 Eleccion de VDSMAX en MOSFETS
2025-09-25 removed non needed resistors
    [buck_bidireccional.kicad_pcb, buck_bidireccional.kicad_sch]
2025-09-25 fixed ids
    [buck_bidireccional.kicad_pcb]
2025-09-26 a lot of stuff
    [buck_bidireccional.kicad_pcb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]
2025-09-27 schem update
    [buck_bidireccional.kicad_pcb]
2025-09-27 update for pcbway
    [Carta Gantt.xlsx, Componentes.xlsx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]
2025-10-01 fixed kicad error
    [buck_bidireccional.kicad_pcb, buck_bidireccional.kicad_sch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]
2025-10-10 edited gate resistors out due to them being fed by external vcc, ESR values must be re-checked
2025-10-12 fixed pcb
    [buck_bidireccional.kicad_pcb, buck_bidireccional.kicad_sch]
2025-10-18 Enhance README with prototyping section and BOM
    Added a new section on prototyping and updated BOM details in the README.
2025-10-18 Update README with circuit powering instructions
    Added a section on powering the circuit and measuring efficiency.
2025-10-21 Fix power values in efficiency table
    Updated input and output power values for 45% and 65% duty cycles in the efficiency table.
2025-10-21 Add note on ceramic capacitors for voltage ripple
    Added note about using ceramic capacitors for voltage ripple issues.
2025-10-21 Improve README with updated images and PWM control section
    Updated image alt text for clarity and added a new section on PWM control.
2025-10-22 updates to kicad
    [buck_bidireccional.kicad_pcb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]
2025-10-24 Ppt de la presentacion y excel con datos teoricos y practicos
    [Convertidor.xlsx]
2025-11-07 First teste graphical interface using arduino nano
2025-11-07 Fix comment formatting for dutyCycle variable
    [test_arduino_nano_PWM.ino]
2025-11-11 proyecto PIC32 de cuando se hizo en microelectronica
2025-11-20 code para la el pic con la gui
2025-11-23 fixed frozen buttons
2025-11-23 Revise PWM generation flowchart and system clock details
    Updated the flowchart for PWM generation steps and clarified the system clock generation process.
2025-12-03 start final pcb
    [BOM_pcb.ods, final_pcb.kicad_pcb, final_pcb.kicad_sch]
2025-12-03 Cambio a slider de frecuencia
2025-12-03 Correccion de días en la gantt
    [Carta Gantt.xlsx]
2025-12-04 Final_pcb changes
    [BOM_pcb.ods, final_pcb.kicad_pcb, untitled.kicad_sch]
2025-12-04 Borrado un archivo x
    [final_pcb.kicad_pcb, final_pcb.kicad_sch]
2025-12-08 added esp32 adc
2025-12-10 Sim con divisor de voltaje
2025-12-10 Correcciones de ESR en sim sin divisor
2025-12-10 Multisim para el divisor de voltaje
2025-12-10 Agregao de amperimetros
2025-12-10 Agregado calculos de divisor de voltaje
2025-12-11 pcb bom
    [BOM_pcb.ods]
2025-12-16 Valores obtenidos de practica
    [Convertidor.xlsx]
2025-12-16 temp changes
    [esp32.kicad_pcb, esp32.kicad_sch]
2025-12-18 Agregado de presentaciones
2025-12-18 Final budget
    [BOM_pcb.ods]
2025-12-19 cambios de todo
    [Convertidor.xlsx]
2025-12-22 pcb fix
    [final_pcb.kicad_pcb, final_pcb.kicad_sch]
2026-01-06 erase material
